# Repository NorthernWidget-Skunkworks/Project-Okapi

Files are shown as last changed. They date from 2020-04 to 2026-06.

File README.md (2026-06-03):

# Okapi: Data logger with integrated solar charging and modular telemetry


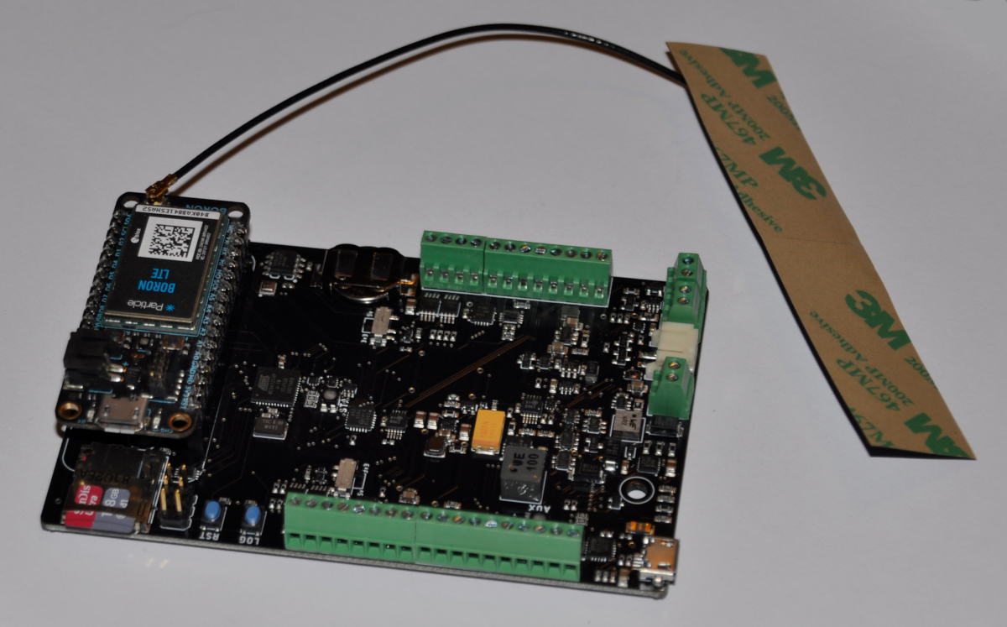
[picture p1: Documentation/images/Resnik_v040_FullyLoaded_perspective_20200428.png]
Project Okapi Data Logger.


***Okapi data logger (Resnik v0.4.0), with a micro-SD card for local storage and a Particle Boron telemetry module.***

The **Okapi** data logger responds to the need for a robust, flexible, and power-efficient open-source option to record and transmit data from remote locations. It is programmable using the open-source standard Arduino framework via a standard micro-USB cable and supports a wide range of sensor input/output options. It connects to dual power supplies to ensure consistent recordings, and interfaces with a range of “Feather”-form-factor boards for telemetry.

## Namesake

The Okapi, a relative of the giraffe, communicates over long distances using [infrasound](https://en.wikipedia.org/wiki/Infrasound). The telemetry capabilities of this data logger inspired this namesake.

Okapi

## Technical specifications

### Electronic Hardware

* Microcontroller (computer) core
  * ATMega1284p
  * Arduino compatible
  * Programmable using C++
  * 8 MHz
* Real-time clock
  * DS3231M
  * Temperature-compensated crystal for high accuracy (±5 ppm)
* Sensor and general-purpose connections
  * Primary Rail (selectable 3.3V or 5V)
    * I2C (up to 128 sensors permitted; expansion ports provided by Project Heptapod)
    * SPI
    * 2x 16-bit analog
    * Analog voltage reference
    * 12-bit Digital-to-analog conversion
    * 2x General-purpose input/output
    * USART
    * 2x Vbus (selectable 3.3V or 5V)
    * 2x Ground
  * Secondary Rail (selectable 3.3V or 5V)
    * I2C (up to 128 sensors permitted; expansion ports provided by Project Heptapod)
    * 2x 16-bit analog
    * 2x General-purpose input/output
    * USART
    * 2x Vbus (selectable 3.3V or 5V)
    * 2x Ground
* Data storage and return
  * Local storage: micro SD card
  * Telemetry: support for Feather-profile boards, including Particle devices:
    * Mobile phone networks
    * WiFi
    * Bluetooth
    * [In development] Iridium satellite
* Power
  * Dual power supply
  * Primary Power
    * Built-in maximum-power-point-tracking solar-charge-control circuitry
    * Lithium-Ion battery
  * Backup Power
    * Alkaline AA batteries
  * Real-time clock
    * Coin cell
  * Power consumption
    * Primary power, sleeping: 80 μA
    * Backup power, sleeping: 4 μA
    * Active (typical: data logger without sensors): 10 mA
    * Transmitting (mobile networks, typical: Particle Boron):
      * 16 mA background
      * 40 mA burst
  * Power generation
  * Solar, low light: 100 mA
* User interface
  * “Log” button: instantaneous reading (for testing)
  * “Reset” button
  * 2x 3-color indicator LEDs
  * Computer readout via a serial monitor, included in the Arduino software
* Open-source licensing via CC BY-SA 4.0

>> @bschulz1701: Any updates needed? I think that there is also a WDT (correct?)

### Electronic Software and Firmware

* Programmable using the Arduino IDE https://www.arduino.cc/en/main/software
* Custom bootloader and board definition for ATMega1284p available via https://github.com/NorthernWidget/Arduino_Boards
* Custom libraries from Northern Widget and the open-source community
  * Primary data-logger functions
  * Libraries available with each sensor, exposing a standard interface
* Open-source licensing via GNU GPL 3.0

### Pinout and board interfaces

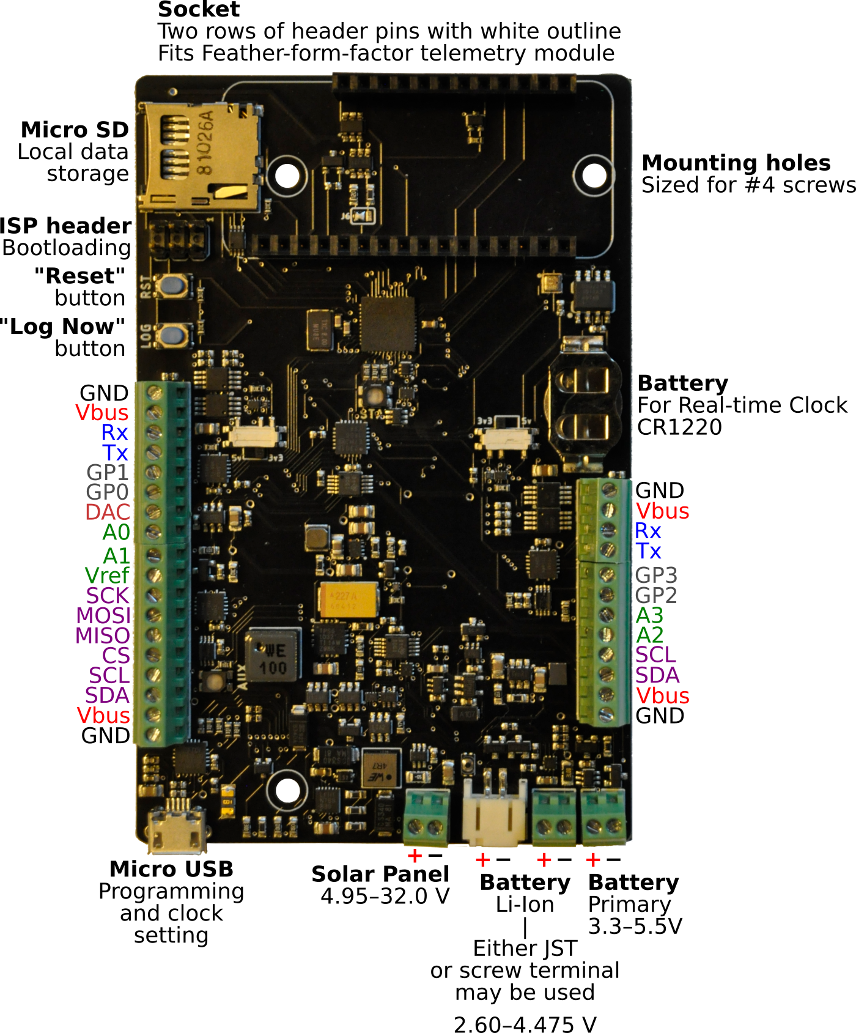
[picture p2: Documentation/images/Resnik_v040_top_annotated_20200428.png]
Data logger with pins, connectors, and interactive items annotated.


***Okapi data logger (Resnik v0.4.0) with pins, connectors, and interactive items annotated.***

**Pins are colored following this convention:**
* Ground: black
* Power supply: red
* Universal Serial Asynchronous Receiver--Transmitter (USART or UART): blue
* General-purpose I/O pins: gray
* Analog inputs and associated reference voltage: green
* Digital communications buses (SPI and I2C): purple
* Analog adjustable voltage output: salmon

**The power and programming connectors at the "south" end of the board are as follows:**
* Micro-USB connector
  * The same connector as many Android and other mobile phones at the time of writing; may be programmed using any USB cable for these that is not charging-only (i.e. that can carry data)
  * Can be used with our [clock-setting program](https://github.com/NorthernWidget/SetTime_GUI) to set the time on the real-time clock.
  * Provides power to the data logger while it is connected; this power source is isolated from the batteries and solar panel, and therefore may be plugged in safely at any time.
* Solar panel, 4.95--32.0 V. A wide range of panels can work with this.
* Li-Ion battery, 2.60--4.475 V. This works with standard 18650 Li-ion batteries. It can work well with just a single battery, but if more storage is required, multiple 18650 batteries may be connected in parallel; we have a circuit-board design to do this: https://github.com/NorthernWidget/LiIon-18650-Parallel. ***CAUTION***: most commercially available multiple-18650-battery holders connect them in series; this voltage is ***TOO HIGH*** for the data logger.
* Primary batteries. This is ideally a pack of 3 primary (i.e., not reusable) Alkaline (or better) AA batteries with a long shelf life. The Okapi data logger will switch to these if its rechargeable power supply shuts down. The internal electronics reduce the quiescent power consumption while under backup power (see the above list of [electronic hardware technical specifications](#electronic-hardware)) and inform the logger about which power supply is being used, allowing it to, for example, reduce or temporarily terminate data transmission.

>> @bschulz1701: Solar panel supply current / size?

**"RST" and "LOG" buttons:**
* Reset ("RST"): stop the program that is currently executing on the main logger and return it to its boot sequence.
* Log Now ("LOG"): take a reading immediately. This is useful for diagnoses and testing.

>> General note: we may want to have an LED flash whenever the logger takes a reading -- even for 1/10 of a second. With an option to disable this, of course. But it is often better to know while in the field that a system is working

**Other notes, clockwise from the top:**
* The socket holds a [Feather-form-factor board](https://learn.adafruit.com/adafruit-feather/feather-specification).
  * This standard, designed by [Adafruit](https://www.adafruit.com/), has been widely adopted, including by the IoT/telemetry module designer [Particle](https://www.particle.io/).
  * We often use a [Particle Boron mobile-phone telemetry unit](https://docs.particle.io/boron/).
* Mounting holes for [\#4 screws](https://www.mcmaster.com/91772A106/)
* CR1220 battery; can power the real-time clock for up to 7 years
* ISP header (also called an ICSP header): This 3x2 header is used with an in-system programmer (in-circuit system programmer) to upload the (bootloader)[#installing-the-bootloader] to the data logger.
* A micro-SD card holds a copy of all data, whether or not any telemetry is used

>> @bschulz1701: check my clock 7-year figure

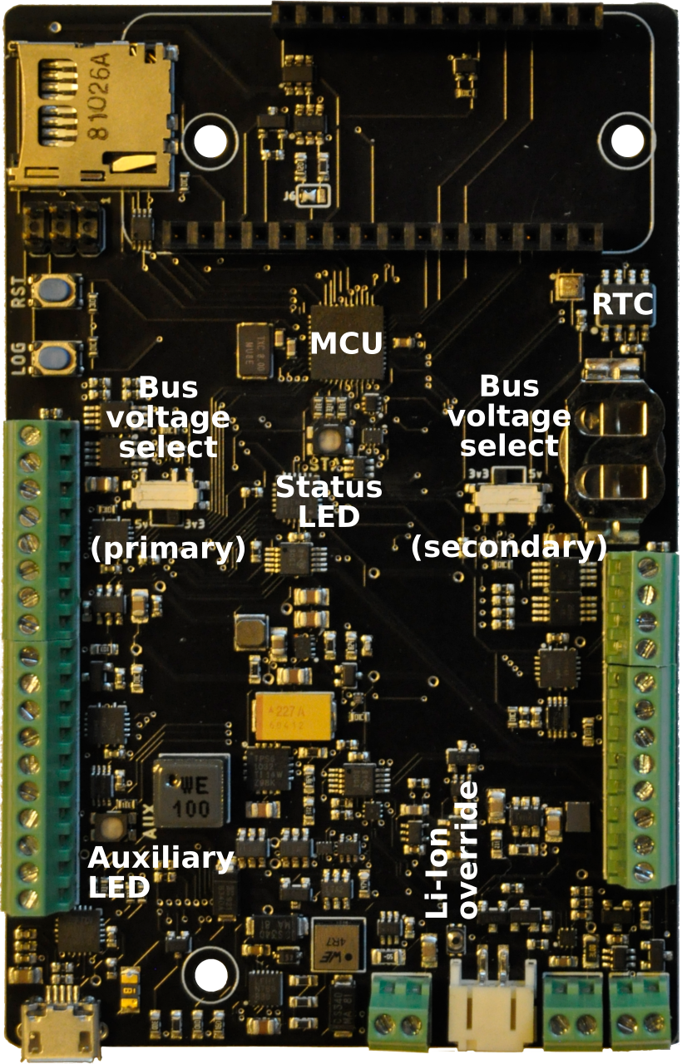
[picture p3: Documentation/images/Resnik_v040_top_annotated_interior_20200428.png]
Data logger with key microchips, LEDs, and switches marked.


***Okapi data logger (Resnik v0.4.0) with key microchips, LEDs, and switches marked.*** *MCU: Microcontroller. RTC: Real-time clock. LED: Light-emitting diode. Bus: a subsystem for connections and data transfer.*

The Okapi data logger contains two buses (see above), each of which has an independent voltage. The primary bus is on the left and the secondary bus is on the right. These can be selected as 3.3V (switches slid towards the inside of the board) or 5V (switches towards the outside of the board).

>> @bschulz1701: How much power can each bus source/sink?

Two LEDs, status and auxiliary, flash messages to the user to provide information on proper operations vs. a variety of possible errors. These are useful for field diagnoses, and are further described in [the field guide section, below](#field-guide).

>> Design note: move STAT label to left of LED so it can be better seen

The Li-ion override button, which can be pressed with the tip of a pen or other small object, ...

>> @bschulz1701: This somehow overrides the Li-Ion battery electronics to allow something to happen... but I am not remembering what!

## On-board Devices

### I2C

| **Device** 	| **Default address** 	| **Reprogrammable address** 	| **Function** 	|
|---	|---	|---	|---	|
| [DS3231](https://github.com/NorthernWidget/DS3231_Logger) 	| 0x68 	| N 	| Real-time clock 	|
| [MCP23018](https://github.com/NorthernWidget-Skunkworks/MCP23018) 	| 0x20 	| N 	| I/O Expander 	|
| [ADS1115](https://github.com/adafruit/Adafruit_ADS1X15) 	| 0x48 	| N 	| ADC (on-board devices) 	|
| [ADS1115](https://github.com/adafruit/Adafruit_ADS1X15) 	| 0x49 	| N 	| ADC (off-board devices) 	|
| [MCP4725](https://github.com/NorthernWidget-Skunkworks/MCP4725) 	| 0x62 	| N 	| DAC 	|
| [BME280](https://github.com/NorthernWidget/BME_Library) 	| 0x77 	| N 	| On-board barometric pressure, temperature, and relative humidity 	|

### SPI

* SD Card

### UART (USART)

* FTDI USB-Serial converter
* Feather form-factor telemetry board; typically [Particle Boron](https://docs.particle.io/boron/)

## Assembly

Assembling this data logger is possible by hand with sufficient skill and the following tools:
* Temperature-controlled soldering iron
* Hot-air rework station
* Equipment for stenciling with solder paste
* ESD-safe tweezers and workstation
* Solder wick

Mechanized assembly by a professional circuit-board assembly house, which is available in many parts of the world, may be preferred due to the complexity of this data logger board.

>> THOUGHT: I have basic instructions for assembly on the [Project Walrus](https://github.com/NorthernWidget-Skunkworks/Project-TPDH-Walrus) README; I will not reproduce these here just yet, as we might want to set up a separate assembly guide, mostly with good links to existing resources, since our writing something of this nature would be to reinvent the wheel.

## Programming

### Downloading and installing the Arduino IDE

Go to https://www.arduino.cc/en/main/software. Choose the proper IDE version for your computer. For Windows, we suggest the non-app version to have more control over Arduino; this might change in the future. You will have to add custom libraries, so the web version will not work (at least, as of the time of writing). Download and install the Arduino IDE. Open it to begin the next steps.

### Installing the bootloader

Before a data logger can receive programs via the convenient USB port, it must have a *bootloader* that tells it to expect to receive new programs that way.  You can read more about bootloaders in general here: https://www.arduino.cc/en/Hacking/Bootloader.

Because you can't upload the bootloader via USB, you use the 2x3-pin 6-pin ICSP (also called ISP) header with a special device called an "in-circuit system programmer" (or just "in-system programmer; yup, that's what the acronym stands for).

Many devices exist to upload a bootloader including:
* The official [AVR ISP mkII](http://ww1.microchip.com/downloads/en/DeviceDoc/Atmel-42093-AVR-ISP-mkII_UserGuide.pdf) (no longer produced but available used)
* Using an [Arduino as an ISP](https://www.arduino.cc/en/tutorial/arduinoISP)
* The versatile [Olimex AVR-ISP-MK2](https://www.olimex.com/Products/AVR/Programmers/AVR-ISP-MK2/open-source-hardware)
* The [Adafruit USBtinyISP](https://www.adafruit.com/product/46)

To upload the bootloader, do the following:

1. Open the Arduino IDE. If you have not yet installed the Northern Widget board definitions, find and install them here (instructions provided): https://github.com/NorthernWidget/Arduino_Boards
2. Select the desired board -- most likely ***ATMega1284p 8MHz*** under *Northern Widget Boards*.
3. Plug the data logger into your computer via a micro-USB cable to provide power.
4. Plug your ISP of choice into your computer (via a USB cable) and onto the 6-pin header. There are two ways to place it on; the header is aligned such that the ribbon cable should be facing away from the board while programming. If this fails without being able to upload, try flipping the header around.
5. Go to Tools --> Programmer and select the appropriate programmer based on what you are using.
6. Go to Tools --> Burn bootloader. Typically, within a few seconds, you learn whether you succeeded or failed. Hopefully it worked!

***Important note for Linux users:*** You must supply permissions to the Arduino IDE for it to be able to use the ICSP, or you will have to run it using `sudo`. The former option is better; the latter is easier in the moment.

***Note: Be sure to download and/or update drivers for your ISP.***

### Installing the requisite software libraries

>> @awickert: Add a full list of the requisite software to install; finish the firmware aggregator and use those directions (or the Arduino ones) to help users install that + sdfat. Include screenshots and host those directions at https://github.com/NorthernWidget-Skunkworks/Firmware-Aggregator.

### How to write a program

The below program is an example that you can copy and paste directly into the Arduino IDE in order to upload to your data logger. We'll walk you through what each piece of the code is and does.

#### Full program
```c++
/*
 * Okapi example: connected with a Walrus pressure--temperature sensor, often
 * used for water-level measurements, via the Longbow I2C/RS-485 translator.
 * Written by Bobby Schulz with a few comments added by Andy Wickert.
 */

#include "Okapi.h"
#include <TP_Downhole_Longbow.h>

TP_Downhole_Longbow Walrus; // Instantiate Walrus sensor; relict library name
Okapi Logger; // Instantiate data logger object

String Header = ""; // Information header; starts as an empty string
uint8_t I2CVals[1] = {0x22}; // I2C addresses of sensors

unsigned long UpdateRate = 60; // Number of seconds between readings

void setup() {
  Header = Header + Walrus.GetHeader();
  Logger.begin(I2CVals, sizeof(I2CVals), Header); // Pass header info to logger
  Init();
}

void loop() {
  Logger.run(Update, UpdateRate);
}

String Update()
{
  Init();
  delay(1500);
  return Walrus.GetString();
}

void Init()
{
  Walrus.begin(13, 0x22); // Instantiate Walrus (at address = 13)
                          // and Longbow Widget (at address = 0x22)
}
```

#### "Include" statements

```c++
#include "Okapi.h"
#include <TP_Downhole_Longbow.h>
```

These bring in the two code libraries involved, the former for the data logger and the latter for the sensors. This allows the user to access the classes and functions within these two libraries, as we will show in more detail below.

#### Instantiate a sensor object

```c++
TP_Downhole_Longbow Walrus; // Instantiate Walrus sensor; relict library name
Okapi Logger; // Instantiate data logger object
```

"Instantiating an object" means that we create our own specific versions of the a class of items. This can be thought of as: `Breakfast myBreakfast`. Breakfast is the general concept, but I create "myBreakfast", which I can then modify. In this same way, "Logger" is what we call our Okapi data logger, and "Walrus" is what we call our "TP_Downhole_Longbow" sensor; this name is a holdover from an earlier design that is the ancestor of the Walrus. We can then access functions and variables within these two instantiated objects.

#### Declare the header string

```c++
String Header = ""; // Information header; starts as an empty string
```

We start with an empty header, but will soon add information to it.

#### Create a list of the I2C addresses of the sensors

```c++
uint8_t I2CVals[1] = {0x22}; // I2C addresses of sensors
```

This is the trickiest step. You need to know what the I2C address of your sensor is. You can skip this, but then the logger will not run a check to see if the sensor is properly connected.

>> Let's make sure that we record this one each page, or find a way to replace this.

#### Declare the amount of time between logging events

```c++
unsigned long UpdateRate = 60; // Number of seconds between readings
```

This is the number of seconds between logging events. If it takes 2 seconds to record data, make sure that you give the logger at least 3 seconds between events. The maximum logging time is set by the watchdog timer, which [FINISH HERE]

>> @BSCHULZ1701: Is there an external WDT on Okapi?

#### `setup()` step: runs once at the start

```c++
void setup() {
  Header = Header + Walrus.GetHeader();
  Logger.begin(I2CVals, sizeof(I2CVals), Header); //Pass header info to logger
  Init();
}
```

`setup()` is a special function that runs just once when the logger boots up. In this case, it first adds the Walrus' header to the header string. `GetHeader()` is a standard function that lies within each of our sensor libraries and returns this header information as a `String`. We then pass the header and the I2C values to the Okapi library's `begin()` function. This sets up the header and prepares the data loger to record data. Finally, this function calls `Init()`, which we skip ahead to describe immediately below.

>> (awickert): I still don't understand why we have to pass `sizeof()` and can't just compute that within the function.

#### `Init()` function: skipping ahead to understand `setup()`

```c++
void Init()
{
  Walrus.begin(13, 0x22); // Instantiate Walrus (at address = 13)
                          // and Longbow Widget (at address = 0x22)
}
```

The `Init()` function calls the `begin()` function, standard within each Northern Widget sensor library, to instantiate the connection ports (e.g., I2C, RS-485) used to communicate between the sensor and the logger. In this case, there is only one sensor, but two ports are needed: An RS-485 signal goes from the Walrus to the Longbow Widget, which then converts the signal into an I2C signal with its own address. The reason for this is that an I2C signal can travel only ~3 m, but an RS-485 signal can travel ~100 m.

#### `loop()` step: keeps running until stopped

```c++
void loop() {
  Logger.run(Update, UpdateRate);
}
```

The loop calls the main function of the Okapi library, `run()`, repeatedly. This puts the logger into a low-power sleep mode and wakes it up only when interrupted by the clock or the "LOG" button. `Update` refers to the function described immediately below. `UpdateRate` is our logging interval defined above.

#### `Update()` function: Gives data for the logger to record

```c++
String Update()
{
  Init();
  delay(1500);
  return Walrus.GetString();
}
```

The `Update()` function first calls the `Init()` function to be sure that the sensor is ready to log. It then in this case delays 1500 milliseconds; this is an ad-hoc solution to the question of how long it takes the pressure transducer to settle after being started up, and is a safe large amount of time. This function then can `return` a string of all of the Walrus' readings (one pressure and two temperature measurements) separated by commas. This is then concatenated to a list of logger-internal measurements -- date/time; on-board temperature, pressure, and relative humidity; and onboard voltages for battery and solar-panel status -- and recorded to the SD card. If telemetry were present, these data could also be sent to a remote location.

### Reference

A full index of the public variables and functions within the Okapi data logger library is available at https://github.com/NorthernWidget/Okapi_Library.

>> Send user to library page

>> Thoughts: We should make all comments compatible with doxygen (following) what I did with the ALog library. It also looks like TravisCI has support for Arduino(!) This means that we could also automate construction of the documentation for these libraries.

### Integration with Particle Boron

>> @bschulz1701?

## Wiring

>> Example needed

## Power supply

* **Lithium-ion 18650 rechargeable batteries**; this board can hold two in parallel: https://github.com/NorthernWidget/LiIon-18650-Parallel
* **Solar panel**. A wide range is acceptable, but we like [Voltaic Systems' 6-watt panel](https://voltaicsystems.com/6-watt-panel/). If you do not want to snip off the barrel jack, [this extension plug from Adafruit should work](https://www.adafruit.com/product/2788) (though we have not tested it... and you'll also have to cut *it* in half).
* **Primary alkaline batteries**; we typically use three high-quality (e.g., Duracell) AAs. These are the backup power supply, and we place them in a [3xAA holder (in series for the proper voltage) with a switch](https://www.jameco.com/z/SBH-331-AS-R-3x-AA-Battery-Holder-with-Cover-and-Switch_216144.html).

>> @bschulz1701: new smarter 18650 holder?

## Housing

The below suggestions encompass what we use and suggest for the housing. In the end, any sufficiently waterproof enclosure will work.

### Materials

* **Enclosure**: [PolyCase WH-16-03 outdoor-rated hinged enclosure](https://www.polycase.com/wh-16)
* **Cable glands**: [RDC07AA](https://www.elecdirect.com/catalogsearch/result/?q=RDC07AA). One per sensor, plus one for the solar panel.
>> AW: Photo didn't take; look up
* **Fasteners**
  * [M5-0.8 x 10 mm truss head screws](https://www.mcmaster.com/92467A320/) x4 to attach mounting plate to threaded inserts in the enclosure
  * [\#4-40 x 1/4 in pan head screws](https://www.mcmaster.com/91772A106/) x22 to attach Okapi, battery packs, and mounting plate to standoffs
  * [\#4-40 x 2 in Female Threaded Hex Standoffs](https://www.mcmaster.com/91115A173/) x3 to stand off Okapi from mounting plate
  * [\#4-40 x 1/2 in Female Threaded Hex Standoffs](https://www.mcmaster.com/91920A533/) x8 to stand off AA battery pack and Li-Ion battery pack from mounting plate
* **Mounting plate for Okapi** (Milled, ABS)
  * [Mounting Plate Design](Mounting%20Plate)
* **Power**
>> Solar panel
  * [3x AA battery pack BK-1280-PC6](https://www.digikey.com/en/products/detail/mpd-memory-protection-devices/BK-1280-PC6/1640076) for alkaline battery backup, mounting holes included for #4-40 screws
>> Li-Ion battery and holder

### Tools

* CNC mill and/or drill press
* Deburring tool or knife + skill and patience
* Torque wrench(es) for 1.0, 1.2 N m

### Assembly

>> Guide with photos. Perhaps ask @superchap123 to use his CNC

>> Placeholder for Now

>> Also include information on passing wiring through

## Field operator's guide

### Initialize
1. Ensure that all connections are secure and SD card is inserted
2. Turn battery pack on
3. Wait for GREEN - GREEN - 5x Blue Flash
	- If you see this, the logger is properly recording data. To double-check, go to "Check"
	- If you see a different flash pattern, go to "Error"

### Check
1. After going through "Initialize", wait 2-3 minutes
2. Follow the instructions in the "Download" section
3. Check to make sure that all the data are being recorded at the proper (UTC) time
4. Check that valid values are being recorded for sensors
7. Whether or not files are properly recorded, return to "Initialize"
	- If files are not recorded, replace the SD card, check all connections, turn the logger back
	  on, and try again
	- If there is an issue with a specific sensor, check connections and troubleshoot
	- If files are recorded properly, return to Initilaize and do not return to "Check"

### SD card swap
1. Turn battery pack off
2. Remove SD card. Ensure that it is labeled. Put it somewhere safe and memorable
3. Replace the SD card with an equivalently labeled SD card
4. Go to "Initialize"

### Download
1. Turn battery pack off
2. Remove SD card
3. Insert SD card in computer
4. Navigate in the SD card to the most recent "log" file (NW→<serial_number>→Log<number>.txt)
5. Save the data file in a well-labeled and organized place.
6. Safely eject the SD card from the computer
7. Go to "Initialize"

### Error

#### Status Codes

The first LED (AUX) will turn green so long as power is applied.
The second LED (STAT) will have one of the colors below.

**Green:**: All systems check out OK, logging will proceed

**Orange:**: A sensor system is not registering properly, some sensor data may be missing or incorrect
* Verify correct polarity of sensor connection
* Ensure the right sensor is connected
* Verify the screw terminals are well connected to the wires (a loose connection can cause a failure)
* Make sure battery power is applied, some sensors can fail otherwise

**Cyan:**: Clock time is incorrect, but logger is otherwise working correctly
* Connect the logger to a computer and reset the clock using the Northern Widget Time Set GUI
* Start Processing
* Open the Northern Widget Time Set program
* Note and record the wrong time if the logger has been out in the field, alongside the current (correct) time, to correct the prior measurements
* Click the "set time" button and check that you are <3 seconds off of the correct time
* Click the "close" button

**Pink**: (looks like purple to some people): SD card is not inserted
* Insert the SD card, or remove and re-insert to make sure card is fully seated

**Red**: Critical on board component is not functioning correctly, such as SD card or clock; Logging will likely not be able to proceed
* Attempt power cycle
* Try different SD card
* Disconnect all sensors; reconnect one by one and check

**Yellow, Fast Blinking**: <50% battery capacity
* Replace batteries: turn battery pack off, replace batteries, and turn battery pack back on

**Red, Fast Blinking**: Batteries <3.3V. Voltage too low to properly function
* Replace batteries: turn battery pack off, replace batteries, and turn battery pack back on.

#### General tips to solve many kinds of errors
* Turn the the logger off and on
* Verify the quality of all screw terminal connections by gently tugging on the wires and making sure they stay in place, if not, remove, replace, and re-tighten the connection
* Ensure sensors and/or cables are not damaged, this can result is shorts or other problems
* Make sure batteries have sufficient voltage to run the logger (>3.3 V)

## NW-Device-Specification schema

Okapi's serial number scheme is [Schema 0](https://github.com/NorthernWidget/NW-Device-Specification) — the same 8-byte EEPROM block used by Margay, predating the formal specification. Schema 1 formalizes it as Page 0 and defines a putative Page 1 for the case where Okapi communicates its status to a higher-level device (e.g., the Particle Boron telemetry board). **Okapi has no current peripheral interface; Page 1 is hypothetical.**

Over I²C this would follow the standard register-addressed read. Over UART (the current Okapi↔Boron link) a framing layer is required; see the [NW-Device-Specification transport section](https://github.com/NorthernWidget/NW-Device-Specification) for the Magic Preamble and COBS options.

### Current EEPROM serial number (Schema 0)

Eight bytes at `EEPROM[length−8]` through `EEPROM[length−1]`, big-endian uint16 per field, written by the setup sketch `SN Set` command — identical scheme to Margay:

| Bytes | Field | Example (Okapi v1.0) |
|---|---|---|
| 0–1 | Board type | `0x4F01` (`'O'` = 0x4F, revision 1) |
| 2–3 | Group ID | operator-assigned |
| 4–5 | Unique ID | monotonically increasing |
| 6–7 | FirmwareID | `0x0000` (hardcoded) |

Legacy units manufactured as "Resnik" carry board type `0x9950`.

### Proposed register layout (NW-Device-Specification Schema 1)

**Page 0 (0x00–0x1F) — Identity (EEPROM)**

```
Block 0 (0x00–0x07)   Core identity
  0x00        0x01                          Schema (NW-Device-Specification v1)
  0x01–0x05   'O','k','a','p','i'           Device name (5 bytes)
  0x06–0x07   0x00,0x00                     Reserved

Block 1 (0x08–0x0F)   Version
  0x08        HW major
  0x09        HW minor
  0x0A        FW patch
  0x0B–0x0D   0x00,0x00,0x00               Unused (combined repo convention)
  0x0E–0x0F   0x00,0x00                    Reserved

Block 2 (0x10–0x17)   Serial number
  0x10–0x11   0x4F,0x01                    Board type ('O'=0x4F, revision index)
  0x12–0x13   [manufacture]                Group ID
  0x14–0x15   [manufacture]                Unique ID
  0x16–0x17   0x00,0x00                    FirmwareID (legacy, reserved)

Block 3 (0x18–0x1F)   Integrity + administration
  0x18–0x1C   0x00 ×5                      Reserved
  0x1D        0x00                         Magic byte (reserved; purpose TBD)
  0x1E        [computed]                   CRC-8 of bytes 0x00–0x1D
  0x1F        0x00                         Peripheral address (unassigned;
                                           Okapi is currently controller only)
```

**Page 1 (0x20–0x3F) — Logger status (SRAM) — HYPOTHETICAL**

Okapi is currently an I²C controller communicating with the Particle Boron via UART; it has no peripheral interface. This layout is proposed for the case where Okapi reports status to the Boron (or any higher-level device) using the NW schema. A natural peripheral address would be `0x4F` (ASCII `'O'`).

Okapi's dual power system (LiPo primary + solar charging + AA backup) differs from Margay. Full power monitoring signals are not yet implemented in the library (`GetPowerStats()` is reserved); fields marked TBD will be defined when that work is completed.

```
Block 0 (0x20–0x27)   System status + power
  0x20        Status       bit 0=ready, bit 1=SD fault, bit 2=RTC fault,
                           bit 3=onboard fault, bit 4=sensor fault,
                           bit 5=LiPo warning, bit 6=LiPo error,
                           bit 7=backup warning
  0x21        LiPo %       uint8, 0–100
  0x22–0x23   LiPo voltage uint16, 0.01 V
  0x24–0x25   Solar input  uint16, TBD (V or mW pending GetPowerStats() impl.)
  0x26–0x27   Backup volt  uint16, 0.01 V (AA backup rail)

Block 1 (0x28–0x2F)   BME280 — onboard environment
  0x28–0x29   Temperature  int16, 0.01 °C
  0x2A–0x2B   Humidity     uint16, 0.01 %RH
  0x2C–0x2F   Pressure     uint32, 0.01 hPa

Block 2 (0x30–0x37)   DS3231M — RTC
  0x30–0x33   Timestamp    uint32, Unix time (seconds since 1970-01-01 UTC)
  0x34–0x35   Temperature  int16, 0.01 °C
  0x36–0x37   Reserved

Block 3 (0x38–0x3F)   Logger state
  0x38–0x39   Ext interrupts  uint16, accumulated count
  0x3A–0x3B   Log file #      uint16
  0x3C–0x3F   Log interval    uint32, seconds
```

No Page 2. Calibration constants are hardcoded in the library.

## Development namesake

Designing a large-platform, multi-power-system, and telemetry-enabled data logger is the single most complex task that our group has undertaken. Bobby Schulz, lead engineer, code-named the dev version of this work "Project Resnik", after Dr. Judy Resnik, electrical engineer and astronaut. Although we don't have to manage the complexities of space travel, we think that our design will do pretty well down here on Planet Earth.

Astronaut Dr. Judy Resnik

## Acknowledgments

Support for this project provided by:

UMN ESCI

USGS

WMO

<br/>
<br/>
<br />This work is licensed under a <a rel="license" href="http://creativecommons.org/licenses/by-sa/4.0/">Creative Commons Attribution-ShareAlike 4.0 International License</a>.

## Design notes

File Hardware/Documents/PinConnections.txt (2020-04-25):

Project Resnik Pin Connections

uC	32 GPIO
---
I2C:
	SDA
	SCL
		SDA_CTRL

SPI:
	MOSI 
	MISO
	SCK
		SD_CS

UART:
	TX0
	RX0
	TX1
	RX1

Interrupt:
	Global Interrupt (Input, PCINT)
	LogButton (Input, PCINT)	--PA4 (FIXEDish) //Keep convention w/Margay, not hardcore fixed
	RTCInt (Input, Interrupt)

LEDs:
	AliveLED
	RedLED
	GreenLED
	BlueLED

SD, CardDected (Input)
HP Ctrl, C0 (Output)		--PC2 (FIXED)
HP Ctrl, C1 (Output)		--PC3 (FIXED)
BusPowerSwitch, Primary Bus, EN (Output)	--PC6 (Flex)
BusPowerSwitch, Secondary Bus, EN (Output) 	--PC7 (Flex)

GPIO0, Primary Bus (I/O)	--PD4 (FIXED)
GPIO1, Primary Bus (I/O)	--
GPIO2, Secondary Bus (I/O)	--PB3 (FIXED)
GPIO3, Secondary Bus (I/O)	--

Feather, GPIO 	--PA5
Feather, CTS  	--PA6
Feather, RTS	--PA7

IO Exp	16 GPIO
------
-

Feather PowerOn (Output)
ADC, OnBoard, Alert/RDY (Input, Interrupt)
ADC, OffBoard, Alert/RDY (Input, Interrupt)

LevelShifter, Primary Bus, EN (Output)
LevelShifter, Secondary Bus, EN (Output)
BusPowerSwitch, Primary Bus, Fault (Input)
BusPowerSwitch, Secondary Bus, Fault (Input)

MPPT, CHRG (Input)
MPPT, FAULT (Input)
MPPT, SHDN (Output)
Vusb (Input)
BMS, CTR (Output)
HighPowerBoost, LBO (Input, Interrupt?)
HighPowerBuck, PG (Input)
LowPowerLDO_3v3, PG (Input)

ADC Onboard
-----------

I_MPPT
I_Bat
V_Prime
V_Li

ADC Offboard
------------

A0
A1
A2
A3

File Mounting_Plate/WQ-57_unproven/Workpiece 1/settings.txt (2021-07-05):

Material type: ABS
Material dimensions: 254.99999999999997 mm x 165 mm x 3.175 mm
Bit: 0.0625 in, Upcut

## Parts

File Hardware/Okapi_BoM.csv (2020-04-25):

Qty | Value | Device | Package | Parts | Description | DIGIKEY | DISP | MF | MFP | MOUSER | MPN | PROD_ID | VALUE | VALUE_PART
3 |  | CONN_022.54_SCREW | 1X02_2.54_SCREWTERM | J5, J6, J7 | Genaric 2 terminal header | ED10561-ND |  | OnShore |  |  | OSTVN02A150
1 |  | CONN_102.54_SCREW | 1X10_SCREW | J2 | Genaric 10 terminal header | ED10567-ND |  | On Shore |  |  | OSTVN10A150
1 |  | DIODEDO-214AC | DO214AC | D9 | Genaric Diode | B340A-FDICT-ND |  | Diodes Incorporated |  |  | B340A-13-F
2 |  | DIODEDO-214AC | DO214AC | D1, D3 | Genaric Diode | CMSH3-40MATR13CT-ND |  | Central Semiconductor |  |  | CMSH3-40MA TR13
1 |  | DIODESOD-323 | SOD323-R | D2 | Genaric Diode | CMDSH2-3CT-ND |  | Central Semiconductor |  |  | CMDSH2-3 TR
1 |  | JST_2MM_MALE | JST-2-SMD | J8 | JST 2MM MALE RA CONNECTOR | 455-1749-1-ND |  | JST |  |  | S2B-PH-SM4-TB(LF)(SN)
2 |  | LM40402.5 | SOT23-3 | D6, D7 | LM4040 - Precision Micropower Shunt Voltage Referance | 576-1047-1-ND |  | Microchip |  |  | LM4040DYM3-2.5-TR
1 |  | LT3652DD | DFN_12_3X3 | U4 | LT3652 - Power Tracking Battery Charger for Solar Power (MPPT) | LT3652EDD#PBF-ND |  | LT |  |  | LT3652EDD#PBF
3 |  | MOUNTING_HOLE4_NP | 4_40 | H1, H2, H3 | Genaric Mechanical Mounting Hole
1 |  | R-EU_10KR0402 | R0402 | R54 | RESISTOR, European symbol | 311-10.0KHRCT-ND |  | Yageo |  |  | RC0603FR-0710KL |  |  | 10k
19 | 0.1uF | C-EU0.1UFC0402 | C0402 | C12, C17, C21, C25, C26, C27, C28, C29, C31, C32, C33, C34, C35, C36, C37, C38, C39, C44, C45 | CAPACITOR, European symbol | 490-4759-1-ND |  | Murata |  |  | GCM155R71C104KA55D
2 | 0.22uF | C-EU0.22UFC0402 | C0402 | C15, C16 | CAPACITOR, European symbol | 490-12265-1-ND |  | Murata |  |  | GRT155R61E224KE01D
2 | 1.62M | R-EU_1.62MR0603 | R0603 | R2, R4 | RESISTOR, European symbol | RMCF0603FT1M62CT-ND |  | Stackpole |  |  | RMCF0603FT1M62 |  |  | 1.62M
1 | 100R | R-EU_100R0402 | R0402 | R14 | RESISTOR, European symbol | 311-100LRCT-ND |  | Yageo |  |  | RC0402FR-07100RL |  |  | 100
6 | 100k | R-EU_100KR0402 | R0402 | R23, R57, R58, R60, R61, R63 | RESISTOR, European symbol | 311-100KLRCT-ND |  | Yageo |  |  | RC0402FR-07100KL |  |  | 100k
1 | 100k | R-EU_100KR0603 | R0603 | R69 | RESISTOR, European symbol | RC0402FR-071ML |  | Yageo |  |  | RC0603FR-07100KL |  |  | 100k
1 | 100uF | CTANT_EU1206 | C1206_TANT | C43 | Genaric Tantalum Capacitor | 718-1921-1-ND |  | Vishay Sprague |  |  | TL8A0107M010D
8 | 10k | R-EU_10KR0402 | R0402 | R24, R25, R41, R45, R46, R47, R52, R67 | RESISTOR, European symbol | 311-10.0KHRCT-ND |  | Yageo |  |  | RC0603FR-0710KL |  |  | 10k
2 | 10k | R-EU_P10KR0603 | R0603 | R49, R50 | RESISTOR, European symbol | P10KDBCT-ND |  | Panasonic |  |  | ERA-3AEB103V |  |  | 10k
5 | 10uF | C-EU10UFC0805 | C0805 | C3, C4, C14, C22, C30 | CAPACITOR, European symbol | 490-6473-6-ND |  | Murata |  |  | GRM21BR61C106KE15K
1 | 10uH | INDUCTORXHMI_6.65X6.45 | WE-XHMI(6.65X6.45) | L2 | Genaric inductor | 732-10707-1-ND |  | Wurth |  |  | 74439346100
1 | 120k | R-EU_120KR0402 | R0402 | R19 | RESISTOR, European symbol | 311-120KLRCT-ND |  | Yageo |  |  | RC0402FR-07120KL |  |  | 120k
2 | 12pF | C-EU12PFC0402 | C0402 | C23, C24 | CAPACITOR, European symbol | 445-5585-1-ND |  | TDK |  |  | CGA2B2C0G1H120J050BA
2 | 12pF | C-EU12PFC0402 | C0402 | C40, C41 | CAPACITOR, European symbol | 1276-1254-1-ND |  | Samsung |  |  | CL10C120JB8NNNC
1 | 130k | R-EU_130KR0603 | R0603 | R20 | RESISTOR, European symbol | 311-130KHRCT-ND |  | Yageo |  |  | RC0603FR-07130KL |  |  | 130k
1 | 143k | R-EU_143KR0603 | R0603 | R22 | RESISTOR, European symbol | 311-143KHRCT-ND |  | Yageo |  |  | RC0603FR-07143KL |  |  | 143k
2 | 180k | R-EU_180KR0402 | R0402 | R65, R66 | RESISTOR, European symbol | 311-180KLRCT-ND |  | Yageo |  |  | RC0402FR-07180KL |  |  | 180k
4 | 180k | R-EU_180KR0603 | R0603 | R1, R5, R7, R8 | RESISTOR, European symbol | P180KHCT-ND |  | Panasonic |  |  | ERJ-3EKF1803V |  |  | 180k
1 | 182k | R-EU_182KR0603 | R0603 | R13 | RESISTOR, European symbol | P182KHCT-ND |  | Panasonic |  |  | ERJ-3EKF1823V |  |  | 182k
6 | 1M | R-EU_1MR0402 | R0402 | R53, R55, R56, R59, R64, R68 | RESISTOR, European symbol | 311-1.00MLRCT-ND |  | Yageo |  |  | RC0402FR-071ML |  |  | 1M
1 | 1M | R-EU_1MR0603 | R0603 | R71 | RESISTOR, European symbol | P1.00MHCT-ND |  | Panasonic |  |  | ERJ-3EKF1004V |  |  | 1M
1 | 1k | R-EU_1KR0402 | R0402 | R12 | RESISTOR, European symbol | 311-1.00KLRCT-ND |  | Yageo |  |  | RC0402FR-071KL |  |  | 1k
1 | 1uF | C-EU0.1UFC0402 | C0402 | C42 | CAPACITOR, European symbol | 1276-6524-1-ND |  | Samsung |  |  | CL10B105MO8NNWC
2 | 1uF | C-EU1UFC0603 | C0603 | C11, C13 | CAPACITOR, European symbol | 490-10479-1-ND |  | Murata |  |  | GRM188R61C105KA12D
1 | 1uH | INDUCTORLQS_3X3 | WE-LQS(3X3) | L3 | Genaric inductor | 732-5491-1-ND |  | Wurth |  |  | 74404032010
1 | 20 | R-EU_20R0402 | R0402 | R11 | RESISTOR, European symbol | 311-20LRCT-ND |  | Yageo |  |  | RC0402FR-0720RL |  |  | 20
1 | 200k | R-EU_200KR0603 | R0603 | R70 | RESISTOR, European symbol | 311-200KHRCT-ND |  | Yageo |  |  | RC0603FR-07200KL |  |  | 200k
1 | 20k | R-EU_20KR0603 | R0603 | R51 | RESISTOR, European symbol | 311-20.0KHRCT-ND |  | Yageo |  |  | RC0603FR-0720KL |  |  | 20k
1 | 220uF | CTANT_EU2917 | C2917 | C5 | Genaric Tantalum Capacitor | 478-5408-1-ND |  | AVX |  |  | TPSY227K010R0100
7 | 22uF | C-EU22UFC0805 | C0805 | C2, C7, C8, C9, C10, C19, C20 | CAPACITOR, European symbol | 490-9952-1-ND |  | Murata |  |  | GRM219R61C226ME15L
2 | 27 | R-EU_27R0402 | R0402 | R34, R35 | RESISTOR, European symbol | YAG3086CT-ND |  | Yageo |  |  | RC0402FR-0727RL |  |  | 27
4 | 287R | R-EU_232R0402 | R0402 | R26, R27, R28, R29 | RESISTOR, European symbol | YAG3063CT-ND |  | Yageo |  |  | RC0402FR-07232RL |  |  | 232
4 | 287R | R-EU_453R0402 | R0402 | R30, R31, R32, R33 | RESISTOR, European symbol | YAG3165CT-ND |  | Yageo |  |  | RC0402FR-07453RL |  |  | 453
3 | 2N7002 | MOSFET-NCH-2N7002PW | SOT323 | Q4, Q7, Q8 | N-channel MOSFETs | 2N7002W-FDICT-ND |  | Diodes Incorporated |  |  | 2N7002W-7-F | TRANS-11151 | 2N7002
1 | 2k | R-EU_2KR0402 | R0402 | R15 | RESISTOR, European symbol | 311-2KLRCT-ND |  | Yageo |  |  | RC0402FR-072KL |  |  | 2k
2 | 330 | R-EU_330R0402 | R0402 | R37, R39 | RESISTOR, European symbol | 311-330HRCT-ND |  | Yageo |  |  | RC0603FR-07330RL |  |  | 330
1 | 330 | R-EU_330R0402 | R0402 | R9 | RESISTOR, European symbol | 311-330LRCT-ND |  | Yageo |  |  | RC0402FR-07330RL |  |  | 330
6 | 330 | R-EU_330R0402 | R0402 | R36, R38, R40, R42, R43, R44 | RESISTOR, European symbol | 311-330LRCT-ND |  | Yageo |  |  | RC0603FR-07330RL |  |  | 330
1 | 10k | R-EU_10K0603 | R0603 | R48 | RESISTOR, European symbol | 311-10.0KHRCT-ND |  | Yageo |  |  | RC0603FR-0710KL |  |  | 10k
2 | 330k | R-EU_330KR0603 | R0603 | R17, R62 | RESISTOR, European symbol | P330KHCT-ND |  | Panasonic |  |  | ERJ-3EKF3303V |  |  | 330k
1 | 360k | R-EU_360KR0603 | R0603 | R3 | RESISTOR, European symbol | 311-360KHRCT-ND |  | Yageo |  |  | RC0603FR-07360KL |  |  | 360k
1 | 3m | R-EU_0.003R0805 | R0805 | R10 | RESISTOR, European symbol | RHM.003AJCT-ND |  | Rohm |  |  | PMR10EZPFV3L00
1 | 4.7uF | C-EU4.7UFC0805 | C0805 | C1 | CAPACITOR, European symbol | 399-7415-1-ND |  | Kemet |  |  | C0805C475K4RACTU
1 | 4.7uH | INDUCTORMAIA_4.1X4.1 | WE-MAIA(4.1X4.1) | L4 | Genaric inductor | 732-11316-1-ND |  | Wurth |  |  | 78438356047
1 | 470k | R-EU_470KR0603 | R0603 | R21 | RESISTOR, European symbol | 311-470KGRCT-ND |  | Yageo |  |  | RC0603JR-07470KL |  |  | 470k
1 | 50m | R-EU_0.05R0805 | R0805 | R18 | RESISTOR, European symbol | P50LLCT-ND |  | Panasonic |  |  | ERJ-L06KF50MV
1 | 6.8uH | INDUCTOR1008 | 1008 | L1 | Genaric inductor | 732-4849-1-ND |  | Wurth |  |  | 74438323068
1 | 68pF | C-EU68PFC0402 | C0402 | C6 | CAPACITOR, European symbol | 732-7474-1-ND |  | Wurth |  |  | 8.85012E+11
1 | 820k | R-EU_820KR0603 | R0603 | R6 | RESISTOR, European symbol | 311-820KGRCT-ND |  | Yageo |  |  | RC0603JR-07820KL |  |  | 820k
1 | 91k | R-EU_91KR0603 | R0603 | R16 | RESISTOR, European symbol | P91.0KHCT-ND |  | Panasonic |  |  | ERJ-3EKF9102V |  |  | 91k
2 | ADS1115 | ADS1115 | VSSOP_10 | U32, U33 | ADS1115 - Sigma Delta ADC | 296-38849-1-ND |  | TI |  |  | ADS1115IDGSR
1 | ATMEGA1284M | ATMEGA1284M | MLF44-TH | IC1 | 8-bit Microcontroller with 128K Bytes In-System Programmable Flash | ATMEGA1284P-MURCT-ND |  | Atmel |  |  | ATMEGA1284P-MUR
1 | AVRISP-6 | AVRISP-6 | AVRISP | ISP1 | AVR ISP HEADER | 609-3234-ND |  | Amphenol |  |  | 67997-206HLF
1 | BAT54C | BAT54C | SOT23-3 | D8 | BAT54C | BAT54CLT1GOSCT-ND |  | ON Semiconductor | BAT54CLT1G
1 | BATTERY_COIN12MM | BATTERY_COIN12MM | LINX_BAT-HLD-012-SMT | BT1 | Coin Cell Battery Holder | BAT-HLD-012-SMT-ND |  | Linx |  |  | BAT-HLD-012-SMT
1 | BME280 | BME280 | BME280 | U31 | BME280 - Combined Digital Humidity and Pressure Sensor | 828-1063-1-ND | BME280 | Bosch |  |  | BME280
1 | BQ2980RUG | BQ2980RUG | RUG_S-PQFP-N8 | U5 | BQ2980 - Voltage, Current, Temperature Protectors with an Integrated High-Side NFET (BMS) | 296-47578-1-ND |  | TI |  | 595-BQ298000RUGT | BQ298000RUGT
1 | BUTTON2.6X1.6 | BUTTON2.6X1.6 | SWITCH_2.6X1.6 | S5 | Genaric SPST Pushbutton | P19888CT-ND |  | Panasonic |  |  | EVP-BB2A9B000
2 | BUTTON4.2X3.2 | BUTTON4.2X3.2 | SWITCH_4.2X3.2 | S3, S4 | Genaric SPST Pushbutton | CKN10504CT-ND |  | C&K |  |  | PTS810 SJG 250 SMTR LFS
2 | CLVBA-FKA | CLVBA-FKA | CLVBA-FKA | D4, D5 | Cree RGB LED, Small Package, Common Anode, CLVBA-FKA | CLVBA-FKA-CAEDH8BBB7A363CT-ND |  | Cree |  |  | CLVBA-FKA-CAEDH8BBB7A363
1 | CONN_42.54_SCREW | CONN_42.54_SCREW | 1X04_SCREW | J3 | Genaric 4 terminal header | ED10563-ND |  | On Shore |  |  | OSTVN04A150
2 | CONN_82.54_SCREW | CONN_82.54_SCREW | 1X08_SCREW | J1, J4 | Genaric 8 terminal header | ED10566-ND |  | On Shore |  |  | OSTVN08A150
1 | CRYSTAL8MHZ5X3.2 | CRYSTAL8MHZ5X3.2 | CRYSTAL_5X3.2_2-SMD | XTAL1 | Crystal Oscilator | 887-1740-1-ND |  | TXC |  |  | 7A-8.000MAAE-T
3 | DMG3404 | MOSFET-NCH-DMG3404L | SOT23-3 | Q1, Q2, Q6 | N-channel MOSFETs | DMG3404L-7DICT-ND |  | Diodes Incorporated |  |  | DMG3404L-7 |  | DMG3404
1 | DS3231M | DS3231M | SO08 | RTC1 | DS3231M Real Time Clock | DS3231MZ+-ND |  | Maxim |  |  | DS3231MZ+
2 | FDN360P | MOSFET_PCH-FDN360P | SOT23-3 | Q3, Q5 | P-channel MOSFETs | FDN360PCT-ND |  | Fairchild |  |  | FDN360P |  | FDN360P
1 | FEATHERWINGLAYOUT | FEATHERWINGLAYOUT | FEATHERWING_MIN | MS1
1 | FT231X-Q | FT231X-Q | QFN20 | U23 | FT231x - USB to UART Bridge | 768-1128-1-ND |  | FTDI |  |  | FT231XQ-R
1 | INA211DCK | INA211DCK | DCK_R-PDSO-G6 | U34 | INA21x - Analog Output Current Sense Amplifier | 296-40126-1-ND | INA211 | TI |  |  | INA211BIDCKR
1 | INA213DCK | INA213DCK | DCK_R-PDSO-G6 | U35 | INA21x - Analog Output Current Sense Amplifier | 296-40129-1-ND | INA213 | TI |  |  | INA213BIDCKR
7 | JUMPER-SMT_2_NO_SILK | JUMPER-SMT_2_NO_SILK | SMT-JUMPER_2_NO_SILK | JP1, JP2, JP3, JP4, JP5, JP6, JP7 | Normally open jumper
1 | JUMPER-SMT_3_1-NC_PASTE_SILK | JUMPER-SMT_3_1-NC_PASTE_SILK | SMT-JUMPER_3_1-NC_PASTE_SILK | JP8 | Normally closed solder jumper (1 of 2 connections)
1 | LTC4412S6 | LTC4412S6 | SOT23-6L | U7 | LTC4412 - Low Loss PowerPath Controller (ORing FET Controller) | LTC4412ES6#TRPBFCT-ND |  | LT |  |  | LTC4412ES6#TRPBF
1 | MCP23018QFN | MCP23018QFN | QFN24 | U41 | MCP23018 - I2C I/O Expander, 16 bit wtih interrupt and reset | MCP23018T-E/MJCT-ND |  | TI |  |  | MCP23018T-E/MJ
1 | MCP4726A2SOT-23 | MCP4726A2SOT-23 | SOT23-6L | U30 | MCP4726x - 8/10/12 Bit Digital to Analog Converter | MCP4726A2T-E/CHCT-ND | MCP4726A2 | Microchip |  |  | MCP4726A2T-E/CH
4 | MIC2544MSOP | MIC2544MSOP | MSOP_8 | U17, U18, U19, U20 | MIC2544/48 - Hight Side Load Switch, with Adjustable Current Limit | 576-1738-5-ND |  | Microchip |  |  | MIC2544-1YMM
1 | MIC94094C6 | MIC94094C6 | SC-70_6 | U39 | MIC9409x - Hight Side Load Switch | 576-3492-1-ND | MIC94094 | Microchip |  |  | MIC94094YC6-TR
1 | MICROSDCD | MICROSDCD | MICROSD_CD | SD1 | Micro-SD / Transflash card holder with SPI pinout | WM19093CT-ND |  | Molex |  |  | 5025700893
1 | MICRO_USB_LONGPADS | MICRO_USB_LONGPADS | 10118194-0001LF_10118194-0001LF_LONGER_PADS | USB1 |  | 609-4618-1-ND |  | Amphenol |  |  | 10118194-0001LF
1 | PPTC1.5A | PPTC1.5A | 1206 | F1 | Resettable Fuse PPTC | MF-NSMF150-2CT-ND |  | Bourns |  |  | MF-NSMF150-2
1 | SN74AHC1G86DCK | SN74AHC1G86DCK | DCK_R-PDSO-G5 | U40 | SN74AHC1G86 - XOR, 1 Element, 2 Input | 296-8750-1-ND |  | TI |  |  | SN74AHC1G86DCKR
3 | SN74AUP1G04YFP | SN74AUP1G04YFP | DSBGD_4 | U11, U12, U13 | SN74AUP1G04 - NOT, 1 Element, 1 Input | 296-25196-1-ND |  | TI |  |  | SN74AUP1G04YFPR
3 | SN74AUP2G08DQE | SN74AUP2G08DQE | DQE_R-PX2SON-N8 | U14, U15, U16 | SN74AUP2G08 - AND, 2 Element, 2 Input | 296-25638-1-ND |  | TI |  |  | SN74AUP2G08DQER
1 | SN74AUP3G34DCU | SN74AUP3G34DCU | DCU_(R-PDSO-G8) | U25 | SN74AUP3G34 - Logic Buffer | 296-25595-1-ND |  | TI |  |  | SN74AUP3G34DCUR
1 | SN74LVC1G3157DRL | SN74LVC1G3157DRL | DRL_R-PDSO-N6 | U24 | SN74LVC1G3157 - SPDT Analog Switch | 296-18015-1-ND | SN74LVC1G3157 | TI |  |  | SN74LVC1G3157DRLR
2 | SPDTPCM12 | SPDTPCM12 | PCM12 | S1, S2 | Genaric SPDT switch | 401-2016-1-ND |  | C&K |  |  | PCM12SMTR
2 | TCA9406DCU | TCA9406DCU | DCU_(R-PDSO-G8) | U28, U36 | TCA9406 - I2C Bidirectional 1MHz Logic Level Translator | 296-28109-1-ND |  | TI |  |  | TCA9406DCUR
1 | TLV3691DCK | TLV3691DCK | DCK_R-PDSO-G5 | U37 | TLV3691 - Nanopower Analog Comparator | 296-37910-1-ND |  | TI |  |  | TLV3691IDCKR
1 | TLV61220DBV | TLV61220DBV | DBV_R-PDSO-G6 | U1 | TLV61220 - Low-Input Voltage Step-Up Converter (Boost) | 296-30547-1-ND |  | TI |  |  | TLV61220DBVR
1 | TPL5111DDC | TPL5111DDC | DDC_R-PDSO-G6 | U8 | TPL5111 - Nano-Power System Timer for Power Gating (Watchdog, long period) | 296-46226-1-ND |  | TI |  |  | TPL5111DDCR
1 | TPS2105 | TPS2105 | SOT23-5 | U6 | TPS210x - Power Distribution Switch (OR'ing switch) | 296-10883-1-ND | TPS2105 | TI |  |  | TPS2105DBVR
3 | TPS22917DBV | TPS22917DBV | DBV_R-PDSO-G6 | U10, U21, U22 | TPS22917 - Ultra Low Leakage Load Switch | 296-48370-1-ND |  | TI |  |  | TPS22917DBVT
1 | TPS61032RSA | TPS61032RSA | RSA_S-PVQFN-N16 | U3 | TPS6103x - High Efficiency Synchronous Boost Converter | 296-16662-1-ND | TPS61032 | TI |  |  | TPS61032RSAR
1 | TPS62822DLC | TPS62822DLC | DLC_8 | U2 | TPS6282x - Step Down Converter (Buck) with 1% Accuracy | 296-49512-1-ND | TPS62822 | TI |  | 595-TPS62822DLCR | TPS62822DLCT
1 | TPS79733 | TPS79733 | DCK_R-PDSO-G5 | U9 | TPS797* - Ultra Low Power Low Dropout Linear Regulator | 296-11990-1-ND | TPS79733 | TI |  |  | TPS79733DCKR
1 | TS5A21366RSE | TS5A21366RSE | RSE0008A | U38 | TS5A21366 - 2 Channel SPST Analog Switch | 296-25285-1-ND | TS5A21366 | TI |  |  | TS5A21366RSER
1 | TXS0102DQM | TXS0102DQM | DQM_R-PX2SON-N8 | U26 | TXS0102 - 2 Channel Bidirectional Voltage Level Translator | 296-28435-1-ND |  | TI |  |  | TXS0102DQMR
3 | TXS0104RGY | TXS0104RGY | RGY_S-PVQFN-N14 | U27, U29, U42 | TXS0104 - 4 Channel Bidirectional Voltage Level Translator | 296-20698-1-ND |  | TI |  |  | TXS0104ERGYR
1 |  | CONN_16FEMALE | 1X16 | J8 | Generic 16 terminal header | S7049-ND |  | Sullins |  |  | PPPC161LFBN-RC
1 |  | CONN_12FEMALE | 1X12 | J9 | Generic 12 terminal header | S7045-ND |  | Sullins |  |  | PPPC121LFBN-RC
1 | 4.7UF | C-EU4.7UF0603 | C0603 | C18 | CAPACITOR, European symbol | 490-10481-1-ND |  | Murata |  |  | GRM188R61C475KAAJD |  |  | 4.7uF

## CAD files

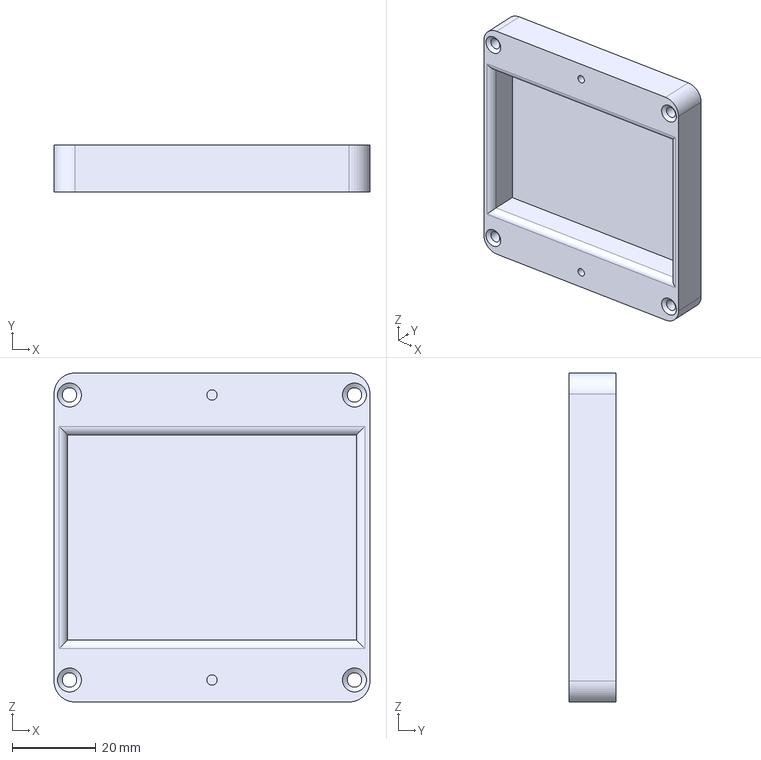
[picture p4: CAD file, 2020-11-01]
3Dprint/BatteryMount_LargeBox.step
75.4 x 11.2 x 78.5 mm

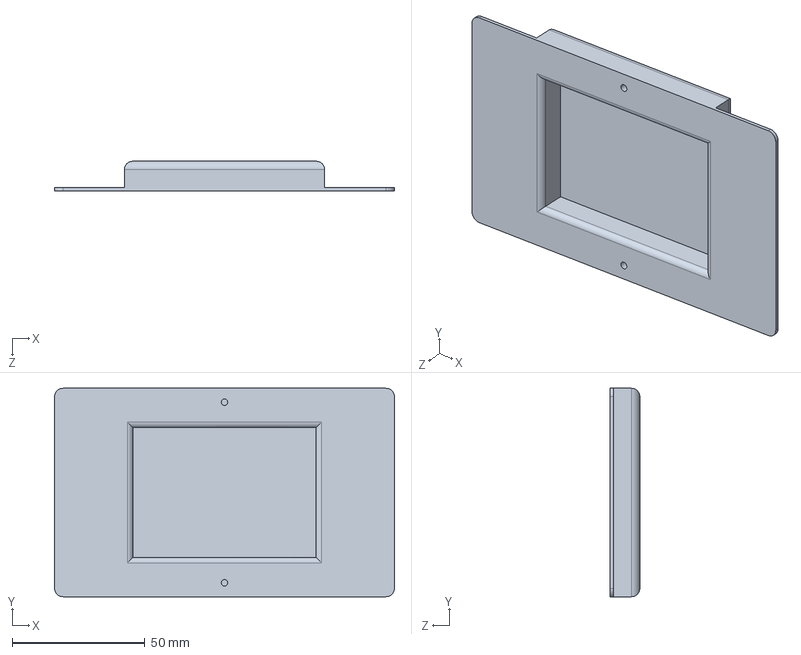
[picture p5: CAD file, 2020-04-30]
AAx3_backup_battery_holder/BatteryMount_LargeBox.SLDPRT
128.0 x 78.5 x 11.2 mm

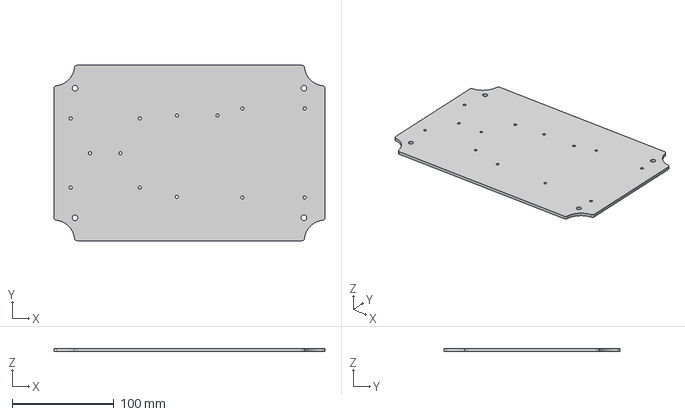
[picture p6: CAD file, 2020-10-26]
Mounting_Plate/WH-16/Resnik_Mounting_Plate_v1.3.step
266.7 x 172.7 x 3.17 mm

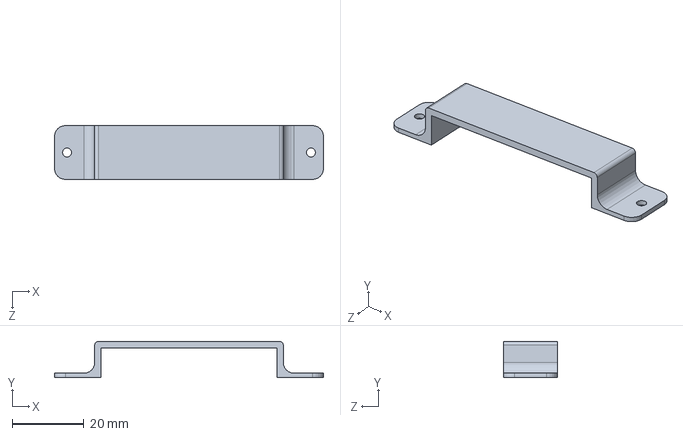
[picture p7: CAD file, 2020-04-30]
3Dprint/BatteryMount_Strap.SLDPRT
75.0 x 10.0 x 15.0 mm

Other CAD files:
Mounting_Plate/WH-16/Resnik_Mounting_Plate.dwg
3Dprint/BatteryMount_LargeBox.3mf
3Dprint/BatteryMount_LargeBox.SLDPRT
3Dprint/BatteryMount_LargeBox.STL
3Dprint/BatteryMount_Strap.3mf
3Dprint/BatteryMount_Strap.STL
AAx3_backup_battery_holder/BatteryMount_LargeBox.STL

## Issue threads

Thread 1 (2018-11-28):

Fix mounting hole dimensions

bschulz1701, 2018-11-28:
Make mounting holes work with [WH-02](https://www.polycase.com/wh-02) type box if possible, otherwise make spacing most convenient

awickert, 2020-06-04:
Too big! Holes are placed as best they can be.

Closed 2020-06-04.

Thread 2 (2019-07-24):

Fix ADC Naming Discrepancy

bschulz1701, 2019-07-24:
### Issue:
There is an inversion between `ADC_0` and `ADC_1`

`ADC_0` is connected to AIN1 and `ADC_1` is connected to AIN0

This means that when you call the voltage for `A0`, the returned value is for the silkscreened pin A1 and vise versa

### Potential Solution:
This could be fixed in software, but this would be a less than desirable solution

Most simple answer would be to change the silkscreen and the trace names to correspond while keeping all routing un-effected

bschulz1701, 2021-03-04:
Fixed as of 5baa045d47cd0259615d34ec8447a97609faa3ae by changing the hardware routing so they match as desired

Closed 2021-03-04.

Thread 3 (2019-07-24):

Allow for Always On Port?

bschulz1701, 2019-07-24:
### Issue:
Is it desirable/needed to have a way to have a port on the output always powered in order to allow for asynchronous interrupts for wake events

If so, what is the best way to implement this?

### Potential Solution **(_Testing still required_)**:
If it is desired to have an always on option, the simplest solution would be to have an SPDT jumper on the bottom side of the board which would allow for U29 to have a selectable input for bus voltage, between `VBUS_PRIME` and `3V3_CORE`.

Two additional requirments of this would be to switch the input voltage source (low voltage side) to `3V3_CORE` instead of `3V3_CORE_ISO`, this way the device could stay powered all the time. Then the chip would need to be swapped for the TXB0104 instead of the TXS0104, since the B series supports partial power down (but NOT I2C, however U29 does not transmit I2C anyway). Partial power down support would mean that the output would be made high impedance when the output power was disabled (if still using the switched output power)

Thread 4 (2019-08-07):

Change gain for I_Solar CSA

bschulz1701, 2019-08-07:
### Problem:
CSA amp used for I_Solar sensing (`U35`) currently is the INA210, which has a gain of 200 V/V. The new current sense resistor for the LT3652 is 50m&Omega;, allowing for a max current (controlled by the LT3652) of 2A. This would result in an output voltage from the INA210 of 20v, so the device would saturate at <0.5A.

### Potential Solution:
Replace amp with INA213, with a gain of 50 V/V, this would result in exactly 5v output at 2A.
#### Testing:
- Check/Verify maximum value allowed by LT3652, which side of "2A" does this fall on
- Check output range for INA213 (how close to the rails can it operate?)
- Test device with 2A and verify accurate measurement

bschulz1701, 2021-03-04:
Part info changed in Eagle

Closed 2021-03-04.

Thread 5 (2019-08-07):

Connect `STAT` pin from LTC4412?

bschulz1701, 2019-08-07:
### Question:
Should the `STAT` pin from the LTC4412 be connected to the IO expander/MCU in order to give sensing/control over the use of battery vs. USB voltage?

Which device should it be connected to?

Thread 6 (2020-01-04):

Battery UVLO Issue

bschulz1701, 2020-01-04:
## Issue:
Battery (Li-Ion, VBat) can be drained beyond UVLO set by protection circuit due to the connection to the ADC through MUX. The battery (`LI+`) is connected directly to MUX (U38) instead of being run through protection circuit. This allows the parasitic drain from diode clamping in the MUX to drain the battery beyond the UV lockout.

## Potential Solution:
Simply connect the battery to the MUX through the protection system (`V_LI`) instead, which will protect it when it enters low voltage shutdown

bschulz1701, 2021-03-04:
Fixed as of v0.5

awickert, 2021-03-04:
@bschulz1701 hand-built and successfully tested 4d67928cf256c99434ec5b61966110642185817b.

Closed 2021-03-04.

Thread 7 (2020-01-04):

Output drain MOSFET issue

bschulz1701, 2020-01-04:
## Issue:
The MOSFET used on the production run of the `v0.4` boards (late 2019) used the 2N7002W-7-F transistor for `Q7`, this does not shut down the `5V_AUX` rail fast enough and can result in latching on and high current draw (~100mA) from the backup battery (`V_PRIME`) when in use.

## Detailed Description:
[20200103185103557.pdf](https://github.com/NorthernWidget-Skunkworks/Project-Resnik/files/4021371/20200103185103557.pdf)

## Potential Solution:
Replace MOSFET with 2N7002WT1G model instead. This device has been tested and results in fast enough shutdown to prevent any excess current draw from the backup battery. Not entirely clear (yet) why the part change fixes the issue, on paper they should be nearly equivalent. The updated part is ESD protected which could result in more reliable performance (inconsistent performance with previous part) and a slight change in diode forward voltage, more testing to be performed.

bschulz1701, 2021-03-04:
Note part replacement in Eagle file

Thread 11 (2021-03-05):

Readme.md

benhadad, 2021-03-05:
The line :" CAUTION: most commercially available multiple-18650-battery holders connect them in parallel; this voltage is TOO HIGH for the data logger."

This should say 'connect them in series' instead of parallel.

awickert, 2021-03-05:
Nice catch & thanks!
a17a6f4589cf2d332ceed4bc3f38355943ce0a78

Closed 2021-03-05.

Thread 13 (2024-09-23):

v1.0 Updates

bschulz1701, 2024-09-23:
### Improvement for `v1.0` design

- [ ] Switch to USB C
- [ ] Add LED system from Kestrel
- [ ] Add CSA from Kestrel (PCA1934)
- [ ] Add FRAM
- [ ] Add on-board sensors
     - [ ] Light
     - [ ] Accel
     - [ ] Mag
- [ ] Investigate option for OTA support

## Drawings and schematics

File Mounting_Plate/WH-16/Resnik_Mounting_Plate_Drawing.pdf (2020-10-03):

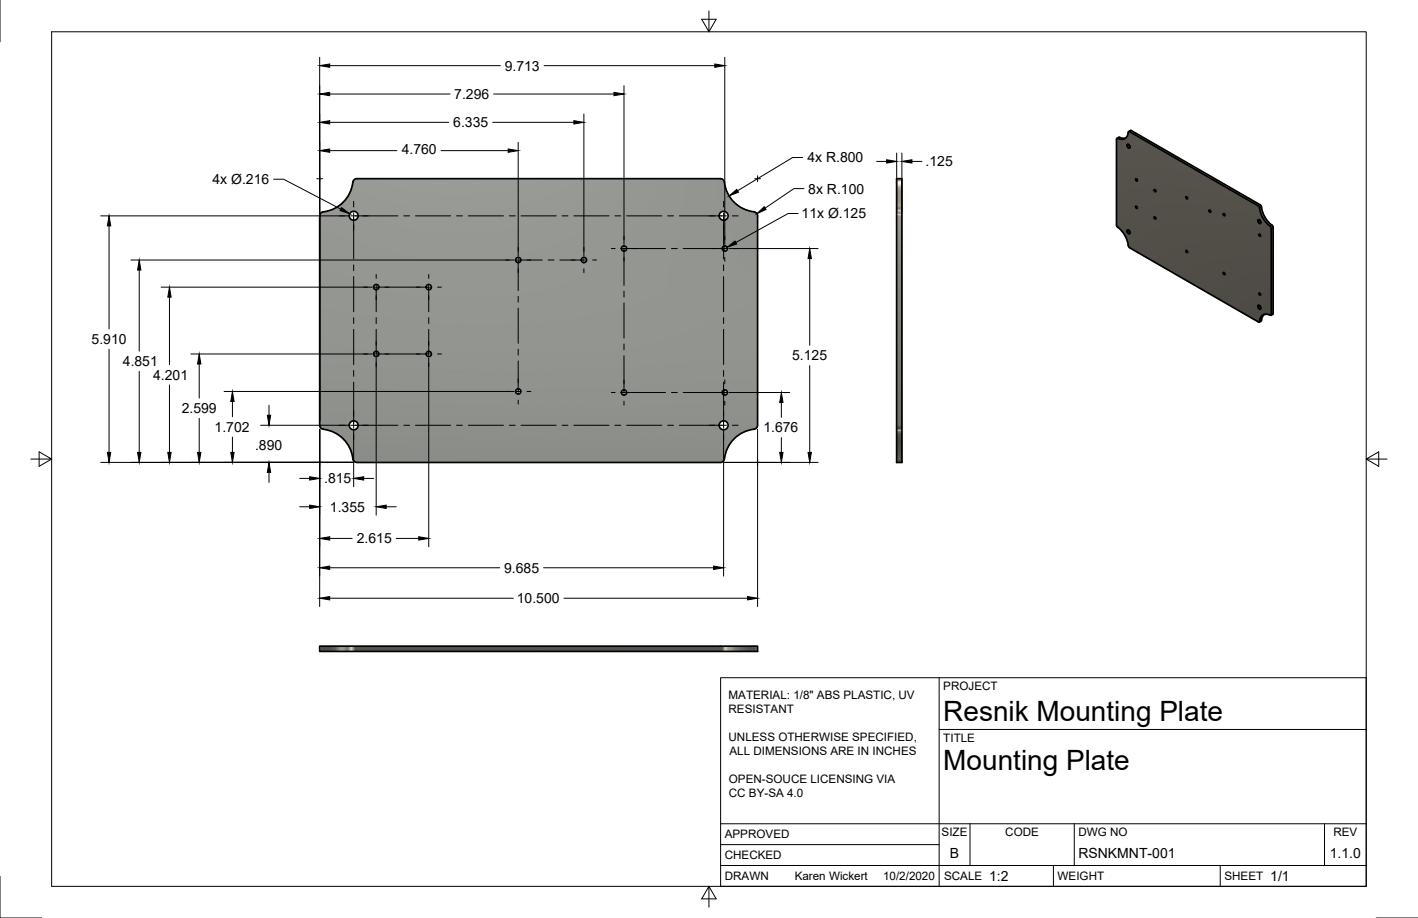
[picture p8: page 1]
SIZE; CODE; DWG NO; REV; Karen Wickert

MATERIAL: 1/8" ABS PLASTIC, UV
RESISTANT

PROJECT
Resnik Mounting Plate
Mounting Plate

UNLESS OTHERWISE SPECIFIED,
ALL DIMENSIONS ARE IN INCHES

OPEN-SOUCE LICENSING VIA

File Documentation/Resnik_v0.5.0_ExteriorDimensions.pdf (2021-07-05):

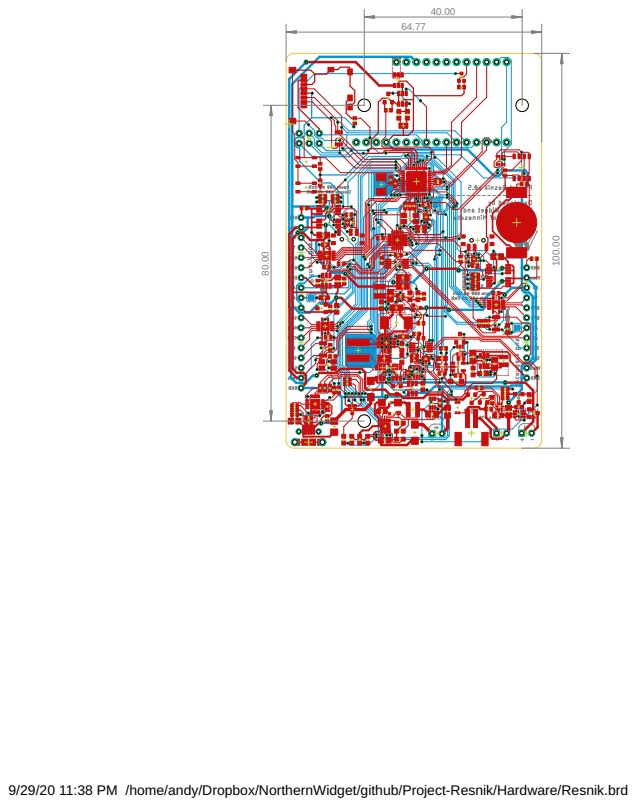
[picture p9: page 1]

9/29/20 11:38 PM /home/andy/Dropbox/NorthernWidget/github/Project-Resnik/Hardware/Resnik.brd

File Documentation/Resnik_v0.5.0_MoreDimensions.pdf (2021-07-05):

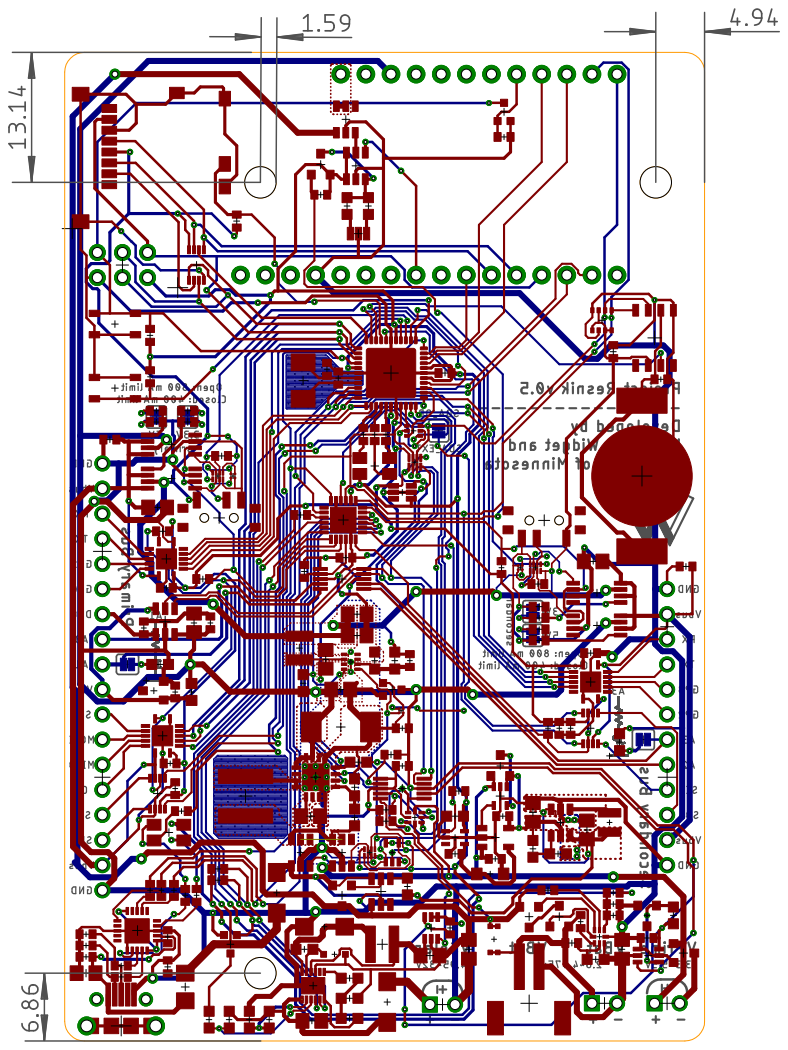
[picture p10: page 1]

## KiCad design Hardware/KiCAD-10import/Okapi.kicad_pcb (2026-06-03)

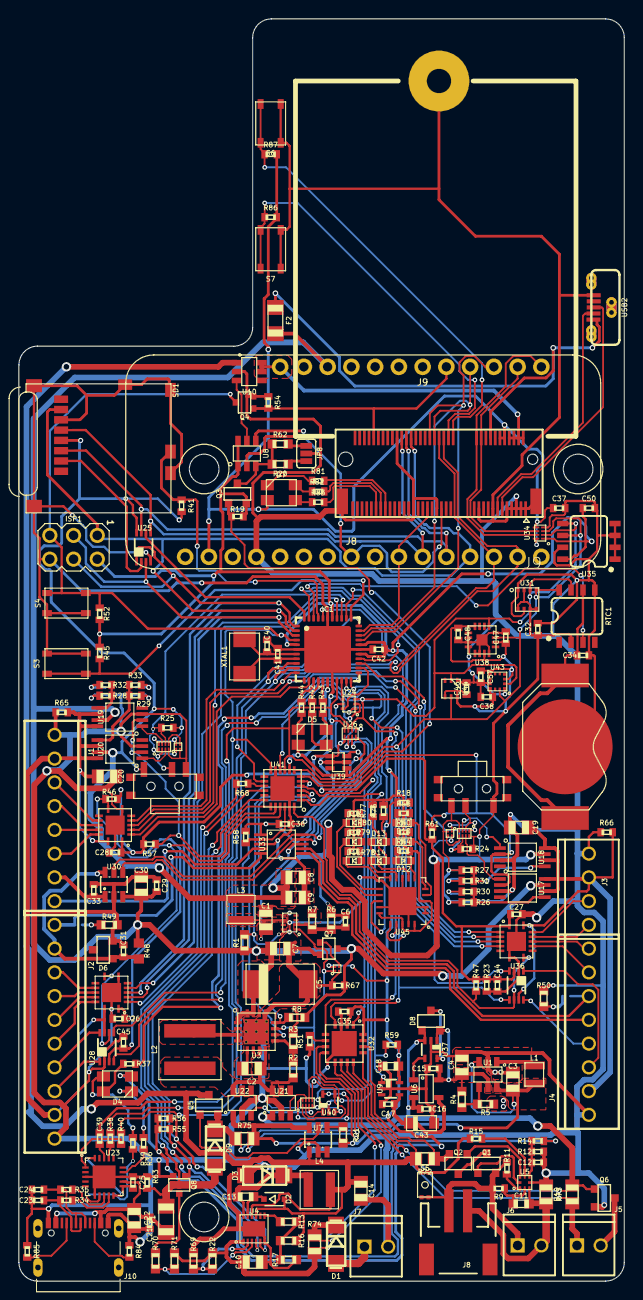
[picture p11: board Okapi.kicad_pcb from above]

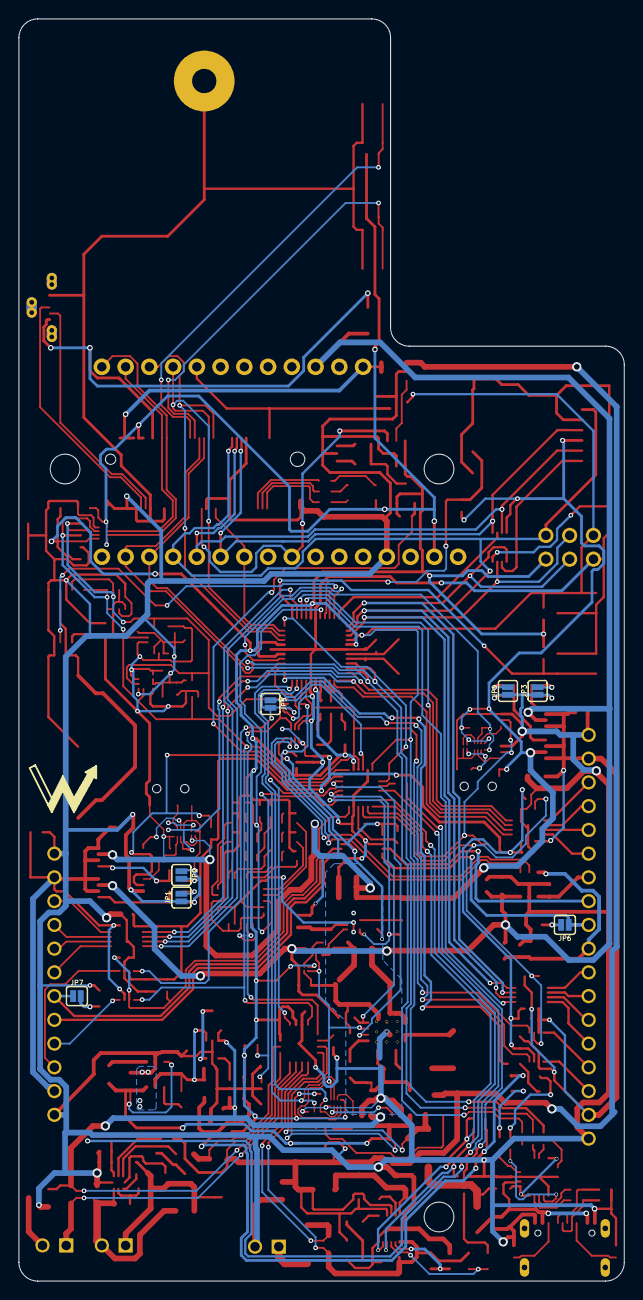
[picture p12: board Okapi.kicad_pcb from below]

Board: 2 copper layers, 64.8 x 135.0 mm, 252 parts (8 on the bottom side), 207 nets.

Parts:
BT1: BATTERY_COIN12MM; LINX_BAT-HLD-012-SMT
C1: 4.7uF; C0805
C2, C7, C8, C9, C10, C19, C20: 22uF; C0805
C3, C4, C14, C22, C30: 10uF; C0805
C5: 220uF; C2917
C6: 68pF; C0402
C11, C13: 1uF; C0603
C12, C17, C21, C25, C26, C27, C28, C29, C31, C32, C33, C34, C35, C36, C37, C38, C39, C44, C45, C46, C47, C48, C50, C57: 0.1uF; C0402
C15, C16: 0.22uF; C0402
C18: 4.7uF; C0603
C23, C24, C40, C41: 12pF; C0402
C42: 1uF; C0402
C43: 100uF; C1206_TANT
D1, D3, D9: DO214AC
D2: SOD323-R
D4, D5, D7: CLVBA-FKA
D6: SOT23-3
D8: BAT54C; SOT23-3@1
D10, D13, D16: LEDGREEN0603; LED_0603
D11, D14, D17: LEDYELLOW0603; LED_0603
D12, D18: LEDRED0603; LED_0603
F1, F2: 1206
H1, H2, H3: 4_40
IC1: ATMEGA1284M; MLF44-TH
ISP1: AVRISP-6; AVRISP
J1, J4: CONN_82.54_SCREW; 1X08_SCREW
J2: 1X10_SCREW
J3: CONN_42.54_SCREW; 1X04_SCREW
J5, J6, J7: 1X02_2.54_SCREWTERM
J8: JST-2-SMD
J9: B_SERIES_M.2EKEY_NOPROG; PARTICLE_M.2EKEY_NOPROG
J10: USB_C_CUSB31-CFM2AX-01-X
JP1, JP2, JP3, JP4, JP5, JP6, JP7: JUMPER-SMT_2_NO_SILK; SMT-JUMPER_2_NO_SILK_528
JP8: JUMPER-SMT_3_1-NC_PASTE_SILK; SMT-JUMPER_3_1-NC_PASTE_SILK_528
L1: 6.8uH; 1008
L2: 10uH; WE-XHMI(6.65X6.45)
L3: 1uH; WE-LQS(3X3)
L4: 4.7uH; WE-MAIA(4.1X4.1)
MS1: FEATHERWINGLAYOUT; FEATHERWING_MIN
Q1, Q2, Q6: DMG3404; SOT23-3
Q3, Q5: FDN360P; SOT23-3@1
Q4, Q7, Q8: 2N7002; SOT323
R1, R5, R7, R8: 180k; R0603
R2, R4: 1.62M; R0603
R3: 360k; R0603
R6: 820k; R0603
R9, R36, R37, R38, R39, R40, R42, R43, R44: 330; R0402
R10: 3m; R0805
R11: 20; R0402
R12: 1k; R0402
R13: 182k; R0603
R14: 100R; R0402
R15: 2k; R0402
R16: 91k; R0603
R17, R62: 330k; R0603
R18, R23, R57, R58, R61, R63: 100k; R0402
R19: 120k; R0402
R20: 130k; R0603
R21: 470k; R0603
R22: 143k; R0603
R24, R25, R41, R45, R46, R47, R52, R67: 10k; R0402
R26, R27, R28, R29, R30, R31, R32, R33: 287R; R0402
R34, R35: 27; R0402
R48: 330R; R0603
R49, R50: 10k; R0603
R51, R54, R84, R85, R86, R87: R0402
R53, R60, R64, R76, R77, R78, R79, R80: 220R; R0402
R55, R56, R59, R68: 1M; R0402
R65, R66: 180k; R0402
R69: 100k; R0603
R70: 200k; R0603
R71: 1M; R0603
R72, R73, R74, R75: R0805
R81, R82, R83: 5.6k; R0402
RTC1: DS3231M; SO08
S1, S2: SPDTPCM12; PCM12
S3, S4, S6, S7: BUTTON4.2X3.2; SWITCH_4.2X3.2
S5: BUTTON2.6X1.6; SWITCH_2.6X1.6
SD1: MICROSDCD; MICROSD_CD
U1: TLV61220DBV; DBV_R-PDSO-G6
U2: TPS62822DLC; DLC_8
U3: TPS61032RSA; RSA_S-PVQFN-N16
U4: DFN_12_3X3
U5: BQ2980RUG; RUG_S-PQFP-N8
U6: TPS2105; SOT23-5
U7: LTC4412S6; SOT23-6L
U8: TPL5111DDC; DDC_R-PDSO-G6
U9: TPS79733; DCK_R-PDSO-G5
U10, U21, U22: TPS22917DBV; DBV_R-PDSO-G6
U11, U12, U13: SN74AUP1G04YFP; DSBGD_4
U14, U15, U16: SN74AUP2G08DQE; DQE_R-PX2SON-N8
U17, U18, U19, U20: MIC2544MSOP; MSOP_8
U23: FT231X-Q; QFN20
U24: SN74LVC1G3157DRL; DRL_R-PDSO-N6
U25: SN74AUP3G34DCU; DCU_(R-PDSO-G8)
U26, U34: TXS0102DQM; DQM_R-PX2SON-N8
U27, U29, U42: TXS0104RGY; RGY_S-PVQFN-N14
U28, U36: TCA9406DCU; DCU_(R-PDSO-G8)
U30: MCP4726A2SOT-23; SOT23-6L
U31: BME280
U32: PAC1934QFN; QFN16
U33: ADS1115; VSSOP_10
U35: MB85RC; SO08
U37: TLV3691DCK; DCK_R-PDSO-G5
U38: MLX90393; QFN16_3X3
U39: MIC94094C6; SC-70_6
U40: SN74AHC1G86DCK; DCK_R-PDSO-G5
U41: MCP23018QFN; QFN24
U43: BMA456; LGA-12_2X2
U44: VEML6030
U45: PCA9634QFN; QFN20_5X5
U$1, U$2: VDIV-JP; VDIV_GENERIC
U$4: NWLOGO_MED
USB2: USB_MICROVERT; USB_MICRO_VERT_MOLEX
XTAL1: CRYSTAL8MHZ5X3.2; CRYSTAL_5X3.2_2-SMD

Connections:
3V3_AUX: C6.1, C8.1, C9.1, C32.1, C38.1, C46.1, C47.1, C48.1, C57.1, L3.P$2, R6.2, R24.2, R25.2, R41.2, RTC1.2, S1.1, S2.1, SD1.4, U11.A2, U12.A2, U14.8, U15.8, U18.7, U20.7, U24.5, U25.8, U31.2, U31.5, U31.6, U31.8, U38.2, U38.8, U38.15, U39.6, U43.3, U43.7, U43.10, U44.4, U44.6
3V3_AUX_PG: R1.1, U2.8, U41.2
3V3_CORE: C18.1, C35.1, C42.1, C50.1, D4.2, D5.2, IC1.5, IC1.17, IC1.27, IC1.29, IC1.38, ISP1.2, Q3.2, R18.2, R19.2, R45.2, R52.2, R53.2, R55.2, R56.2, R59.2, R60.2, R64.2, R76.2, R77.2, R78.2, R79.2, R80.2, U8.1, U8.6, U9.5, U13.A2, U16.8, U32.2, U32.15, U32.16, U34.1, U35.8, U39.4, U40.5, U41.8, U45.3, U45.15, U45.18, U45.20
3V3_CORE_ISO: C26.1, C27.1, C28.1, C44.1, C45.1, R23.2, R46.2, R47.2, R57.2, R61.2, U26.1, U26.5, U27.1, U28.3, U29.1, U36.3, U39.1, U42.1
3V3_FEATHER: C37.1, D7.2, J9.10, J9.12, MS1.2, R86.2, R87.2, U34.5, U34.8
3V3_FTDI: C25.1, U23.10, U23.11, U23.20
5V_AUX: C1.1, C5.+, C7.1, C29.1, C30.1, C36.1, F2.2, MS1.26, Q7.3, R1.2, R8.2, R48.2, R58.2, R67.2, U2.7, U3.1, U3.15, U3.16, U17.7, U19.7, U26.8, U30.3, U33.1, U33.8
5V_LP: C4.1, C15.1, D8.2, R4.2, U1.5, U6.5, U37.1
ADC_0: J1.8, U33.4
ADC_1: J2.1, JP6.1, U33.5
ADC_2: J4.5, U33.6
ADC_3: J4.6, JP7.1, U33.7
ADC_EXT_ALERT: R58.1, U33.2, U41.22
ALIVE_LED: IC1.23, R37.2
BLUE: J9.65, R83.2
BMS_CTR: R14.1, U41.16
BSOM_VUSB: F2.1, J9.16, USB2.1
BUS_LOGIC_EN_PRIME: R46.1, U27.8, U28.6, U29.8, U41.21
BUS_LOGIC_EN_SEC: R47.1, U36.6, U41.24, U42.8
C0: IC1.21, U16.2, U40.1
C1: IC1.22, U16.6, U40.2
CC1: J10.A5, R85.2
CC2: J10.B5, R84.2
CSA_~ALERT: U32.1, U41.4
CS_EXT: IC1.37, U27.2
CS_OUT: J2.6, U27.13
D+: C24.2, J10.A6, J10.B6, R35.2
D-: C23.2, J10.A7, J10.B7, R34.2
DAC_OUT: C33.1, J1.7, U30.1
DTR: C39.1, U23.18
EN_BUS_PRIME: IC1.26, R25.1, U15.1, U15.6
EN_BUS_SEC: IC1.25, R24.1, U14.1, U14.6
FAULT_PRIME: R57.1, U19.2, U20.2, U41.20
FAULT_SEC: R61.1, U17.2, U18.2, U41.6
FEATHER_BAT: J9.2, J9.4, J9.6, J9.8, MS1.28, U10.5, U10.6
FEATHER_CTS: IC1.31, J9.40, MS1.20
FEATHER_EN: Q3.1, R19.1, U41.7
FEATHER_GPIO: IC1.32, J9.43, MS1.10
FEATHER_RTS: IC1.30, J9.42, MS1.19
GLOBAL_INT: IC1.33, U41.14
GND: BT1.GND, C1.2, C2.2, C3.2, C4.2, C5.-, C7.2, C8.2, C9.2, C10.2, C12.2, C14.2, C15.2, C16.2, C17.2, C18.2, C19.2, C20.2, C21.2, C22.2, C23.1, C24.1, C25.2, C26.2, C27.2, C28.2, C29.2, C30.2, C31.2, C32.2, C33.2, C34.2, C35.2, C36.2, C37.2, C38.2, C40.1, C41.1, C42.2, C43.-, C44.2, C45.2, C46.2, C47.2, C48.2, C50.2, C57.2, D3.A, D6.2, IC1.6, IC1.18, IC1.28, IC1.39, IC1.TH, ISP1.6, J1.1, J2.10, J3.1, J4.1, J7.P1, J9.1, J9.3, J9.5, J9.7, J9.9, J9.15, J9.21, J9.39, J9.49, J9.56, J9.76, J9.77, J9.GND, J10.A1B12, J10.B1A12, JP1.1, JP2.1, JP3.1, JP4.1, JP8.2, MS1.4, Q4.2, Q6.2, Q7.2, Q8.2, R3.1, R5.1, R7.1, R10.2, R12.1, R17.2, R23.1, R26.1, R27.2, R28.1, R29.2, R49.1, R50.1, R51.1, R54.1, R63.1, R65.1, R66.1, R67.1, R69.1, R84.1, R85.1, RTC1.5, S1.3, S2.3, S3.1, S3.2, S4.1, S4.2, S6.3, S6.4, S7.3, S7.4, SD1.6, SD1.CD2, SD1.MT1, SD1.MT2, SD1.MT3, SD1.MT4, U1.2, U2.3, U2.5, U3.5, U3.6, U3.7, U3.13, U3.PAD, U3.PAD@1, U3.PAD@2, U3.PAD@3, U3.PAD@4, U3.PAD@5, U3.PAD@6, U3.PAD@7, U3.PAD@8, U3.PAD@9, U4.6, U4.EP, U5.4, U6.2, U7.2, U7.3, U8.2, U9.2, U10.2, U11.B1, U12.B1, U13.B1, U14.4, U15.4, U16.4, U17.3, U18.3, U19.3, U20.3, U21.2, U22.2, U23.3, U23.6, U23.13, U23.EP, U24.2, U25.4, U26.4, U27.7, U27.EP, U28.2, U29.7, U29.EP, U30.2, U31.1, U31.7, U32.3, U32.EP, U33.3, U34.4, U35.1, U35.2, U35.3, U35.4, U35.7, U36.2, U37.2, U38.4, U38.9, U38.10, U38.11, U38.12, U38.13, U38.14, U38.16, U38.EP, U39.2, U39.5, U40.3, U41.11, U41.23, U41.EP, U42.7, U42.EP, U43.1, U43.8, U43.9, U44.1, U45.1, U45.2, U45.8, U45.14, U45.19, U45.EP, USB2.5
GPIO_0: IC1.13, U29.2
GPIO_0_OUT: J1.6, U29.13
GPIO_1: IC1.36, U29.3
GPIO_1_OUT: J1.5, U29.12
GPIO_2: IC1.43, U42.5
GPIO_2_OUT: J4.7, U42.10
GPIO_3: IC1.35, U42.4
GPIO_3_OUT: J4.8, U42.11
GREEN: J9.63, R82.2
LBI: R8.1, U3.12, U41.3
LED1: IC1.14, R44.1
LED2: IC1.15, R42.1
LED3: IC1.16, R43.1
LI+: J6.P2, J8.2, Q1.2, R9.2, R11.2, S5.A, S5.A'
LI-: C11.2, J6.P1, J8.1, R10.1, U5.3
LOG_INT: IC1.34, R45.1, S3.3, S3.4
MISO: IC1.2, ISP1.1, J9.50, MS1.13, SD1.7, U27.3
MISO_OUT: J2.5, U27.12
MOSI: IC1.1, ISP1.4, U25.1, U27.4
MOSI_BUF: J9.52, MS1.12, SD1.3, U25.7
MOSI_OUT: J2.4, U27.11
MPPT_CHRG: Q8.1, R55.1, U4.4, U41.18
MPPT_FAULT: R56.1, U4.5, U41.19
MPPT_SHDN: R70.2, R71.1, U4.3
MPPT_VIN_REG: R22.1, R69.2, U4.2
unnamed: L3.P$1, U2.6
unnamed: C6.2, R6.1, R7.2, U2.2
unnamed: R2.1, R3.2, U3.9
unnamed: L2.2, U3.3, U3.4
unnamed: Q1.3, Q2.3
unnamed: R4.1, R5.2, U1.4
unnamed: Q1.1, U5.8
unnamed: L1.2, U1.1
unnamed: Q2.1, U5.7
unnamed: R15.2, U5.6
unnamed: R13.1, R16.2, R17.1
unnamed: C12.1, R12.2, R14.2, U5.5
unnamed: R11.1, U5.1
unnamed: R13.2, U4.7
unnamed: C11.1, R9.1, U5.2
unnamed: R68.1, U41.15
unnamed: C13.2, D2.C, U4.11
unnamed: JP8.3, R20.1
unnamed: C13.1, D3.C, L4.P$1, U4.12
unnamed: R51.2, U32.6
unnamed: Q8.3, R70.1
unnamed: U16.7, U21.3
unnamed: U16.3, U22.3
unnamed: D10.CATHODE, U45.4
unnamed: U12.B2, U15.5
unnamed: R28.2, R32.2, U19.5
unnamed: S2.2, U12.A1, U15.2
unnamed: U15.7, U19.1
unnamed: U15.3, U20.1
unnamed: JP3.2, R32.1
unnamed: JP4.2, R33.2
unnamed: R29.1, R33.1, U20.5
unnamed: U11.B2, U14.5
unnamed: S1.2, U11.A1, U14.2
unnamed: U14.7, U17.1
unnamed: U14.3, U18.1
unnamed: R26.2, R30.2, U17.5
unnamed: JP1.2, R30.1
unnamed: JP2.2, R31.2
unnamed: R27.1, R31.1, U18.5
unnamed: JP8.1, R62.1
unnamed: BT1.POWER0, BT1.POWER1, C34.1, RTC1.6
unnamed: R38.2, U23.17
unnamed: Q5.1, U7.5
unnamed: R21.1, U7.4
unnamed: R40.2, U23.1
unnamed: R35.1, U23.8
unnamed: R39.2, U23.14
unnamed: R34.1, U23.9
unnamed: D4.1, R39.1
unnamed: D4.3, R36.1
unnamed: D4.4, R37.1
unnamed: R36.2, U23.7
unnamed: D5.3, R42.2
unnamed: D5.4, R43.2
unnamed: D5.1, R44.2
unnamed: C40.2, IC1.7, XTAL1.OSC2
unnamed: C41.2, IC1.8, XTAL1.OSC1
unnamed: Q3.3, R20.2, R62.2, U8.3
unnamed: U8.5, U10.3
unnamed: JP6.2, R49.2
unnamed: JP7.2, R50.2
unnamed: D11.CATHODE, U45.5
unnamed: Q7.1, U13.B2
unnamed: D8.3, U37.5
unnamed: D12.CATHODE, U45.6
unnamed: D13.CATHODE, U45.7
unnamed: D14.CATHODE, U45.9
unnamed: D16.CATHODE, U45.10
unnamed: D17.CATHODE, U45.11
unnamed: D18.CATHODE, U45.12
unnamed: D10.ANODE, R53.1
unnamed: D11.ANODE, R60.1
unnamed: D12.ANODE, R64.1
unnamed: D13.ANODE, R76.1
unnamed: D14.ANODE, R77.1
unnamed: D16.ANODE, R78.1
unnamed: D17.ANODE, R79.1
unnamed: D18.ANODE, R80.1
unnamed: D7.1, R81.1
unnamed: D7.4, R82.1
unnamed: D7.3, R83.1
PD+: J9.11, USB2.3
PD-: J9.13, USB2.2
PG_LDO: R59.1, U9.1, U41.1
POWER_EN: U2.1, U3.11, U13.A1, U16.1, U16.5, U40.4
QOD: U21.5, U22.5
RED: J9.61, R81.2
RST: C39.2, IC1.4, ISP1.5, Q4.3, R52.1, S4.3, S4.4, U41.12
RST_TRIG: J9.66, MS1.21, Q4.1, R54.2
RTC_INT: IC1.42, RTC1.3
RX: IC1.9, J9.36, MS1.15, R38.1
RX_EXT: IC1.11, U29.5, U42.2
RX_OUT_PRIME: J1.3, U29.10
RX_OUT_SEC: J3.3, U42.13
SCK: IC1.3, ISP1.3, U25.3, U27.5
SCK_BUF: J9.54, MS1.11, SD1.5, U25.5
SCK_OUT: J2.3, U27.10
SCL: IC1.19, RTC1.8, U26.3, U28.5, U31.4, U32.4, U34.3, U35.6, U36.5, U38.3, U41.9, U43.12, U44.5, U45.16
SCL_5V: U26.6, U30.5, U33.10
SCL_FEATHER: J9.20, MS1.18, U34.6
SCL_OUT_PRIME: J2.7, U28.8
SCL_OUT_SEC: J4.4, U36.8
SDA: IC1.20, U24.4
SDA_5V: U26.7, U30.4, U33.9
SDA_CTRL: IC1.24, U24.6
SDA_EXT: JP5.2, U24.1, U28.4, U36.4
SDA_FEATHER: J9.22, MS1.17, U34.7
SDA_OB: JP5.1, RTC1.7, U24.3, U26.2, U31.3, U32.5, U34.2, U35.5, U38.5, U41.10, U43.2, U44.2, U45.17
SDA_OUT_PRIME: J2.8, U28.1
SDA_OUT_SEC: J4.3, U36.1
SD_CD: IC1.41, R41.1, SD1.CD1
SD_CS: IC1.44, U25.6
SD_CS_BUF: SD1.2, U25.2
TX: IC1.10, J9.38, MS1.14, R40.1
TX_EXT: IC1.12, U29.4, U42.3
TX_OUT_PRIME: J1.4, U29.11
TX_OUT_SEC: J3.4, U42.12
VBUS_PRIME: C20.1, J1.2, J2.9, R65.2, U19.6, U19.8, U20.6, U20.8, U27.14, U28.7, U29.14
VBUS_SEC: C19.1, J3.2, J4.2, R66.2, U17.6, U17.8, U18.6, U18.8, U36.7, U42.14
VREF: C31.1, D6.1, J2.2, R48.1, U30.6
VUSB: C21.1, C22.1, F1.1, J10.A4B9, J10.B4A9, U23.12
VUSB_POWER: D9.A, F1.2, R63.2, R68.2
V_BETA: C3.1, L1.1, R21.2, R75.2, U1.3, U1.6, U7.6, U22.1, U32.7
V_BETA_SENSE: D9.C, Q5.2, R75.1, U32.8
V_CORE: C17.1, C43.+, U6.4, U9.4
V_CORE_SW: U6.1, U37.4
V_HP: C2.1, L2.1, R2.2, U3.8, U21.6, U22.6
V_HP_SYNC: U3.10, U41.5
V_LI: C14.1, D2.A, L4.P$2, Q5.3, R15.1, R16.1, R72.2, S5.B, S5.B', U4.9, U4.10, U7.1, U10.1, U32.13
V_LI_SENSE: Q2.2, R72.1, U32.14
V_PRIME: C16.1, D8.1, Q6.1, R73.2, U6.3, U21.1, U32.12, U37.3
V_PRIME-: J5.P1, Q6.3
V_PRIME_SENSE: J5.P2, R73.1, U32.11
V_SOLAR: D1.A, J7.P2
V_SOLAR_IN: C10.1, R22.2, R71.2, R74.2, U4.1, U32.9
V_SOLAR_SENSE: D1.C, R74.1, U32.10
WD_DONE: J9.37, MS1.8, U8.4
~LED_EN: IC1.40, R18.1, U45.13
~MODE: J9.32, R87.1, S6.1, S6.2
~RST: J9.34, R86.1, S7.1, S7.2

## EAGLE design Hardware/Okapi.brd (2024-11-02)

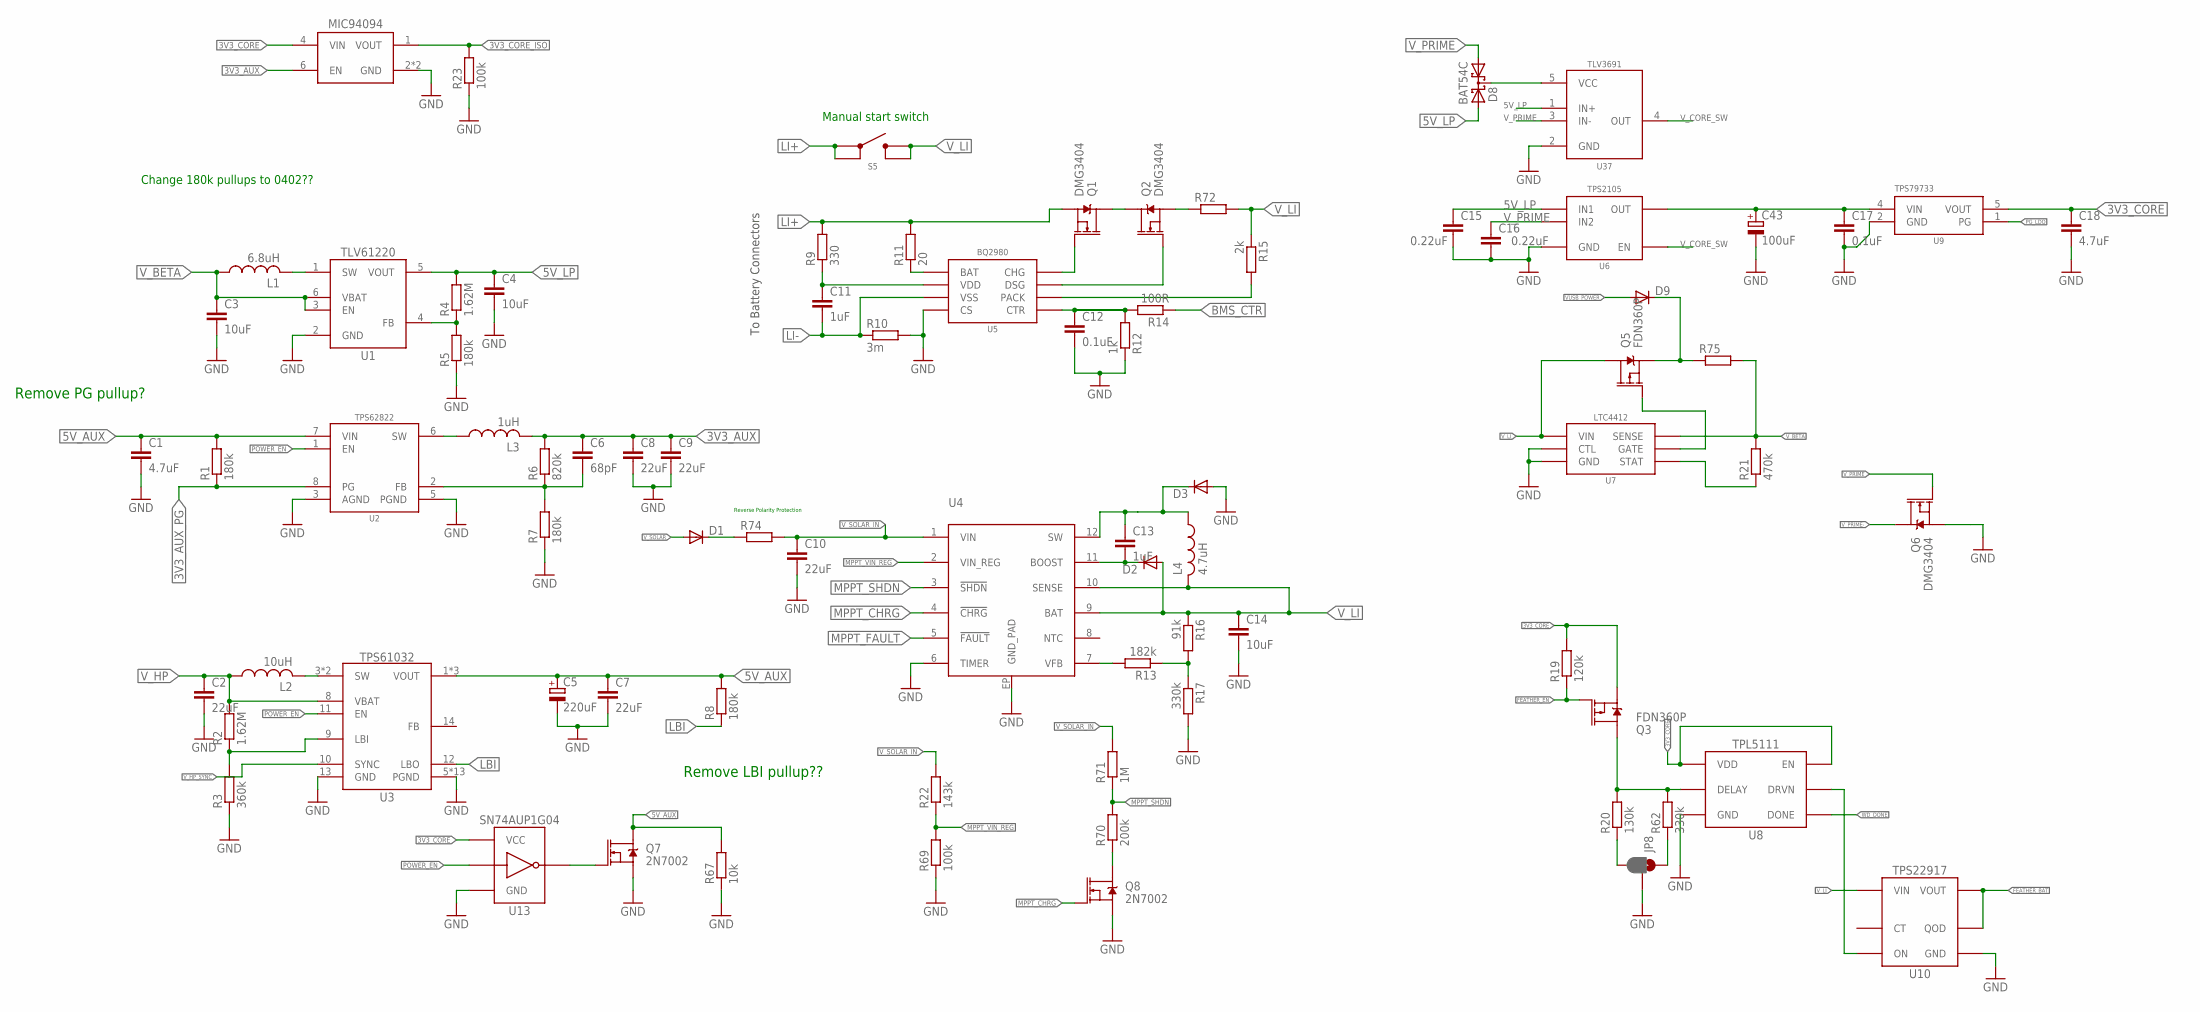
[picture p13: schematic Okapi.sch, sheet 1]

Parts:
C1: 4.7uF; C0805
C2, C7, C8, C9, C10: 22uF; C0805
C3, C4, C14: 10uF; C0805
C5: 220uF; C2917; MPN TPSY227K010R0100; DIGIKEY 478-5408-1-ND
C6: 68pF; C0402
C11, C13: 1uF; C0603
C12, C17: 0.1uF; C0402
C15, C16: 0.22uF; C0402
C18: 4.7uF; C0603
C43: 100uF; C1206_TANT; MPN TL8A0107M010D; DIGIKEY 718-1921-1-ND
D1, D3: DIODEDO-214AC; DO214AC; MPN CMSH3-40MA TR13; DIGIKEY CMSH3-40MATR13CT-ND
D2: DIODESOD-323; SOD323-R; MPN CMDSH2-3 TR; DIGIKEY CMDSH2-3CT-ND
D8: BAT54C; SOT23-3@1
D9: DIODEDO-214AC; DO214AC; MPN B340A-13-F; DIGIKEY B340A-FDICT-ND
JP8: JUMPER-SMT_3_1-NC_PASTE_SILK; SMT-JUMPER_3_1-NC_PASTE_SILK
L1: 6.8uH; 1008; MPN 74438323068; DIGIKEY 732-4849-1-ND
L2: 10uH; WE-XHMI(6.65X6.45); MPN 74439346100; DIGIKEY 732-10707-1-ND
L3: 1uH; WE-LQS(3X3); MPN 74404032010; DIGIKEY 732-5491-1-ND
L4: 4.7uH; WE-MAIA(4.1X4.1); MPN 78438356047; DIGIKEY 732-11316-1-ND
Q1, Q2, Q6: DMG3404; SOT23-3
Q3, Q5: FDN360P; SOT23-3@1
Q7, Q8: 2N7002; SOT323
R1, R5, R7, R8: 180k; R0603
R2, R4: 1.62M; R0603
R3: 360k; R0603
R6: 820k; R0603
R9: 330; R0402
R10: 3m; R0805
R11: 20; R0402
R12: 1k; R0402
R13: 182k; R0603
R14: 100R; R0402
R15: 2k; R0402
R16: 91k; R0603
R17, R62: 330k; R0603
R19: 120k; R0402
R20: 130k; R0603
R21: 470k; R0603
R22: 143k; R0603
R23: 100k; R0402
R67: 10k; R0402
R69: 100k; R0603
R70: 200k; R0603
R71: 1M; R0603
R72, R74, R75: R-EU_R0805; R0805
S5: BUTTON2.6X1.6; SWITCH_2.6X1.6; MPN EVP-BB2A9B000; DIGIKEY P19888CT-ND
U1: TLV61220DBV; DBV_R-PDSO-G6
U2: TPS62822DLC; DLC_8
U3: TPS61032RSA; RSA_S-PVQFN-N16
U4: LT3652DD; DFN_12_3X3
U5: BQ2980RUG; RUG_S-PQFP-N8
U6: TPS2105; SOT23-5
U7: LTC4412S6; SOT23-6L
U8: TPL5111DDC; DDC_R-PDSO-G6
U9: TPS79733; DCK_R-PDSO-G5
U10: TPS22917DBV; DBV_R-PDSO-G6
U13: SN74AUP1G04YFP; DSBGD_4
U37: TLV3691DCK; DCK_R-PDSO-G5
U39: MIC94094C6; SC-70_6

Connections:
3V3_AUX: C6.1, C8.1, C9.1, L3.P$2 (2), R6.2, U39.6 (EN); also elsewhere on the board
3V3_AUX_PG: R1.1, U2.8 (PG); also elsewhere on the board
3V3_CORE: C18.1, Q3.2 (S), R19.2, U8.1 (VDD), U8.6 (EN), U9.5 (VOUT), U13.A2 (VCC), U39.4 (VIN); also elsewhere on the board
3V3_CORE_ISO: R23.2, U39.1 (VOUT); also elsewhere on the board
5V_AUX: C1.1, C5.+, C7.1, Q7.3 (D), R1.2, R8.2, R67.2, U2.7 (VIN), U3.1 (VOUT), U3.15 (VOUT), U3.16 (VOUT); also elsewhere on the board
5V_LP: C4.1, C15.1, D8.2 (A2), R4.2, U1.5 (VOUT), U6.5 (IN1), U37.1 (IN+)
BMS_CTR: R14.1; also elsewhere on the board
FEATHER_BAT: U10.5 (QOD), U10.6 (VOUT); also elsewhere on the board
FEATHER_EN: Q3.1 (G), R19.1; also elsewhere on the board
GND: C1.2, C2.2, C3.2, C4.2, C5.-, C7.2, C8.2, C9.2, C10.2, C12.2, C14.2, C15.2, C16.2, C17.2, C18.2, C43.-, D3.A, JP8.2, Q6.2 (S), Q7.2 (S), Q8.2 (S), R3.1, R5.1, R7.1, R10.2, R12.1, R17.2, R23.1, R67.1, R69.1, U1.2 (GND), U2.3 (AGND), U2.5 (PGND), U3.5 (PGND), U3.6 (PGND), U3.7 (PGND), U3.13 (GND), U3.PAD (PGND), U3.PAD@1 (PGND), U3.PAD@2 (PGND), U3.PAD@3 (PGND), U3.PAD@4 (PGND), U3.PAD@5 (PGND), U3.PAD@6 (PGND), U3.PAD@7 (PGND), U3.PAD@8 (PGND), U3.PAD@9 (PGND), U4.6 (TIMER), U4.EP (GND_PAD), U5.4 (CS), U6.2 (GND), U7.2 (GND), U7.3 (CTL), U8.2 (GND), U9.2 (GND), U10.2 (GND), U13.B1 (GND), U37.2 (GND), U39.2 (GND), U39.5 (GND); also elsewhere on the board
LBI: R8.1, U3.12 (LBO); also elsewhere on the board
LI+: Q1.2 (S), R9.2, R11.2, S5.A (1), S5.A' (2); also elsewhere on the board
LI-: C11.2, R10.1, U5.3 (VSS); also elsewhere on the board
MPPT_CHRG: Q8.1 (G), U4.4 (!CHRG); also elsewhere on the board
MPPT_FAULT: U4.5 (!FAULT); also elsewhere on the board
MPPT_SHDN: R70.2, R71.1, U4.3 (!SHDN)
MPPT_VIN_REG: R22.1, R69.2, U4.2 (VIN_REG)
unnamed: L3.P$1 (1), U2.6 (SW)
unnamed: C6.2, R6.1, R7.2, U2.2 (FB)
unnamed: R2.1, R3.2, U3.9 (LBI)
unnamed: L2.2, U3.3 (SW), U3.4 (SW)
unnamed: Q1.3 (D), Q2.3 (D)
unnamed: R4.1, R5.2, U1.4 (FB)
unnamed: Q1.1 (G), U5.8 (CHG)
unnamed: L1.2, U1.1 (SW)
unnamed: Q2.1 (G), U5.7 (DSG)
unnamed: R15.2, U5.6 (PACK)
unnamed: R13.1, R16.2, R17.1
unnamed: C12.1, R12.2, R14.2, U5.5 (CTR)
unnamed: R11.1, U5.1 (BAT)
unnamed: R13.2, U4.7 (VFB)
unnamed: C11.1, R9.1, U5.2 (VDD)
unnamed: C13.2, D2.C, U4.11 (BOOST)
unnamed: JP8.3, R20.1
unnamed: C13.1, D3.C, L4.P$1 (1), U4.12 (SW)
unnamed: Q8.3 (D), R70.1
unnamed: JP8.1, R62.1
unnamed: Q5.1 (G), U7.5 (GATE)
unnamed: R21.1, U7.4 (STAT)
unnamed: Q3.3 (D), R20.2, R62.2, U8.3 (DELAY)
unnamed: U8.5 (DRVN), U10.3 (ON)
unnamed: Q7.1 (G), U13.B2 (Y)
unnamed: D8.3 (C), U37.5 (VCC)
PG_LDO: U9.1 (PG); also elsewhere on the board
POWER_EN: U2.1 (EN), U3.11 (EN), U13.A1 (A); also elsewhere on the board
VUSB_POWER: D9.A; also elsewhere on the board
V_BETA: C3.1, L1.1, R21.2, R75.2, U1.3 (EN), U1.6 (VBAT), U7.6 (SENSE); also elsewhere on the board
V_BETA_SENSE: D9.C, Q5.2 (S), R75.1; also elsewhere on the board
V_CORE: C17.1, C43.+, U6.4 (OUT), U9.4 (VIN)
V_CORE_SW: U6.1 (EN), U37.4 (OUT)
V_HP: C2.1, L2.1, R2.2, U3.8 (VBAT); also elsewhere on the board
V_HP_SYNC: U3.10 (SYNC); also elsewhere on the board
V_LI: C14.1, D2.A, L4.P$2 (2), Q5.3 (D), R15.1, R16.1, R72.2, S5.B (3), S5.B' (4), U4.9 (BAT), U4.10 (SENSE), U7.1 (VIN), U10.1 (VIN); also elsewhere on the board
V_LI_SENSE: Q2.2 (S), R72.1; also elsewhere on the board
V_PRIME: C16.1, D8.1 (A1), Q6.1 (G), U6.3 (IN2), U37.3 (IN-); also elsewhere on the board
V_PRIME-: Q6.3 (D); also elsewhere on the board
V_SOLAR: D1.A; also elsewhere on the board
V_SOLAR_IN: C10.1, R22.2, R71.2, R74.2, U4.1 (VIN); also elsewhere on the board
V_SOLAR_SENSE: D1.C, R74.1; also elsewhere on the board
WD_DONE: U8.4 (DONE); also elsewhere on the board

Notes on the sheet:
To Battery Connectors
Change 180k pullups to 0402??
Reverse Polarity Protection
Remove PG pullup?
Remove LBI pullup??
Manual start switch

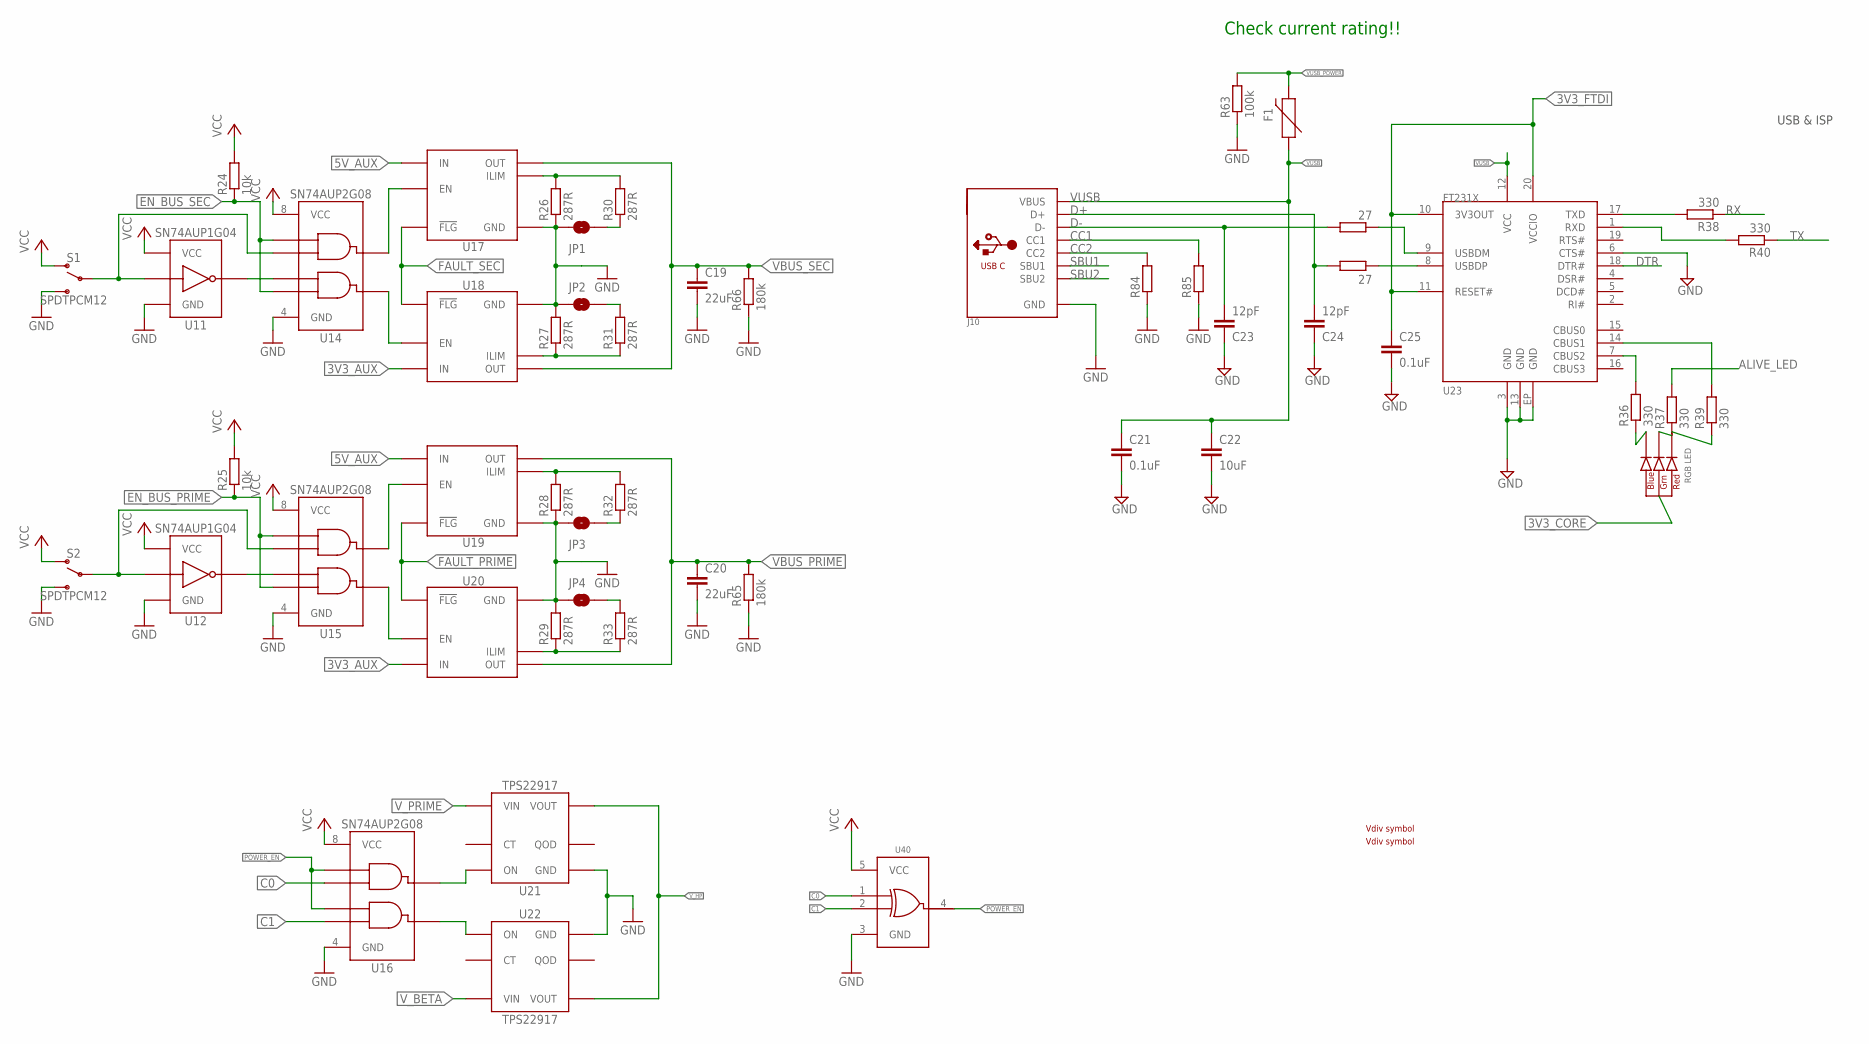
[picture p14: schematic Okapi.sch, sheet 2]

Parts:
C19, C20: 22uF; C0805
C21, C25: 0.1uF; C0402
C22: 10uF; C0805
C23, C24: 12pF; C0402
D4: CLVBA-FKA
F1: PPTC1.5A; 1206
J10: USB_C; USB_C_CUSB31-CFM2AX-01-X; MPN USB4105-GF-A; DIGIKEY 2073-USB4105-GF-ACT-ND
JP1, JP2, JP3, JP4: JUMPER-SMT_2_NO_SILK; SMT-JUMPER_2_NO_SILK
R24, R25: 10k; R0402
R26, R27, R28, R29, R30, R31, R32, R33: 287R; R0402
R34, R35: 27; R0402
R36, R38, R40: 330; R0402; MPN RC0603FR-07330RL
R37, R39: 330; R0402; MPN RC0603FR-07330RL; DIGIKEY 311-330HRCT-ND
R63: 100k; R0402
R65, R66: 180k; R0402
R84, R85: R-EU_5.1KR0402; R0402
S1, S2: SPDTPCM12; PCM12
U11, U12: SN74AUP1G04YFP; DSBGD_4
U14, U15, U16: SN74AUP2G08DQE; DQE_R-PX2SON-N8
U17, U18, U19, U20: MIC2544MSOP; MSOP_8
U21, U22: TPS22917DBV; DBV_R-PDSO-G6
U23: FT231X-Q; QFN20
U40: SN74AHC1G86DCK; DCK_R-PDSO-G5
U$1, U$2: VDIV-JP; VDIV_GENERIC

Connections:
3V3_AUX: R24.2, R25.2, S1.1 (O), S2.1 (O), U11.A2 (VCC), U12.A2 (VCC), U14.8 (VCC), U15.8 (VCC), U18.7 (IN), U20.7 (IN); also elsewhere on the board
3V3_CORE: D4.2 (ANODE), U16.8 (VCC), U40.5 (VCC); also elsewhere on the board
3V3_FTDI: C25.1, U23.10 (3V3OUT), U23.11 (RESET#), U23.20 (VCCIO)
5V_AUX: U17.7 (IN), U19.7 (IN); also elsewhere on the board
ALIVE_LED: R37.2; also elsewhere on the board
C0: U16.2 (B1), U40.1 (A); also elsewhere on the board
C1: U16.6 (B2), U40.2 (B); also elsewhere on the board
CC1: J10.A5 (CC1), R85.2
CC2: J10.B5 (CC2), R84.2
D+: C24.2, J10.A6 (D+), J10.B6 (D+), R35.2
D-: C23.2, J10.A7 (D-), J10.B7 (D-), R34.2
DTR: U23.18 (DTR#); also elsewhere on the board
EN_BUS_PRIME: R25.1, U15.1 (A1), U15.6 (B2); also elsewhere on the board
EN_BUS_SEC: R24.1, U14.1 (A1), U14.6 (B2); also elsewhere on the board
FAULT_PRIME: U19.2 (!FLG), U20.2 (!FLG); also elsewhere on the board
FAULT_SEC: U17.2 (!FLG), U18.2 (!FLG); also elsewhere on the board
GND: C19.2, C20.2, C21.2, C22.2, C23.1, C24.1, C25.2, J10.A1B12 (GND), J10.B1A12 (GND), JP1.1, JP2.1, JP3.1, JP4.1, R26.1, R27.2, R28.1, R29.2, R63.1, R65.1, R66.1, R84.1, R85.1, S1.3 (S), S2.3 (S), U11.B1 (GND), U12.B1 (GND), U14.4 (GND), U15.4 (GND), U16.4 (GND), U17.3 (GND), U18.3 (GND), U19.3 (GND), U20.3 (GND), U21.2 (GND), U22.2 (GND), U23.3 (GND), U23.6 (CTS#), U23.13 (GND), U23.EP (GND), U40.3 (GND); also elsewhere on the board
unnamed: U16.7 (Y1), U21.3 (ON)
unnamed: U16.3 (Y2), U22.3 (ON)
unnamed: U12.B2 (Y), U15.5 (A2)
unnamed: R28.2, R32.2, U19.5 (ILIM)
unnamed: S2.2, U12.A1 (A), U15.2 (B1)
unnamed: U15.7 (Y1), U19.1 (EN)
unnamed: U15.3 (Y2), U20.1 (EN)
unnamed: JP3.2, R32.1
unnamed: JP4.2, R33.2
unnamed: R29.1, R33.1, U20.5 (ILIM)
unnamed: U11.B2 (Y), U14.5 (A2)
unnamed: S1.2, U11.A1 (A), U14.2 (B1)
unnamed: U14.7 (Y1), U17.1 (EN)
unnamed: U14.3 (Y2), U18.1 (EN)
unnamed: R26.2, R30.2, U17.5 (ILIM)
unnamed: JP1.2, R30.1
unnamed: JP2.2, R31.2
unnamed: R27.1, R31.1, U18.5 (ILIM)
unnamed: R38.2, U23.17 (TXD)
unnamed: R40.2, U23.1 (RXD)
unnamed: R35.1, U23.8 (USBDP)
unnamed: R39.2, U23.14 (CBUS1)
unnamed: R34.1, U23.9 (USBDM)
unnamed: D4.1 (RED_CATH), R39.1
unnamed: D4.3 (BLUE_CATH), R36.1
unnamed: D4.4 (GREEN_CATH), R37.1
unnamed: R36.2, U23.7 (CBUS2)
POWER_EN: U16.1 (A1), U16.5 (A2), U40.4 (Y); also elsewhere on the board
QOD: U21.5 (QOD), U22.5 (QOD)
RX: R38.1; also elsewhere on the board
SBU1: J10.A8 (SBU1)
SBU2: J10.B8 (SBU2)
TX: R40.1; also elsewhere on the board
VBUS_PRIME: C20.1, R65.2, U19.6 (OUT), U19.8 (OUT), U20.6 (OUT), U20.8 (OUT); also elsewhere on the board
VBUS_SEC: C19.1, R66.2, U17.6 (OUT), U17.8 (OUT), U18.6 (OUT), U18.8 (OUT); also elsewhere on the board
VUSB: C21.1, C22.1, F1.1, J10.A4B9 (VBUS), J10.B4A9 (VBUS), U23.12 (VCC)
VUSB_POWER: F1.2, R63.2; also elsewhere on the board
V_BETA: U22.1 (VIN); also elsewhere on the board
V_HP: U21.6 (VOUT), U22.6 (VOUT); also elsewhere on the board
V_PRIME: U21.1 (VIN); also elsewhere on the board

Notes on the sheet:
USB & ISP
Check current rating!!

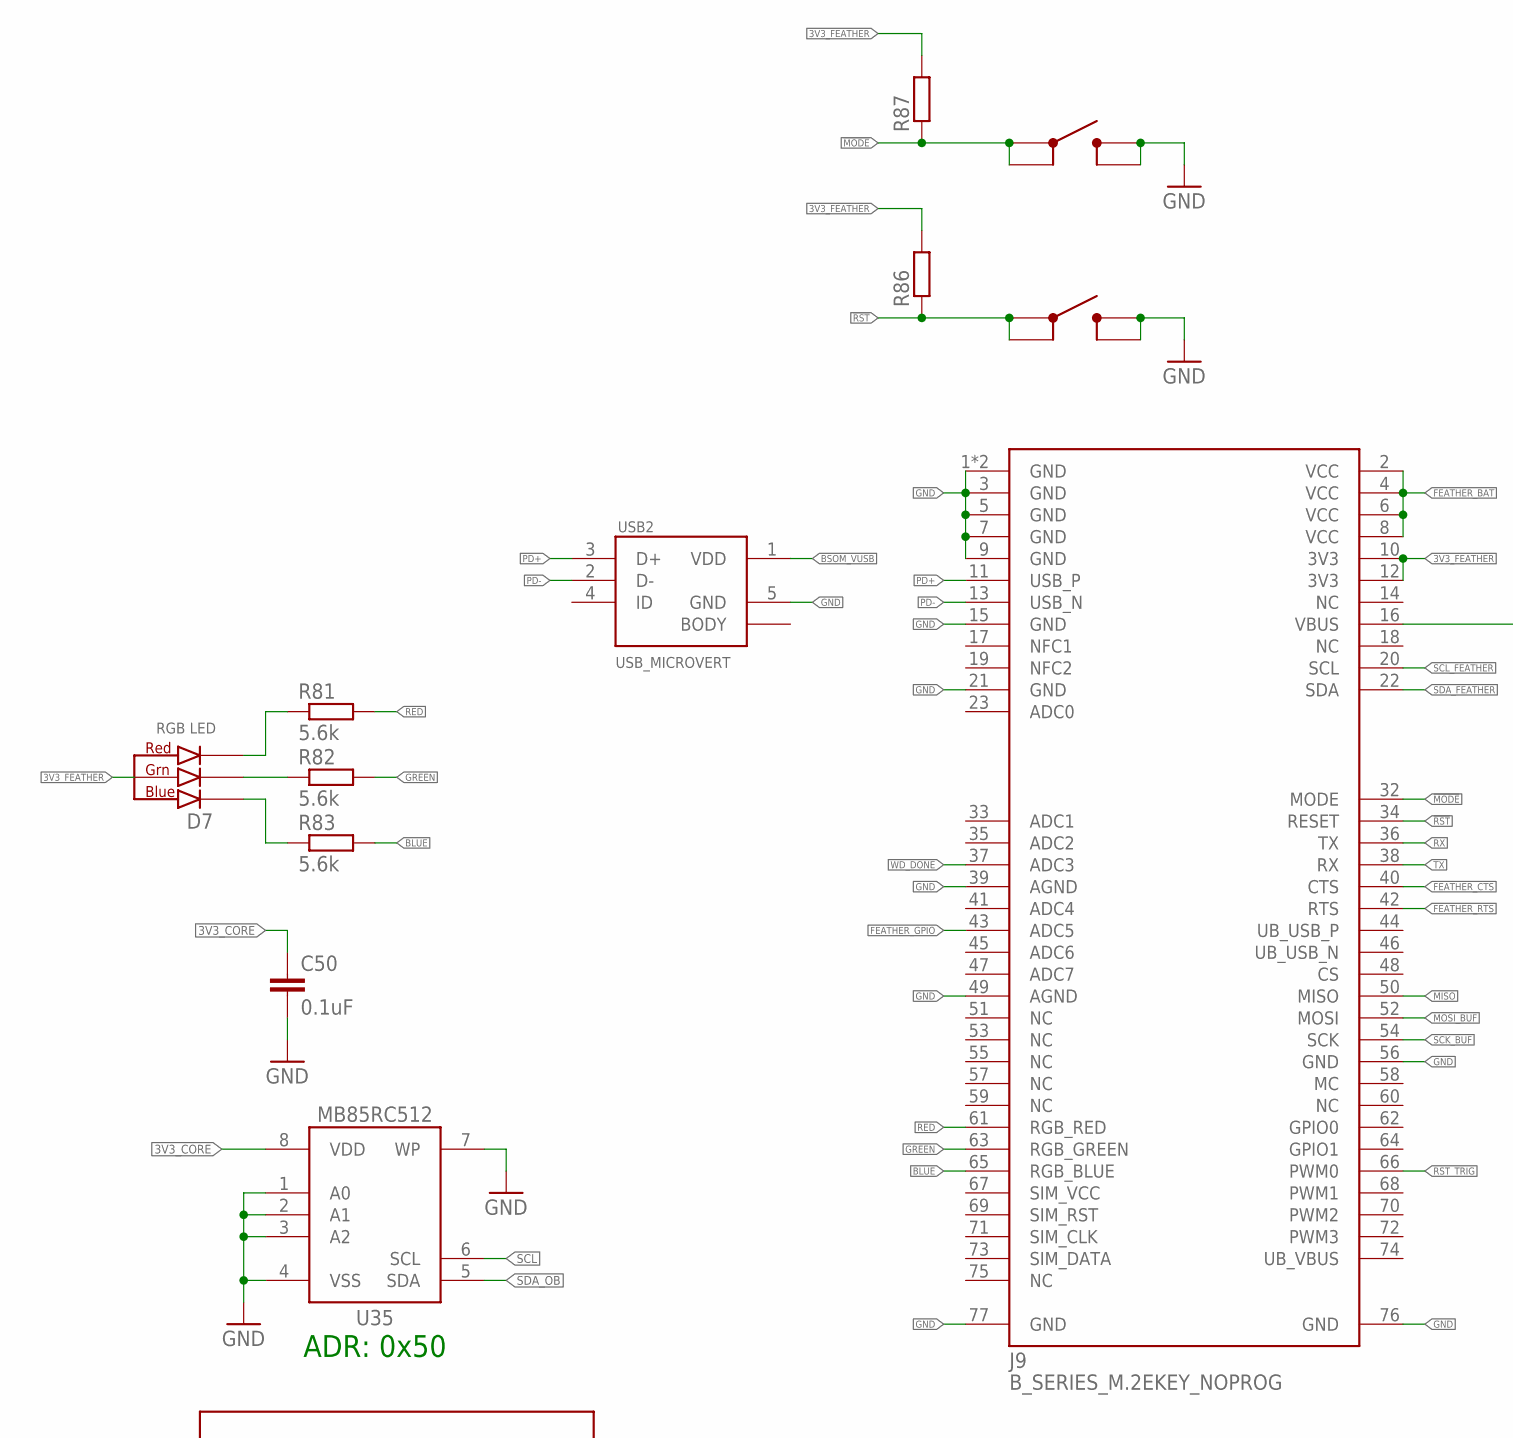
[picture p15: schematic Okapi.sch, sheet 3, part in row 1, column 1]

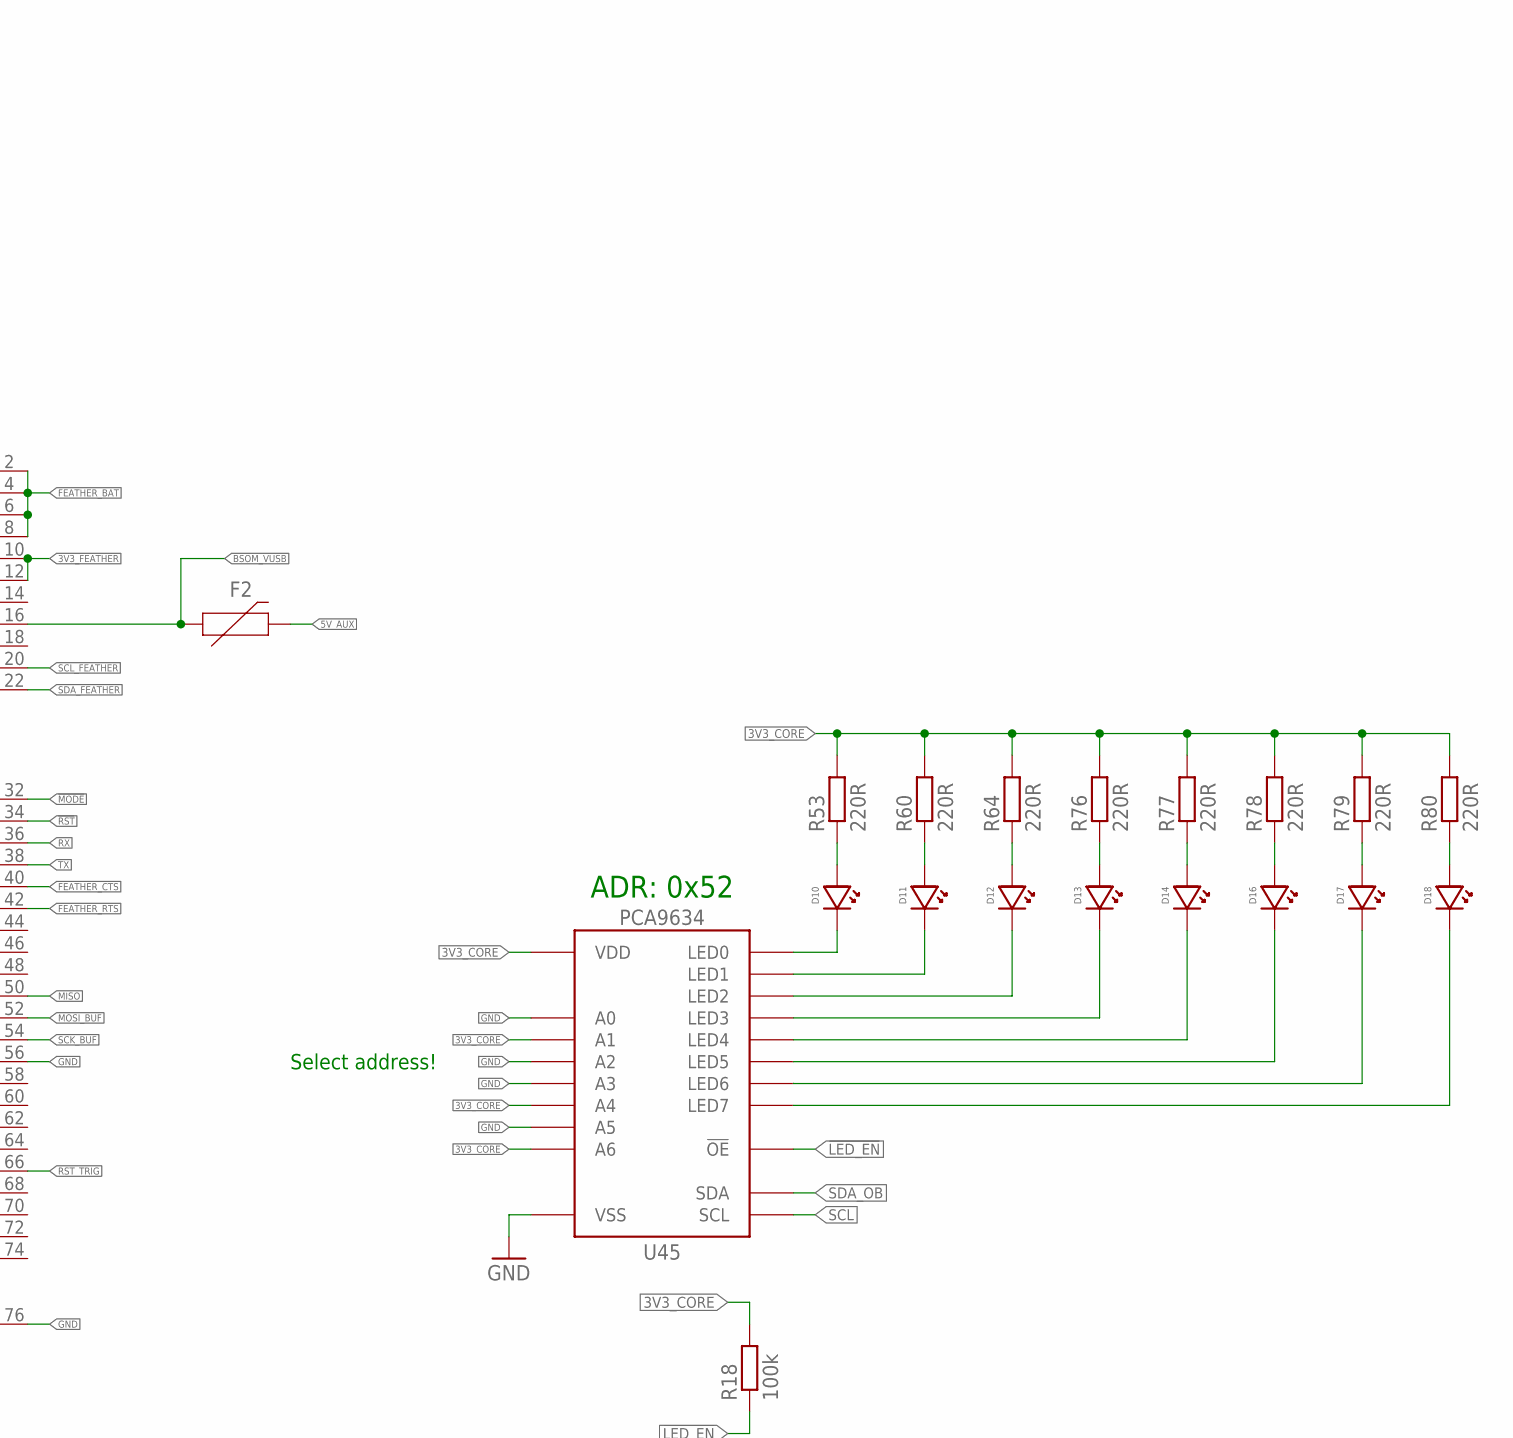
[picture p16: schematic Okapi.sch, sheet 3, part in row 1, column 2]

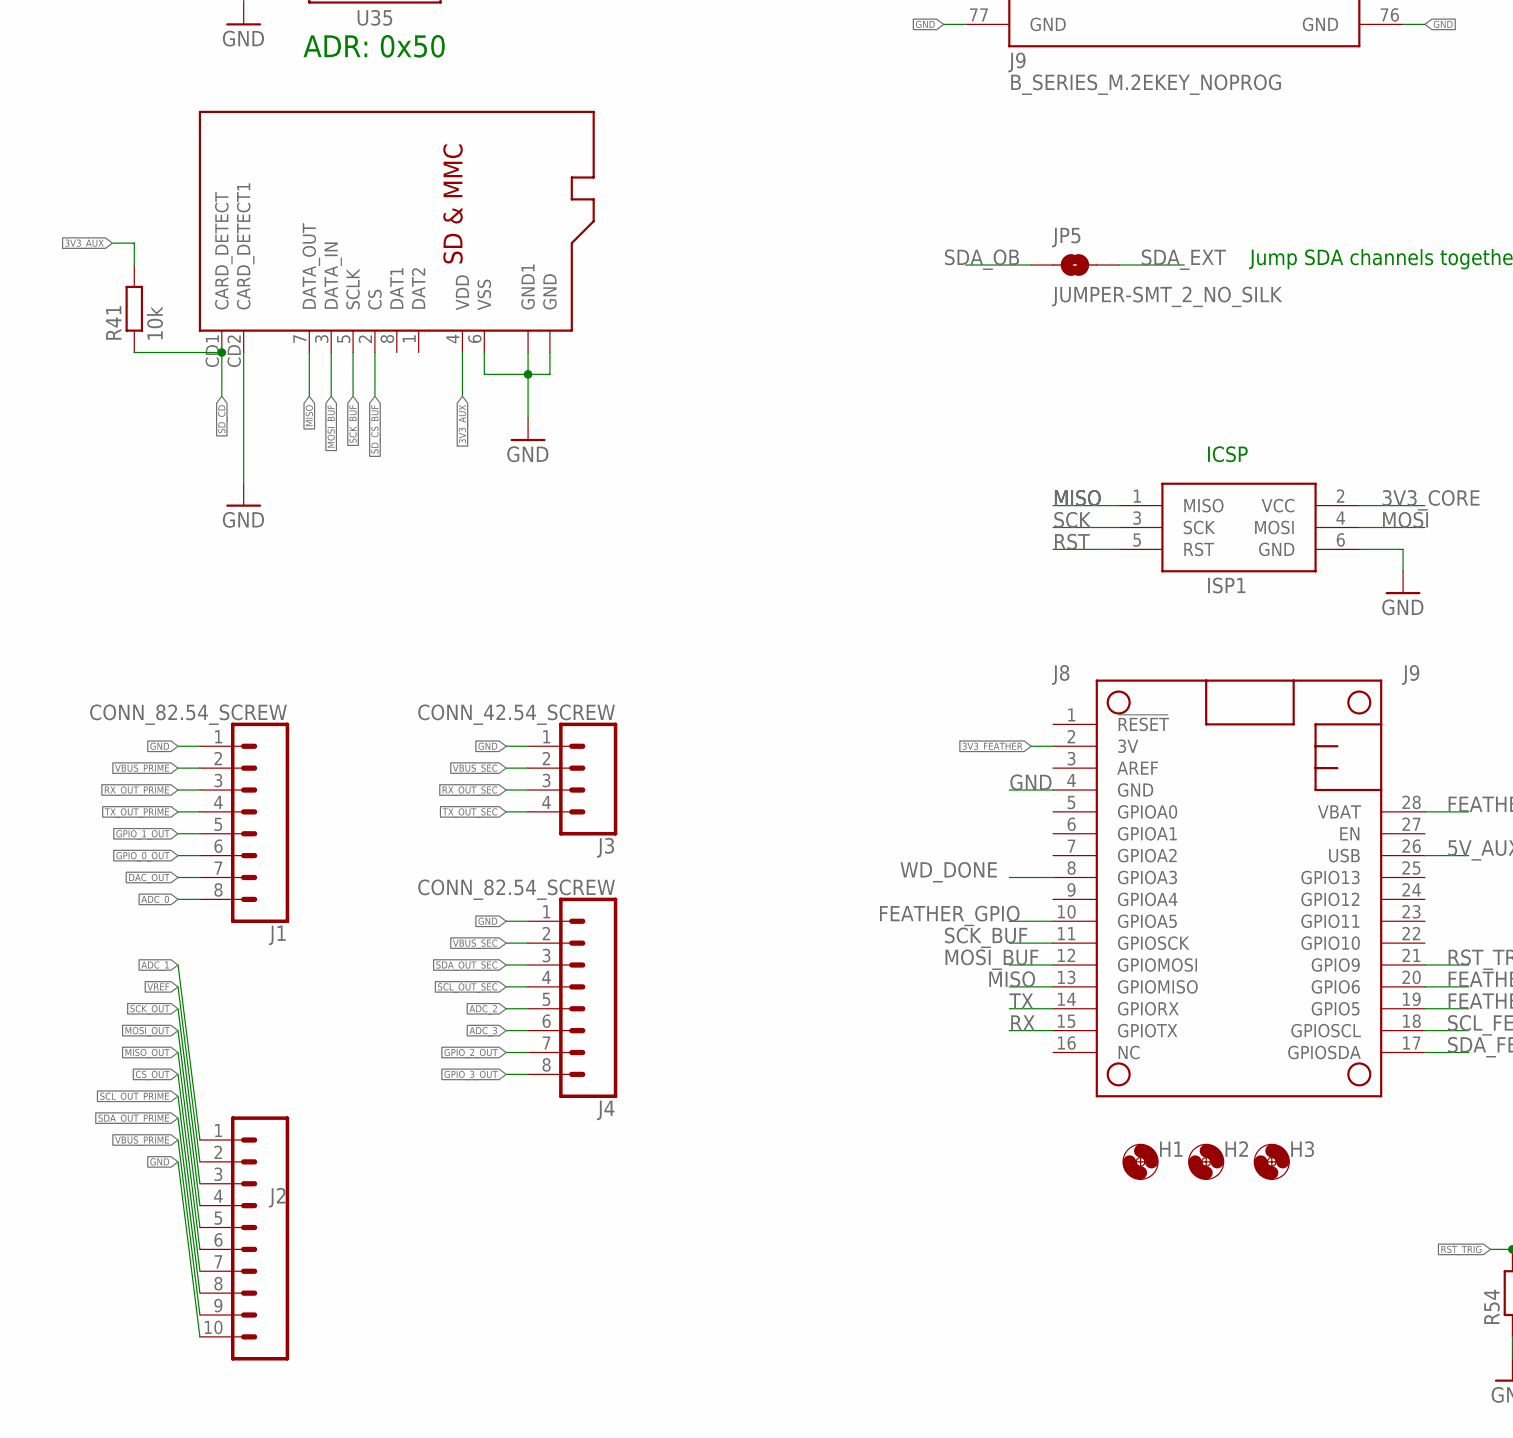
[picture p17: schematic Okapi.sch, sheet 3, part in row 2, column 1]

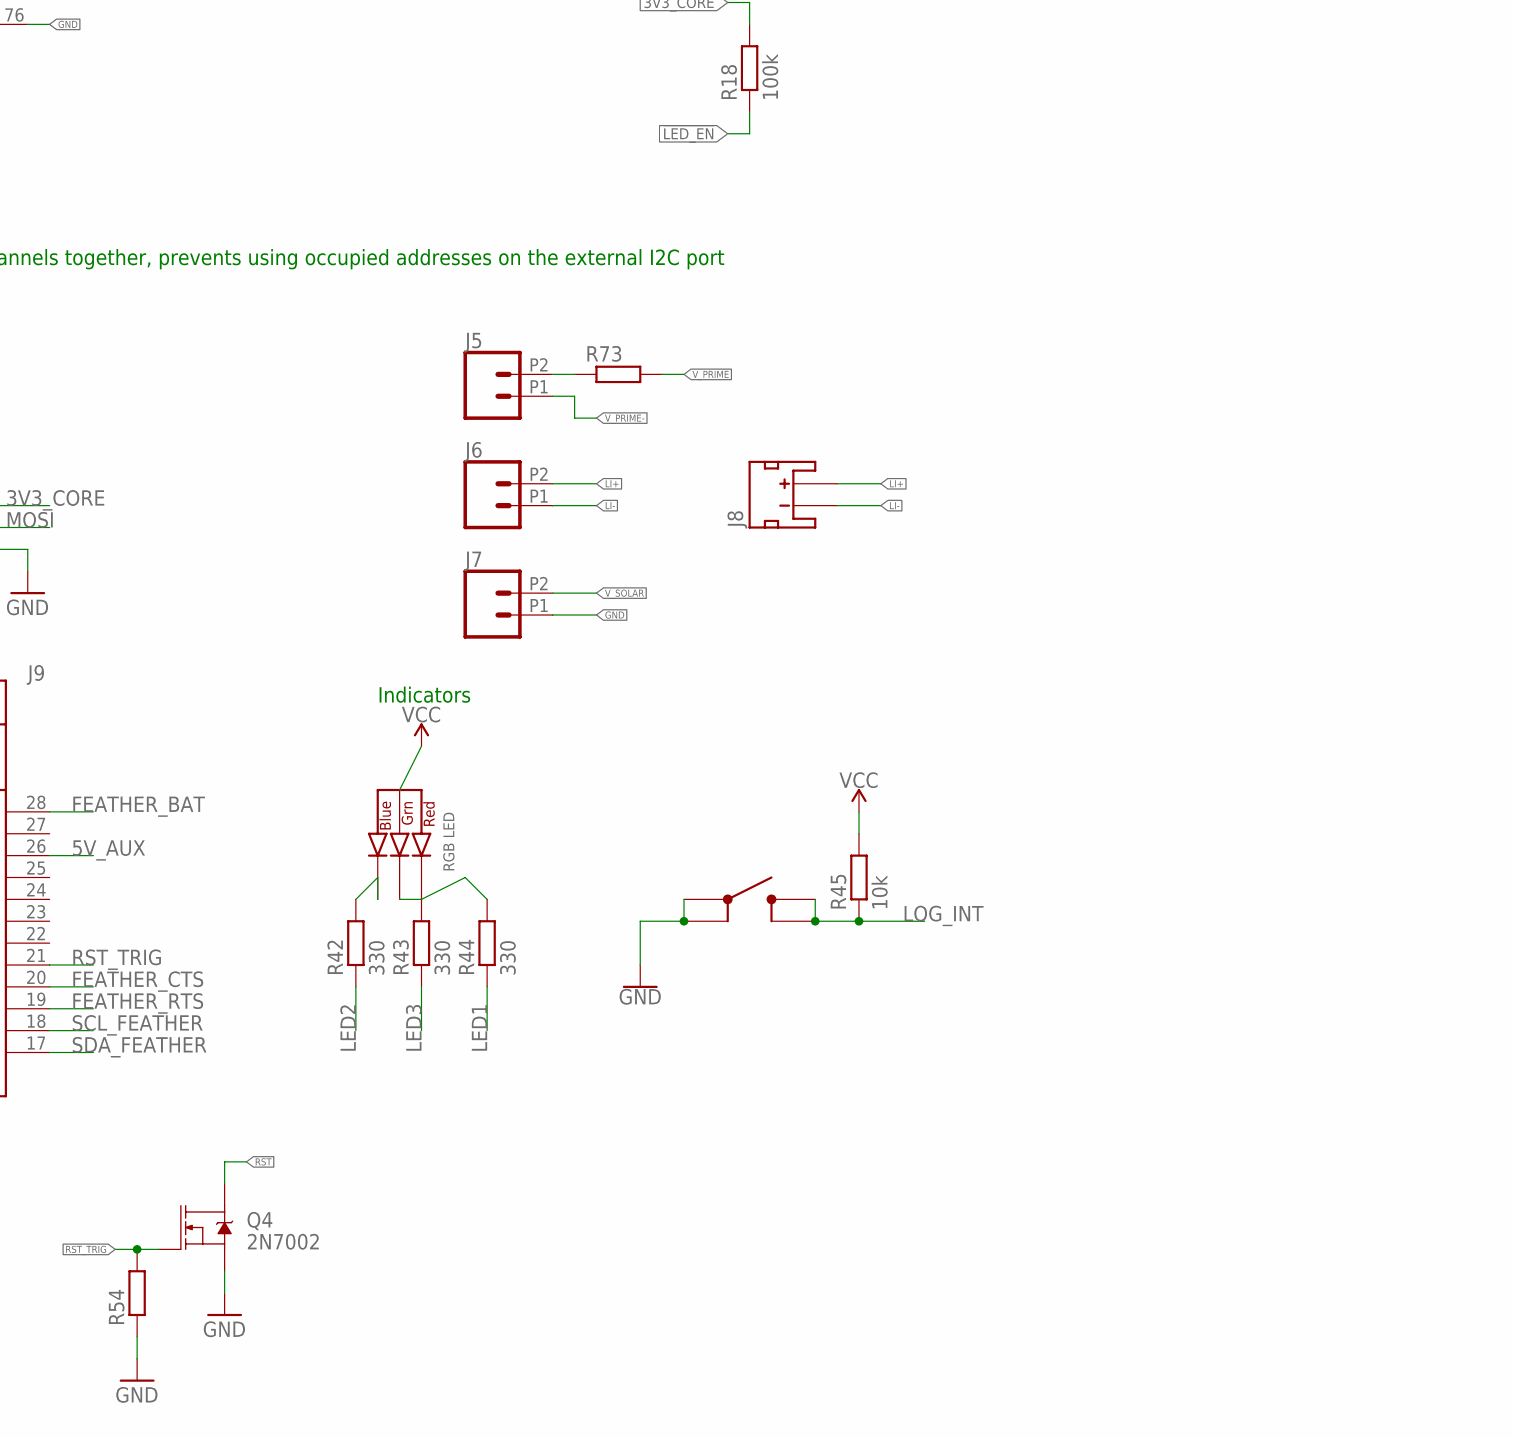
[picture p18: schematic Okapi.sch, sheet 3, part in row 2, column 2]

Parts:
C50: 0.1uF; C0402
D5, D7: CLVBA-FKA
D10, D13, D16: LEDGREEN0603; LED_0603
D11, D14, D17: LEDYELLOW0603; LED_0603
D12, D18: LEDRED0603; LED_0603
F2: PPTC1.5A; 1206
H1, H2, H3: MOUNTING_HOLE4_NP; 4_40
ISP1: AVRISP-6; AVRISP; MPN 67997-206HLF; DIGIKEY 609-3234-ND
J1, J4: CONN_82.54_SCREW; 1X08_SCREW
J2: CONN_102.54_SCREW; 1X10_SCREW
J3: CONN_42.54_SCREW; 1X04_SCREW
J5, J6, J7: CONN_022.54_SCREW; 1X02_2.54_SCREWTERM
J8: JST_2MM_MALE; JST-2-SMD
J9: B_SERIES_M.2EKEY_NOPROG; PARTICLE_M.2EKEY_NOPROG
JP5: JUMPER-SMT_2_NO_SILK; SMT-JUMPER_2_NO_SILK
MS1: FEATHERWINGLAYOUT; FEATHERWING_MIN
Q4: 2N7002; SOT323
R18: 100k; R0402
R41: 10k; R0402
R42, R43, R44: 330; R0402; MPN RC0603FR-07330RL
R45: 10k; R0402; DIGIKEY 311-10.0KHRCT-ND
R53, R60, R64, R76, R77, R78, R79, R80: 220R; R0402
R54, R86, R87: R-EU_10KR0402; R0402
R73: R-EU_R0805; R0805
R81, R82, R83: 5.6k; R0402
S3, S6, S7: BUTTON4.2X3.2; SWITCH_4.2X3.2
SD1: MICROSDCD; MICROSD_CD
U35: MB85RC; SO08
U45: PCA9634QFN; QFN20_5X5
USB2: USB_MICROVERT; USB_MICRO_VERT_MOLEX

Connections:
3V3_AUX: R41.2, SD1.4 (VDD); also elsewhere on the board
3V3_CORE: C50.1, D5.2 (ANODE), ISP1.2 (VCC), R18.2, R45.2, R53.2, R60.2, R64.2, R76.2, R77.2, R78.2, R79.2, R80.2, U35.8 (VDD), U45.3 (A4), U45.15 (A6), U45.18 (VDD), U45.20 (A1); also elsewhere on the board
3V3_FEATHER: D7.2 (ANODE), J9.10 (3V3), J9.12 (3V3), MS1.2 (3V), R86.2, R87.2; also elsewhere on the board
5V_AUX: F2.2, MS1.26 (USB); also elsewhere on the board
!LED_EN: R18.1, U45.13 (!OE); also elsewhere on the board
!MODE: J9.32 (MODE), R87.1, S6.1, S6.2
!RST: J9.34 (RESET), R86.1, S7.1, S7.2
ADC_0: J1.8; also elsewhere on the board
ADC_1: J2.1; also elsewhere on the board
ADC_2: J4.5; also elsewhere on the board
ADC_3: J4.6; also elsewhere on the board
BLUE: J9.65 (RGB_BLUE), R83.2
BSOM_VUSB: F2.1, J9.16 (VBUS), USB2.1 (VDD)
CS_OUT: J2.6; also elsewhere on the board
DAC_OUT: J1.7; also elsewhere on the board
FEATHER_BAT: J9.2 (VCC), J9.4 (VCC), J9.6 (VCC), J9.8 (VCC), MS1.28 (VBAT); also elsewhere on the board
FEATHER_CTS: J9.40 (CTS), MS1.20 (GPIO6); also elsewhere on the board
FEATHER_GPIO: J9.43 (ADC5), MS1.10 (GPIOA5); also elsewhere on the board
FEATHER_RTS: J9.42 (RTS), MS1.19 (GPIO5); also elsewhere on the board
GND: C50.2, ISP1.6 (GND), J1.1, J2.10, J3.1, J4.1, J7.P1 (1), J9.1 (GND), J9.3 (GND), J9.5 (GND), J9.7 (GND), J9.9 (GND), J9.15 (GND), J9.21 (GND), J9.39 (AGND), J9.49 (AGND), J9.56 (GND), J9.76 (GND), J9.77 (GND), J9.GND, MS1.4 (GND), Q4.2 (S), R54.1, S3.1, S3.2, S6.3 (4), S6.4 (3), S7.3 (4), S7.4 (3), SD1.6 (VSS), SD1.CD2 (CARD_DETECT1), SD1.MT1 (GND), SD1.MT2 (GND1), SD1.MT3 (GND1), SD1.MT4 (GND1), U35.1 (A0), U35.2 (A1), U35.3 (A2), U35.4 (VSS), U35.7 (WP), U45.1 (A2), U45.2 (A3), U45.8 (VSS), U45.14 (A5), U45.19 (A0), U45.EP (VSS), USB2.5 (GND); also elsewhere on the board
GPIO_0_OUT: J1.6; also elsewhere on the board
GPIO_1_OUT: J1.5; also elsewhere on the board
GPIO_2_OUT: J4.7; also elsewhere on the board
GPIO_3_OUT: J4.8; also elsewhere on the board
GREEN: J9.63 (RGB_GREEN), R82.2
LED1: R44.1; also elsewhere on the board
LED2: R42.1; also elsewhere on the board
LED3: R43.1; also elsewhere on the board
LI+: J6.P2 (2), J8.2 (+); also elsewhere on the board
LI-: J6.P1 (1), J8.1 (-); also elsewhere on the board
LOG_INT: R45.1, S3.3 (4), S3.4 (3); also elsewhere on the board
MISO: ISP1.1 (MISO), J9.50 (MISO), MS1.13 (GPIOMISO), SD1.7 (DATA_OUT); also elsewhere on the board
MISO_OUT: J2.5; also elsewhere on the board
MOSI: ISP1.4 (MOSI); also elsewhere on the board
MOSI_BUF: J9.52 (MOSI), MS1.12 (GPIOMOSI), SD1.3 (DATA_IN); also elsewhere on the board
MOSI_OUT: J2.4; also elsewhere on the board
unnamed: D10.CATHODE, U45.4 (LED0)
unnamed: D5.3 (BLUE_CATH), R42.2
unnamed: D5.4 (GREEN_CATH), R43.2
unnamed: D5.1 (RED_CATH), R44.2
unnamed: D11.CATHODE, U45.5 (LED1)
unnamed: D12.CATHODE, U45.6 (LED2)
unnamed: D13.CATHODE, U45.7 (LED3)
unnamed: D14.CATHODE, U45.9 (LED4)
unnamed: D16.CATHODE, U45.10 (LED5)
unnamed: D17.CATHODE, U45.11 (LED6)
unnamed: D18.CATHODE, U45.12 (LED7)
unnamed: D10.ANODE, R53.1
unnamed: D11.ANODE, R60.1
unnamed: D12.ANODE, R64.1
unnamed: D13.ANODE, R76.1
unnamed: D14.ANODE, R77.1
unnamed: D16.ANODE, R78.1
unnamed: D17.ANODE, R79.1
unnamed: D18.ANODE, R80.1
unnamed: D7.1 (RED_CATH), R81.1
unnamed: D7.4 (GREEN_CATH), R82.1
unnamed: D7.3 (BLUE_CATH), R83.1
PD+: J9.11 (USB_P), USB2.3 (D+)
PD-: J9.13 (USB_N), USB2.2 (D-)
RED: J9.61 (RGB_RED), R81.2
RST: ISP1.5 (RST), Q4.3 (D); also elsewhere on the board
RST_TRIG: J9.66 (PWM0), MS1.21 (GPIO9), Q4.1 (G), R54.2
RX: J9.36 (TX), MS1.15 (GPIOTX); also elsewhere on the board
RX_OUT_PRIME: J1.3; also elsewhere on the board
RX_OUT_SEC: J3.3; also elsewhere on the board
SCK: ISP1.3 (SCK); also elsewhere on the board
SCK_BUF: J9.54 (SCK), MS1.11 (GPIOSCK), SD1.5 (SCLK); also elsewhere on the board
SCK_OUT: J2.3; also elsewhere on the board
SCL: U35.6 (SCL), U45.16 (SCL); also elsewhere on the board
SCL_FEATHER: J9.20 (SCL), MS1.18 (GPIOSCL); also elsewhere on the board
SCL_OUT_PRIME: J2.7; also elsewhere on the board
SCL_OUT_SEC: J4.4; also elsewhere on the board
SDA_EXT: JP5.2; also elsewhere on the board
SDA_FEATHER: J9.22 (SDA), MS1.17 (GPIOSDA); also elsewhere on the board
SDA_OB: JP5.1, U35.5 (SDA), U45.17 (SDA); also elsewhere on the board
SDA_OUT_PRIME: J2.8; also elsewhere on the board
SDA_OUT_SEC: J4.3; also elsewhere on the board
SD_CD: R41.1, SD1.CD1 (CARD_DETECT); also elsewhere on the board
SD_CS_BUF: SD1.2 (CS); also elsewhere on the board
SIM_VCC: J9.67 (SIM_VCC)
TX: J9.38 (RX), MS1.14 (GPIORX); also elsewhere on the board
TX_OUT_PRIME: J1.4; also elsewhere on the board
TX_OUT_SEC: J3.4; also elsewhere on the board
UB_VBUS: J9.74 (UB_VBUS)
VBUS_PRIME: J1.2, J2.9; also elsewhere on the board
VBUS_SEC: J3.2, J4.2; also elsewhere on the board
VREF: J2.2; also elsewhere on the board
V_PRIME: R73.2; also elsewhere on the board
V_PRIME-: J5.P1 (1); also elsewhere on the board
V_PRIME_SENSE: J5.P2 (2), R73.1; also elsewhere on the board
V_SOLAR: J7.P2 (2); also elsewhere on the board
WD_DONE: J9.37 (ADC3), MS1.8 (GPIOA3); also elsewhere on the board

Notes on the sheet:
Indicators
ICSP
Jump SDA channels together, prevents using occupied addresses on the external I2C port
ADR: 0x50
Select address!
ADR: 0x52

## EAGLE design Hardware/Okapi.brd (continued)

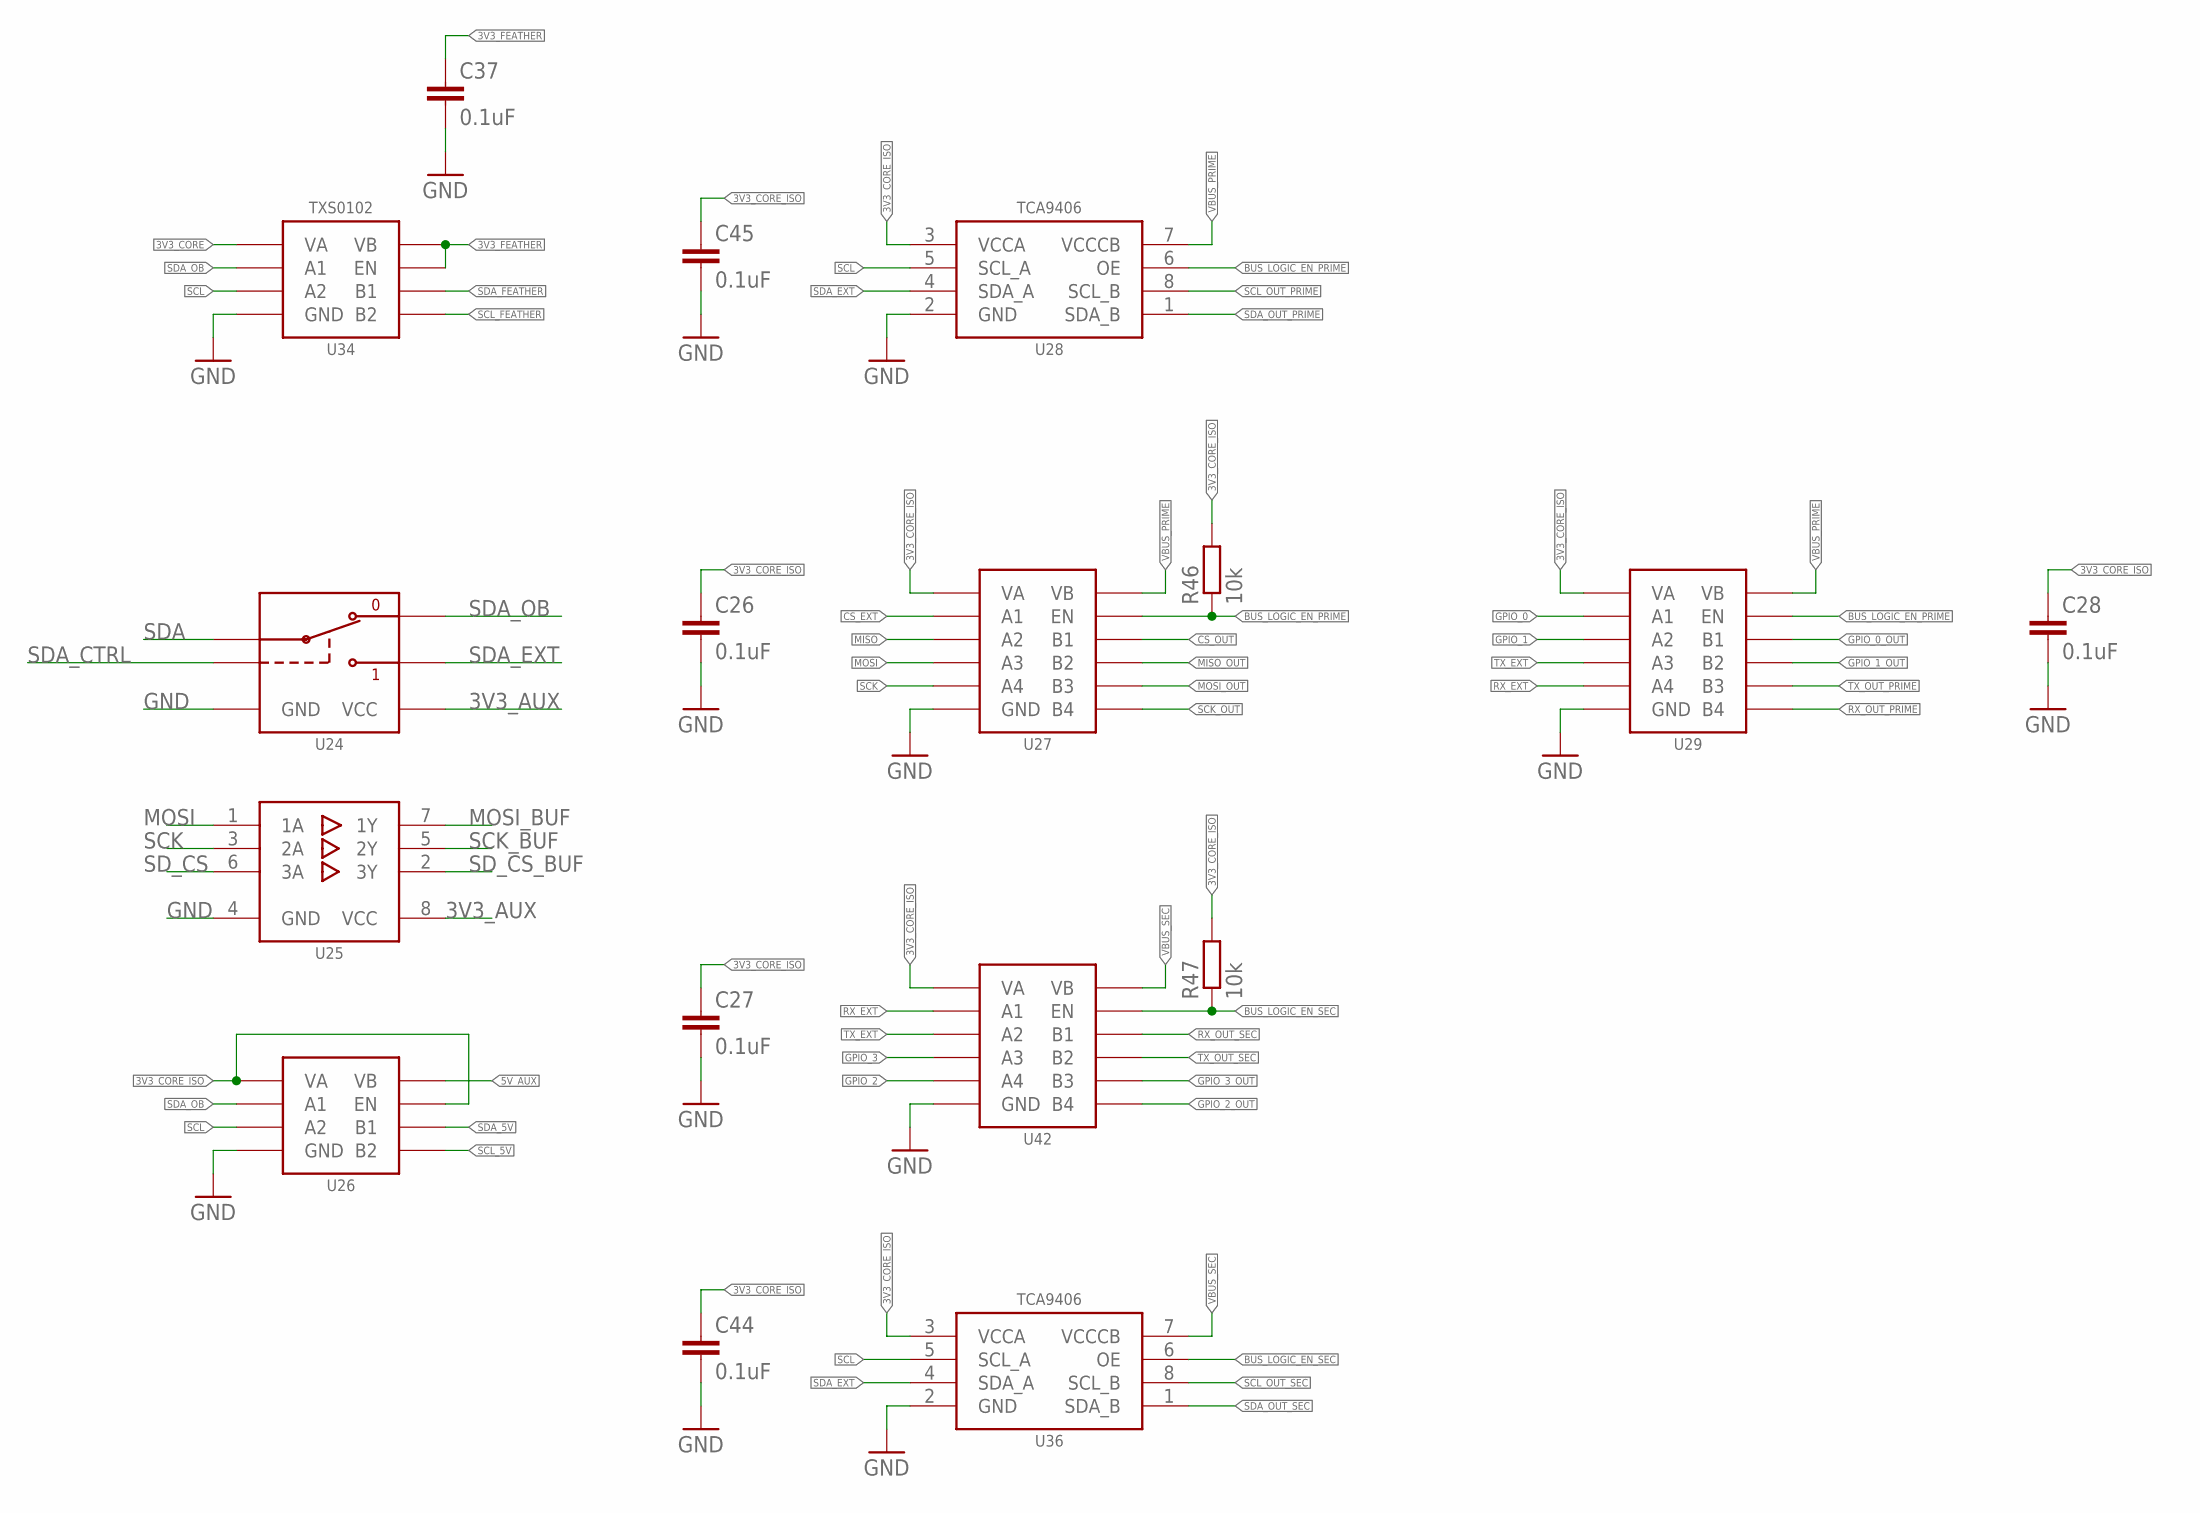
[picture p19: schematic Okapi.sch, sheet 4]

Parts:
C26, C27, C28, C37, C44, C45: 0.1uF; C0402
R46, R47: 10k; R0402
U24: SN74LVC1G3157DRL; DRL_R-PDSO-N6
U25: SN74AUP3G34DCU; DCU_(R-PDSO-G8)
U26, U34: TXS0102DQM; DQM_R-PX2SON-N8
U27, U29, U42: TXS0104RGY; RGY_S-PVQFN-N14
U28, U36: TCA9406DCU; DCU_(R-PDSO-G8)

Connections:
3V3_AUX: U24.5 (VCC), U25.8 (VCC); also elsewhere on the board
3V3_CORE: U34.1 (VA); also elsewhere on the board
3V3_CORE_ISO: C26.1, C27.1, C28.1, C44.1, C45.1, R46.2, R47.2, U26.1 (VA), U26.5 (EN), U27.1 (VA), U28.3 (VCCA), U29.1 (VA), U36.3 (VCCA), U42.1 (VA); also elsewhere on the board
3V3_FEATHER: C37.1, U34.5 (EN), U34.8 (VB); also elsewhere on the board
5V_AUX: U26.8 (VB); also elsewhere on the board
BUS_LOGIC_EN_PRIME: R46.1, U27.8 (EN), U28.6 (OE), U29.8 (EN); also elsewhere on the board
BUS_LOGIC_EN_SEC: R47.1, U36.6 (OE), U42.8 (EN); also elsewhere on the board
CS_EXT: U27.2 (A1); also elsewhere on the board
CS_OUT: U27.13 (B1); also elsewhere on the board
GND: C26.2, C27.2, C28.2, C37.2, C44.2, C45.2, U24.2 (GND), U25.4 (GND), U26.4 (GND), U27.7 (GND), U27.EP (GND), U28.2 (GND), U29.7 (GND), U29.EP (GND), U34.4 (GND), U36.2 (GND), U42.7 (GND), U42.EP (GND); also elsewhere on the board
GPIO_0: U29.2 (A1); also elsewhere on the board
GPIO_0_OUT: U29.13 (B1); also elsewhere on the board
GPIO_1: U29.3 (A2); also elsewhere on the board
GPIO_1_OUT: U29.12 (B2); also elsewhere on the board
GPIO_2: U42.5 (A4); also elsewhere on the board
GPIO_2_OUT: U42.10 (B4); also elsewhere on the board
GPIO_3: U42.4 (A3); also elsewhere on the board
GPIO_3_OUT: U42.11 (B3); also elsewhere on the board
MISO: U27.3 (A2); also elsewhere on the board
MISO_OUT: U27.12 (B2); also elsewhere on the board
MOSI: U25.1 (1A), U27.4 (A3); also elsewhere on the board
MOSI_BUF: U25.7 (1Y); also elsewhere on the board
MOSI_OUT: U27.11 (B3); also elsewhere on the board
RX_EXT: U29.5 (A4), U42.2 (A1); also elsewhere on the board
RX_OUT_PRIME: U29.10 (B4); also elsewhere on the board
RX_OUT_SEC: U42.13 (B1); also elsewhere on the board
SCK: U25.3 (2A), U27.5 (A4); also elsewhere on the board
SCK_BUF: U25.5 (2Y); also elsewhere on the board
SCK_OUT: U27.10 (B4); also elsewhere on the board
SCL: U26.3 (A2), U28.5 (SCL_A), U34.3 (A2), U36.5 (SCL_A); also elsewhere on the board
SCL_5V: U26.6 (B2); also elsewhere on the board
SCL_FEATHER: U34.6 (B2); also elsewhere on the board
SCL_OUT_PRIME: U28.8 (SCL_B); also elsewhere on the board
SCL_OUT_SEC: U36.8 (SCL_B); also elsewhere on the board
SDA: U24.4 (A); also elsewhere on the board
SDA_5V: U26.7 (B1); also elsewhere on the board
SDA_CTRL: U24.6 (S); also elsewhere on the board
SDA_EXT: U24.1 (B2), U28.4 (SDA_A), U36.4 (SDA_A); also elsewhere on the board
SDA_FEATHER: U34.7 (B1); also elsewhere on the board
SDA_OB: U24.3 (B1), U26.2 (A1), U34.2 (A1); also elsewhere on the board
SDA_OUT_PRIME: U28.1 (SDA_B); also elsewhere on the board
SDA_OUT_SEC: U36.1 (SDA_B); also elsewhere on the board
SD_CS: U25.6 (3A); also elsewhere on the board
SD_CS_BUF: U25.2 (3Y); also elsewhere on the board
TX_EXT: U29.4 (A3), U42.3 (A2); also elsewhere on the board
TX_OUT_PRIME: U29.11 (B3); also elsewhere on the board
TX_OUT_SEC: U42.12 (B2); also elsewhere on the board
VBUS_PRIME: U27.14 (VB), U28.7 (VCCCB), U29.14 (VB); also elsewhere on the board
VBUS_SEC: U36.7 (VCCCB), U42.14 (VB); also elsewhere on the board

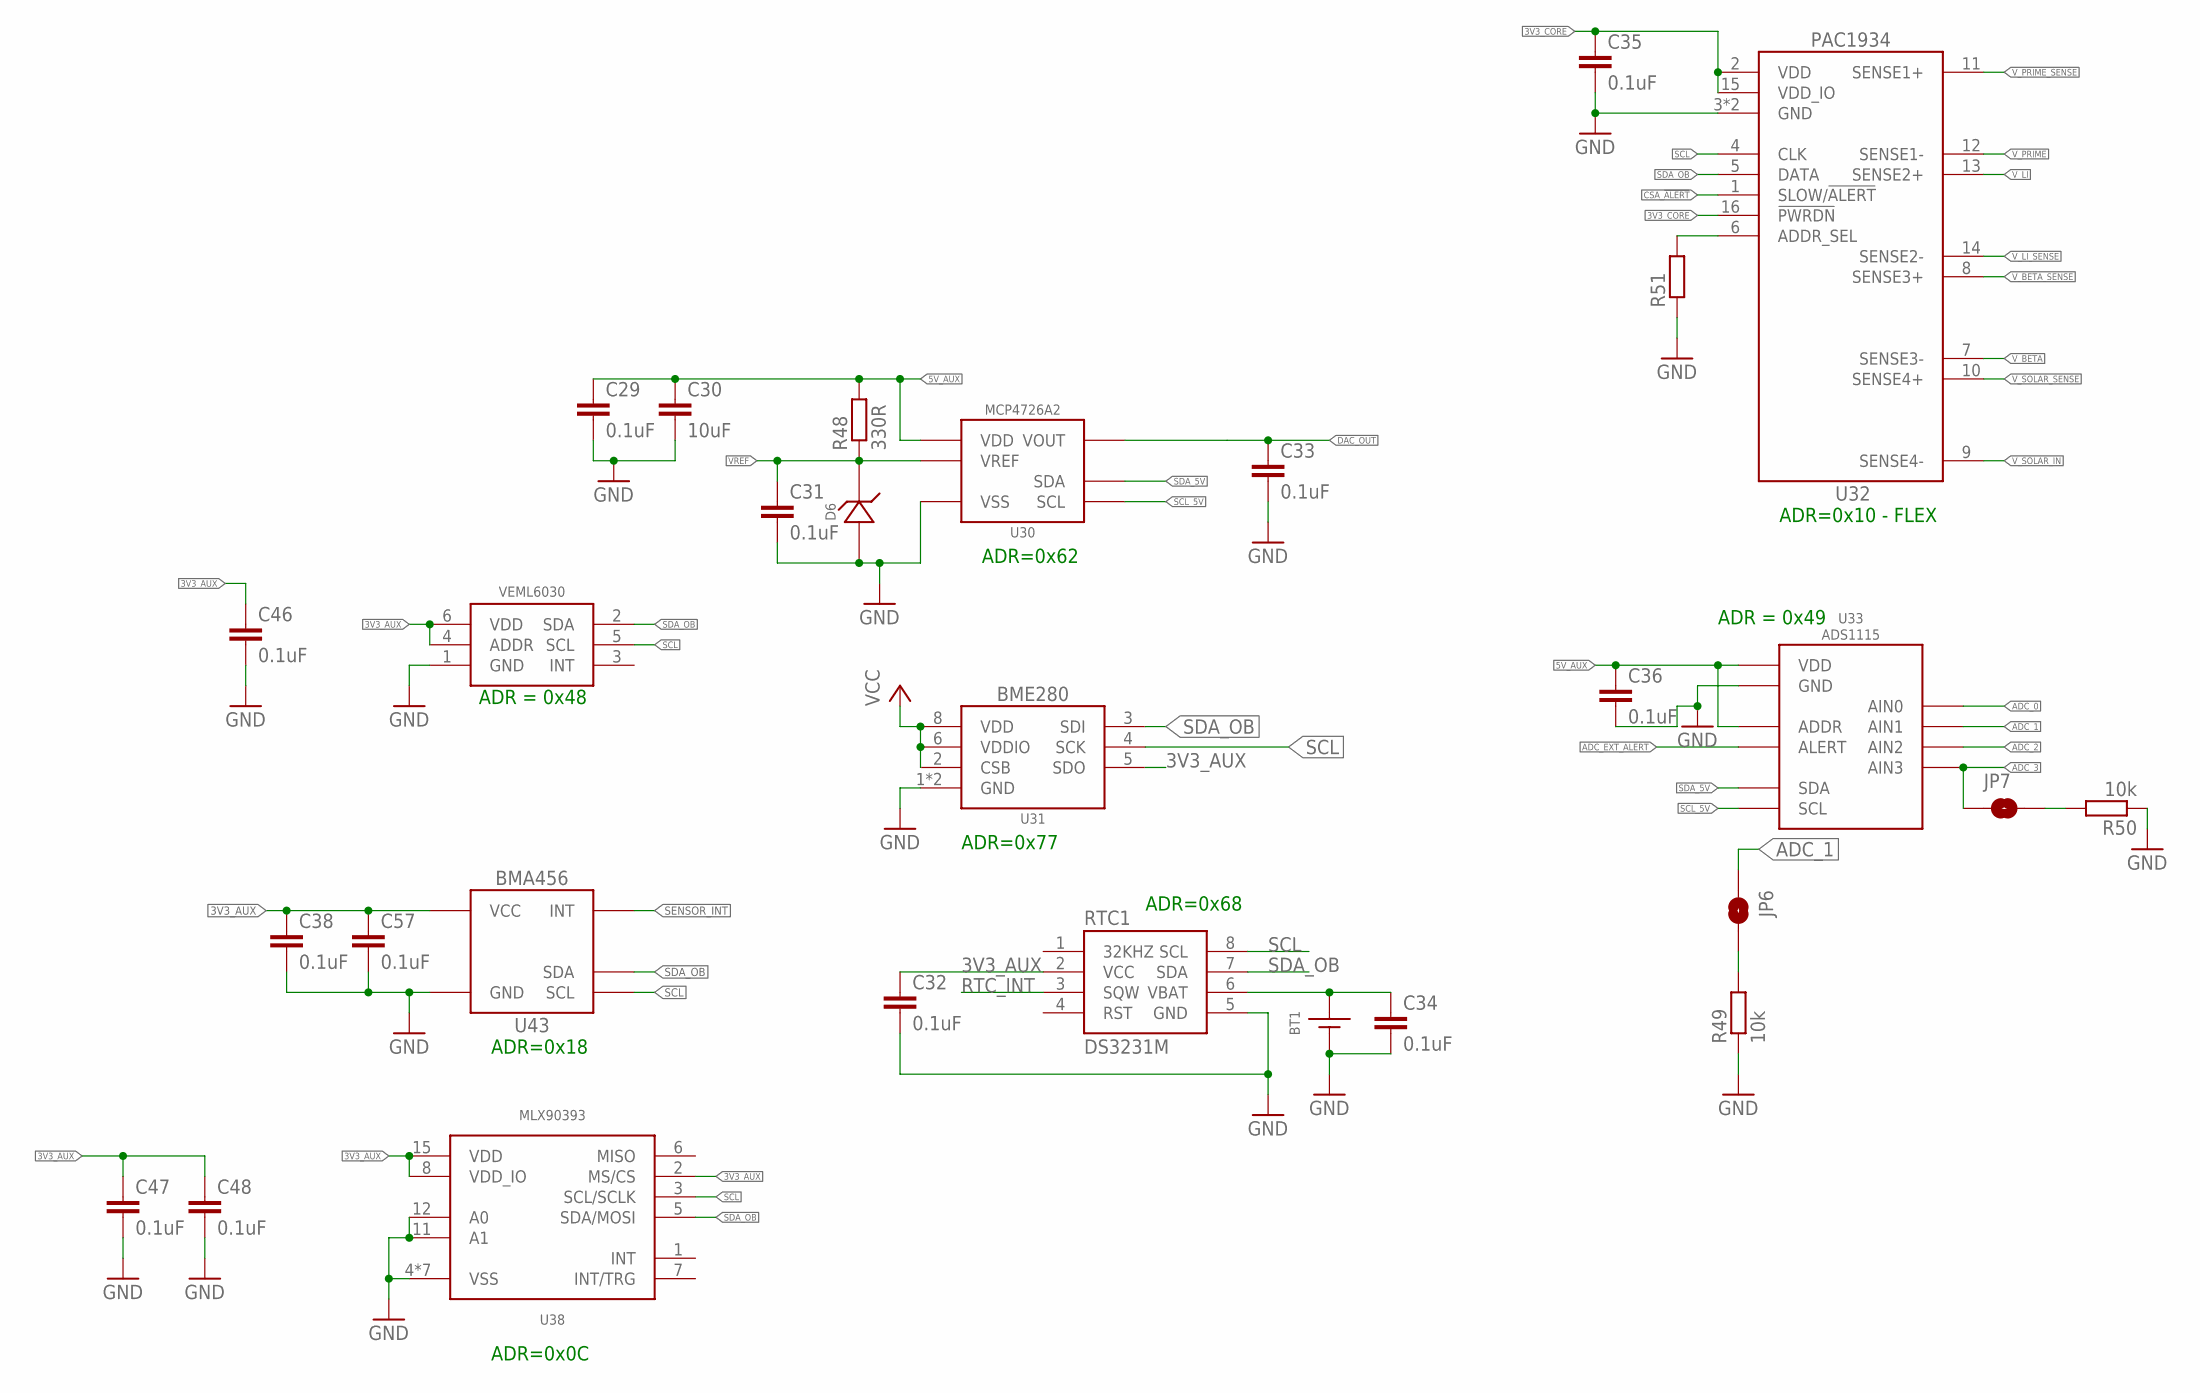
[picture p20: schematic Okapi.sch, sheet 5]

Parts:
BT1: BATTERY_COIN12MM; LINX_BAT-HLD-012-SMT
C29, C31, C32, C33, C34, C35, C36, C38, C46, C47, C48, C57: 0.1uF; C0402
C30: 10uF; C0805
D6: LM40402.5; SOT23-3
JP6, JP7: JUMPER-SMT_2_NO_SILK; SMT-JUMPER_2_NO_SILK
R48: 330R; R0603
R49, R50: 10k; R0603
R51: R-EU_R0402; R0402
RTC1: DS3231M; SO08
U30: MCP4726A2SOT-23; SOT23-6L
U31: BME280
U32: PAC1934QFN; QFN16
U33: ADS1115; VSSOP_10
U38: MLX90393; QFN16_3X3
U43: BMA456; LGA-12_2X2
U44: VEML6030

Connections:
3V3_AUX: C32.1, C38.1, C46.1, C47.1, C48.1, C57.1, RTC1.2 (VCC), U31.2 (CSB), U31.5 (SDO), U31.6 (VDDIO), U31.8 (VDD), U38.2 (MS/CS), U38.8 (VDD_IO), U38.15 (VDD), U43.3 (VCC), U43.7 (VCC), U43.10 (VCC), U44.4 (ADDR), U44.6 (VDD); also elsewhere on the board
3V3_CORE: C35.1, U32.2 (VDD), U32.15 (VDD_IO), U32.16 (!PWRDN); also elsewhere on the board
5V_AUX: C29.1, C30.1, C36.1, R48.2, U30.3 (VDD), U33.1 (ADDR), U33.8 (VDD); also elsewhere on the board
ADC_0: U33.4 (AIN0); also elsewhere on the board
ADC_1: JP6.1, U33.5 (AIN1); also elsewhere on the board
ADC_2: U33.6 (AIN2); also elsewhere on the board
ADC_3: JP7.1, U33.7 (AIN3); also elsewhere on the board
ADC_EXT_ALERT: U33.2 (ALERT); also elsewhere on the board
CSA_!ALERT: U32.1 (SLOW/!ALERT); also elsewhere on the board
DAC_OUT: C33.1, U30.1 (VOUT); also elsewhere on the board
GND: BT1.GND (-), C29.2, C30.2, C31.2, C32.2, C33.2, C34.2, C35.2, C36.2, C38.2, C46.2, C47.2, C48.2, C57.2, D6.2 (A), R49.1, R50.1, R51.1, RTC1.5 (GND), U30.2 (VSS), U31.1 (GND), U31.7 (GND), U32.3 (GND), U32.EP (GND), U33.3 (GND), U38.4 (VSS), U38.9 (VSS), U38.10 (VSS), U38.11 (A1), U38.12 (A0), U38.13 (VSS), U38.14 (VSS), U38.16 (VSS), U38.EP (VSS), U43.1 (GND), U43.8 (GND), U43.9 (GND), U44.1 (GND); also elsewhere on the board
unnamed: R51.2, U32.6 (ADDR_SEL)
unnamed: BT1.POWER0 (+), BT1.POWER1 (+), C34.1, RTC1.6 (VBAT)
unnamed: JP6.2, R49.2
unnamed: JP7.2, R50.2
RTC_INT: RTC1.3 (SQW); also elsewhere on the board
SCL: RTC1.8 (SCL), U31.4 (SCK), U32.4 (CLK), U38.3 (SCL/SCLK), U43.12 (SCL), U44.5 (SCL); also elsewhere on the board
SCL_5V: U30.5 (SCL), U33.10 (SCL); also elsewhere on the board
SDA_5V: U30.4 (SDA), U33.9 (SDA); also elsewhere on the board
SDA_OB: RTC1.7 (SDA), U31.3 (SDI), U32.5 (DATA), U38.5 (SDA/MOSI), U43.2 (SDA), U44.2 (SDA); also elsewhere on the board
SENSOR_INT: U43.5 (INT)
VREF: C31.1, D6.1 (C), R48.1, U30.6 (VREF); also elsewhere on the board
V_BETA: U32.7 (SENSE3-); also elsewhere on the board
V_BETA_SENSE: U32.8 (SENSE3+); also elsewhere on the board
V_LI: U32.13 (SENSE2+); also elsewhere on the board
V_LI_SENSE: U32.14 (SENSE2-); also elsewhere on the board
V_PRIME: U32.12 (SENSE1-); also elsewhere on the board
V_PRIME_SENSE: U32.11 (SENSE1+); also elsewhere on the board
V_SOLAR_IN: U32.9 (SENSE4-); also elsewhere on the board
V_SOLAR_SENSE: U32.10 (SENSE4+); also elsewhere on the board

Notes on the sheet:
ADR = 0x49
ADR = 0x48
ADR=0x77
ADR=0x18
ADR=0x68
ADR=0x10 - FLEX
ADR=0x62
ADR=0x0C

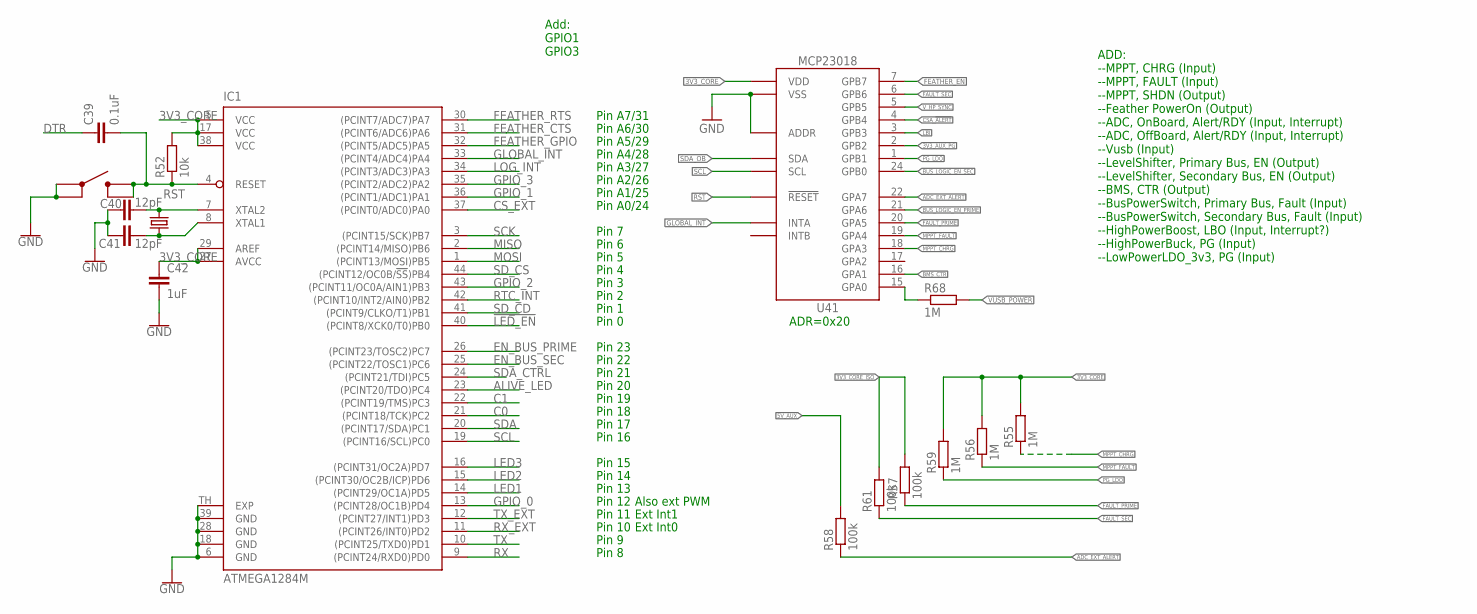
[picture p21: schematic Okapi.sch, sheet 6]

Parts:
C39: 0.1uF; C0402
C40, C41: 12pF; C0402; MPN CL10C120JB8NNNC; DIGIKEY 1276-1254-1-ND
C42: 1uF; C0402; MPN CL10B105MO8NNWC; DIGIKEY 1276-6524-1-ND
IC1: ATMEGA1284M; MLF44-TH
R52: 10k; R0402; DIGIKEY 311-10.0KHRCT-ND
R55, R56, R59, R68: 1M; R0402
R57, R58, R61: 100k; R0402
S4: BUTTON4.2X3.2; SWITCH_4.2X3.2
U41: MCP23018QFN; QFN24
XTAL1: CRYSTAL8MHZ5X3.2; CRYSTAL_5X3.2_2-SMD

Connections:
3V3_AUX_PG: U41.2 (GPB2); also elsewhere on the board
3V3_CORE: C42.1, IC1.5 (VCC), IC1.17 (VCC), IC1.27 (AVCC), IC1.29 (AREF), IC1.38 (VCC), R52.2, R55.2, R56.2, R59.2, U41.8 (VDD); also elsewhere on the board
3V3_CORE_ISO: R57.2, R61.2; also elsewhere on the board
5V_AUX: R58.2; also elsewhere on the board
!LED_EN: IC1.40 ((PCINT8/XCK0/T0)PB0); also elsewhere on the board
ADC_EXT_ALERT: R58.1, U41.22 (GPA7); also elsewhere on the board
ALIVE_LED: IC1.23 ((PCINT20/TDO)PC4); also elsewhere on the board
BMS_CTR: U41.16 (GPA1); also elsewhere on the board
BUS_LOGIC_EN_PRIME: U41.21 (GPA6); also elsewhere on the board
BUS_LOGIC_EN_SEC: U41.24 (GPB0); also elsewhere on the board
C0: IC1.21 ((PCINT18/TCK)PC2); also elsewhere on the board
C1: IC1.22 ((PCINT19/TMS)PC3); also elsewhere on the board
CSA_!ALERT: U41.4 (GPB4); also elsewhere on the board
CS_EXT: IC1.37 ((PCINT0/ADC0)PA0); also elsewhere on the board
DTR: C39.1; also elsewhere on the board
EN_BUS_PRIME: IC1.26 ((PCINT23/TOSC2)PC7); also elsewhere on the board
EN_BUS_SEC: IC1.25 ((PCINT22/TOSC1)PC6); also elsewhere on the board
FAULT_PRIME: R57.1, U41.20 (GPA5); also elsewhere on the board
FAULT_SEC: R61.1, U41.6 (GPB6); also elsewhere on the board
FEATHER_CTS: IC1.31 ((PCINT6/ADC6)PA6); also elsewhere on the board
FEATHER_EN: U41.7 (GPB7); also elsewhere on the board
FEATHER_GPIO: IC1.32 ((PCINT5/ADC5)PA5); also elsewhere on the board
FEATHER_RTS: IC1.30 ((PCINT7/ADC7)PA7); also elsewhere on the board
GLOBAL_INT: IC1.33 ((PCINT4/ADC4)PA4), U41.14 (INTA)
GND: C40.1, C41.1, C42.2, IC1.6 (GND), IC1.18 (GND), IC1.28 (GND), IC1.39 (GND), IC1.TH (EXP), S4.1, S4.2, U41.11 (ADDR), U41.23 (VSS), U41.EP (VSS); also elsewhere on the board
GPIO_0: IC1.13 ((PCINT28/OC1B)PD4); also elsewhere on the board
GPIO_1: IC1.36 ((PCINT1/ADC1)PA1); also elsewhere on the board
GPIO_2: IC1.43 ((PCINT11/OC0A/AIN1)PB3); also elsewhere on the board
GPIO_3: IC1.35 ((PCINT2/ADC2)PA2); also elsewhere on the board
LBI: U41.3 (GPB3); also elsewhere on the board
LED1: IC1.14 ((PCINT29/OC1A)PD5); also elsewhere on the board
LED2: IC1.15 ((PCINT30/OC2B/ICP)PD6); also elsewhere on the board
LED3: IC1.16 ((PCINT31/OC2A)PD7); also elsewhere on the board
LOG_INT: IC1.34 ((PCINT3/ADC3)PA3); also elsewhere on the board
MISO: IC1.2 ((PCINT14/MISO)PB6); also elsewhere on the board
MOSI: IC1.1 ((PCINT13/MOSI)PB5); also elsewhere on the board
MPPT_CHRG: R55.1, U41.18 (GPA3); also elsewhere on the board
MPPT_FAULT: R56.1, U41.19 (GPA4); also elsewhere on the board
unnamed: R68.1, U41.15 (GPA0)
unnamed: C40.2, IC1.7 (XTAL2), XTAL1.OSC2 (2)
unnamed: C41.2, IC1.8 (XTAL1), XTAL1.OSC1 (1)
PG_LDO: R59.1, U41.1 (GPB1); also elsewhere on the board
RST: C39.2, IC1.4 (RESET), R52.1, S4.3 (4), S4.4 (3), U41.12 (!RESET); also elsewhere on the board
RTC_INT: IC1.42 ((PCINT10/INT2/AIN0)PB2); also elsewhere on the board
RX: IC1.9 ((PCINT24/RXD0)PD0); also elsewhere on the board
RX_EXT: IC1.11 ((PCINT26/INT0)PD2); also elsewhere on the board
SCK: IC1.3 ((PCINT15/SCK)PB7); also elsewhere on the board
SCL: IC1.19 ((PCINT16/SCL)PC0), U41.9 (SCL); also elsewhere on the board
SDA: IC1.20 ((PCINT17/SDA)PC1); also elsewhere on the board
SDA_CTRL: IC1.24 ((PCINT21/TDI)PC5); also elsewhere on the board
SDA_OB: U41.10 (SDA); also elsewhere on the board
SD_CD: IC1.41 ((PCINT9/CLKO/T1)PB1); also elsewhere on the board
SD_CS: IC1.44 ((PCINT12/OC0B/!SS!)PB4); also elsewhere on the board
TX: IC1.10 ((PCINT25/TXD0)PD1); also elsewhere on the board
TX_EXT: IC1.12 ((PCINT27/INT1)PD3); also elsewhere on the board
VUSB_POWER: R68.2; also elsewhere on the board
V_HP_SYNC: U41.5 (GPB5); also elsewhere on the board

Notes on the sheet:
Pin 12
Pin A7/31
Pin A6/30
Pin A5/29
Pin A4/28
Pin 15
Pin 23
Pin A3/27
Also ext PWM
Pin 19
Pin 14
Pin 13
Pin 3
Pin 2
Pin 1
Pin 4
Pin A0/24
Pin A1/25
Pin A2/26
Pin 20
Pin 11
Pin 10
Pin 9
Pin 8
Pin 16
Pin 17
Pin 18
Pin 21
Pin 22
Pin 0
Pin 5
Pin 6
Pin 7
Ext Int1
Ext Int0
Add: GPIO1 GPIO3
ADD: --MPPT, CHRG (Input) --MPPT, FAULT (Input) --MPPT, SHDN (Output) --Feather PowerOn (Output) --ADC, OnBoard, Alert/RDY (Input, Interrupt) --ADC, OffBoard, Alert/RDY (Input, Interrupt) --Vusb (Input) --LevelShifter, Primary Bus, EN (Output) --LevelShifter, Secondary Bus, EN (Output) --BMS, CTR (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
ADR=0x20

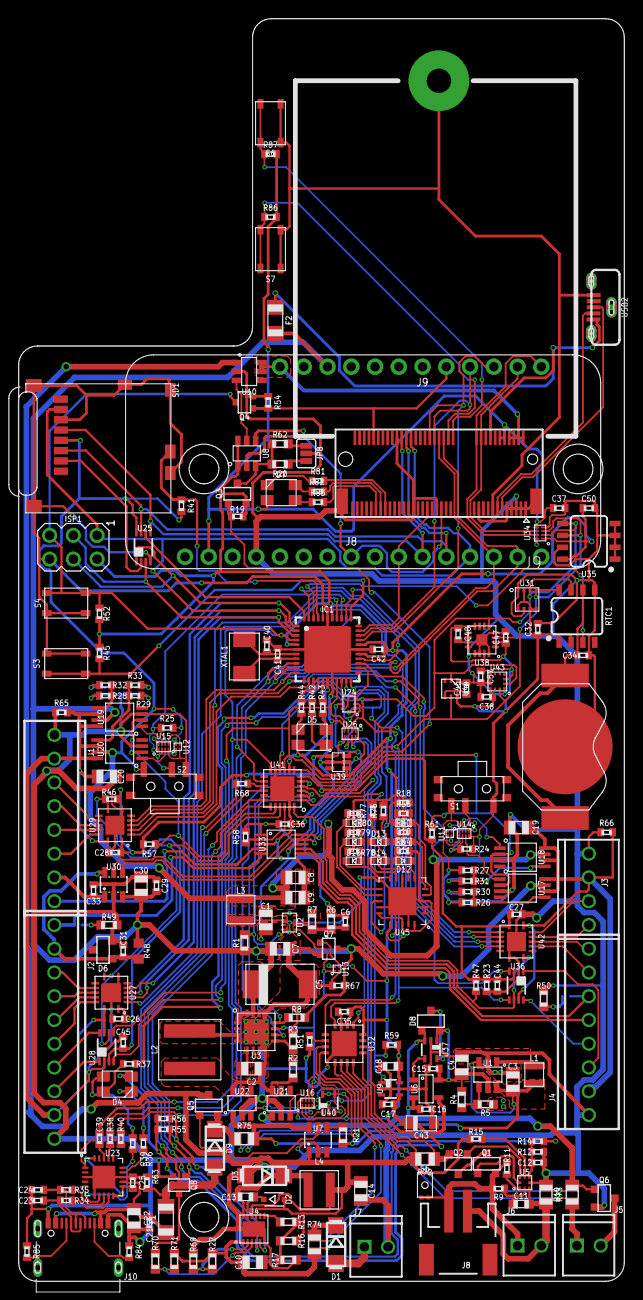
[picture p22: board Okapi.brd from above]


Board: 2 copper layers, 64.8 x 135.0 mm, 252 parts (8 on the bottom side), 207 nets.

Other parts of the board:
U$4: NWLOGO_MED

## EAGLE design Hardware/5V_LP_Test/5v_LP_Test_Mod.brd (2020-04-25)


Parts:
C1, C2, C3, C4: 10uF; C0805
C6: C-EUC0805; C0805
C7, C8: C-EUC0603; C0603
J1, J2, J3: CONN_3; 1X03
L1: 6.8uH; 1008; MPN 74438323068; DIGIKEY 732-4849-1-ND
L2: 6.8uH; 1008
L3: INDUCTORTPC_3.8X3.8; WE-TPC(3.8X3.8)
R1, R4: 1.62M; R0603
R2: 180K; R0603
R3, R6: R-EU_R0603; R0603
R5: 180k; R0603
U1, U2: TLV61220DBV; DBV_R-PDSO-G6
U3: TPS61070DDC; DDC_R-PDSO-G6

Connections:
GND: C3.2, C4.2, J1.2, R5.1, U1.2 (GND)
GND1: C1.2, C2.2, J2.2, R2.1, U2.2 (GND)
GND2: C6.2, C7.2, C8.2, J3.2, R6.1, U3.2 (GND)
unnamed: R1.1, R2.2, U2.4 (FB)
unnamed: L3.2, U3.1 (SW)
unnamed: L2.2, U2.1 (SW)
unnamed: R3.1, R6.2, U3.4 (FB)
unnamed: R4.1, R5.2, U1.4 (FB)
unnamed: L1.2, U1.1 (SW)
VIN: C3.1, J1.1, L1.1, U1.3 (EN), U1.6 (VBAT)
VIN1: C1.1, J2.3, L2.1, U2.3 (EN), U2.6 (VBAT)
VIN2: C6.1, J3.1, L3.1, U3.3 (EN), U3.6 (VBAT)
VOUT: C4.1, J1.3, R4.2, U1.5 (VOUT)
VOUT1: C2.1, J2.1, R1.2, U2.5 (VOUT)
VOUT2: C7.1, C8.1, J3.3, R3.2, U3.5 (VOUT)


Board: 2 copper layers, 18.5 x 32.0 mm, 22 parts (0 on the bottom side), 15 nets.

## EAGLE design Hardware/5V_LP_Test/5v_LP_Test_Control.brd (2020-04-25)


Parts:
C1, C2: 10uF; C0805
J2: CONN_3; 1X03
L1: 6.8uH; 1008
R1: 1.62M; R0603
R2: 180K; R0603
U1: TLV61220DBV; DBV_R-PDSO-G6

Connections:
GND: C1.2, C2.2, J2.2, R2.1, U1.2 (GND)
unnamed: R1.1, R2.2, U1.4 (FB)
unnamed: L1.2, U1.1 (SW)
VIN: C1.1, J2.3, L1.1, U1.3 (EN), U1.6 (VBAT)
VOUT: C2.1, J2.1, R1.2, U1.5 (VOUT)


Board: 2 copper layers, 12.7 x 10.1 mm, 7 parts (0 on the bottom side), 5 nets.

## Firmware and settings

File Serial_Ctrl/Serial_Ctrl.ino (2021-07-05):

#include <MCP23018.h>  //Include IO expander interface 
#include <DS3231.h>  //Include RTC interface
#include <BME.h>  //Include BME280 interface
#include <Adafruit_ADS1015.h> //Include ADC interface
#include <SD.h>  //Include SD interface
#include <SPI.h> //Include base SPI library
#include <MCP4725.h> //Include custom DAC interface 
#include <EEPROM.h>
#include <Wire.h> //Include base Wire library

//If a pin is defined as "0", it is allowed to be made an output, if pin is defined as a "1" is if forbidden to be defined as an output
// const uint32_t PinMask = 0b11100000101000001100000000011000; //Pin configuration mask for uC
// const uint16_t ExpPinMask = 0b1001110101011110; //Pin configuration mask for IO Expander
const uint16_t ExpPinMask = 0x00; //DEBUG!
const uint32_t PinMask = 0x00; //DEBUG!

MCP23018 IO(0x20); //Instatiate IO Expander
BME RH; //Instatiate BME280
MCP4725 DAC; //Instatiate DAC
Adafruit_ADS1115 ADC_OB(0x48); //Initialize on board (power moitoring) ADC
Adafruit_ADS1115 ADC_Ext(0x49);  //Initialize external (sensor) ADC


float BMEData[3] = {0}; //Storage for BME data, Temp, Pressure, RH //DEBUG??

boolean Debug = false; //FIX!!
char ReadArray[25] = {0};

const uint8_t C1 = 19; //Control pins for V_HP
const uint8_t C0 = 18;

const uint8_t EN_BUS_PRIME = 23;  //Power enable lines for buses
const uint8_t EN_BUS_SEC = 22;

const uint8_t GPIO[4] = {12, 25, 3, 26}; //GPIO pins 0~3, 0,1 on primary bus, 2,3 on secondary bus. 0 and 2 PWM capable

const uint8_t Global_Int = 28; //Global interrupt from IO Expander
const uint8_t Log_Int = 27; //Interrupt for logging event

////////////////////////////////////SD////////////////////////////////////////
const uint8_t SD_CS = 4; //Define chip select for SD card
char FileNameC[11]; //Used for file handling
boolean SD_Init = false;

////////////////////////////////////CLOCK//////////////////////////////////////
DS3231 Clock;

////////////////////////////////////////LED//////////////////////////////////
const uint8_t BuiltInLED = 20;
const uint8_t RED = 13;
const uint8_t GREEN = 15;
const uint8_t BLUE = 14;
const uint8_t RGB[] = {RED, GREEN, BLUE};

void setup() {
	Serial.begin(57600); //Initialize serial for general comunication
	Serial.println("Welcome to Resnik...");
	Serial.println("Developed by Dennis Nedry");
	Serial.print("Loading...\n\n");
	SetHP(1); //Turn on power via VBeta
	pinMode(BuiltInLED, OUTPUT);
	digitalWrite(BuiltInLED, LOW); //DEBUG!
	Wire.begin(); //Initialize base I2C library
	Serial.print("\tIO Exp... ");
	IO.begin(); //Initialize IO Expander
	Serial.println("Done");

	Serial.print("\tBME280... ");
	RH.begin(); //Initialize BME280
	Serial.println("Done");

	Serial.print("\tDAC... ");
	DAC.begin(0x62); //Intialize DAC
	Serial.println("Done");

	//ADD ADCS!!
	digitalWrite(BuiltInLED, HIGH); //DEBUG!
	Serial.println("Done");
	Serial.println("Enter When Ready...");
}

void loop() {
  static int ReadLength = 0;
  String ReadString;
  
  if(Serial.available() > 0) {
    char Input = Serial.read();

    if(Input != '\r') { //Wait for carrage return
      ReadArray[ReadLength] = Input;
      ReadLength++;
    }

    if(Input == '\r') {
      ReadString = String(ReadArray);
      ReadString.trim();
      memset(ReadArray, 0, sizeof(ReadArray));
      ReadLength = 0;
      
      if(ReadString == "Help") {
      	Serial.println("Commands:");
      	Serial.print(F("\tSD\n\tClock\n\tI2C\n\tADC Disp\n\tLED\n"));
      	Serial.print(F("\tSet HP\n\tSet Mode uC\n\tSet Pin uC\n\tRead Pin uC\n\tSet DAC\n\tRead ADC OB\n\tRead ADC Ext\n"));
      }

      if(ReadString == "SD") {
        Serial.println("\nTesting SD");
       	Serial.println("Please Wait...");
        String TestResult = bool2pf(TestSD());
        Serial.println(TestResult);
      }

      if(ReadString == "Clock") {
        Serial.println("\nTesting Clock");
       Serial.println("Please Wait...");
        String TestResult = bool2pf(TestClock());
        Serial.println(TestResult);
      }

      if(ReadString == "I2C") {
        Serial.println("\nI2C Test");
       Serial.println("Please Wait...");
        I2CTest();
        Serial.println("End");
      }

      if(ReadString == "ADC Disp") {
        Serial.println("\nBegin ADC Test");
        ADCDisp();
        Serial.println("...End ADC Test");
      }

      // if(ReadString == "IO") {
      //   Serial.println("\nIO Test");
      //   IOTest();
      //   Serial.println("End");
      // }

      // if(ReadString == "PG") {
      //   Serial.println("\nBegin PG Test");
      //   String TestResult = bool2pf(PGTest());
      //   Serial.print("PG: ");
      //   Serial.println(TestResult);
      // }

      // if(ReadString == "Power") { 
      //   Serial.println("\nPower Test");
      //   PowerTest();
      //   Serial.println("End");
      // }

      // if(ReadString == "Button") {
      //   Serial.println("\nBegin Button Test");
      //   ButtonTest();
      // }
      // Serial.println(ReadString); //DEBUG!
      // Serial.println(ReadString.indexOf("TEST")); //DEBUG!
      if(ReadString.indexOf("Set HP") >= 0) {
      	SetHP(ReadString.substring(6).toInt()); //Pass int to function
      }

      if(ReadString.indexOf("Set Mode uC") >= 0) { //"Pin Mode uC xx y", xx is pin position (0 ~ 32), y is direction (0 ~ 1)
      	// Serial.println(ReadString.substring(13).toInt()); //DEBUG!
      	// Serial.println(ReadString.indexOf(",")); //DEBUG!
      	SetPinMode(ReadString.substring(11).toInt(), ReadString.substring(ReadString.indexOf(",") + 1).toInt()); //Pass int to function
      }

      if(ReadString.indexOf("Set Mode IO") >= 0) { //"Pin Mode uC xx y", xx is pin position (0 ~ 32), y is direction (0 ~ 1)
      	SetPinModeIO(ReadString.substring(11).toInt(), ReadString.substring(ReadString.indexOf(",") + 1).toInt()); //Pass int to function
      }

      if(ReadString.indexOf("Set Pin uC") >= 0) { //"Set uC Pin xx y", xx is pin position (0 ~ 32), y is value (0 ~ 1)
      	// Serial.println(ReadString.substring(ReadString.indexOf(",")).toInt()); //DEBUG!
      	// Serial.println(ReadString.substring(ReadString.indexOf(","))); //DEBUG!
      	// Serial.println(ReadString.substring(ReadString.indexOf(",") + 1).toInt()); //DEBUG!
      	DigitalWrite(ReadString.substring(10).toInt(), ReadString.substring(ReadString.indexOf(",") + 1).toInt()); //Pass int to function
      }

      if(ReadString.indexOf("Set Pin IO") >= 0) { //"Set IO Pin xx y", xx is pin position (0 ~ 32), y is value (0 ~ 1)
      	DigitalWriteIO(ReadString.substring(10).toInt(), ReadString.substring(ReadString.indexOf(",") + 1).toInt()); //Pass int to function
      }

      if(ReadString.indexOf("Read Pin uC") >= 0) { //"Set uC Pin xx", xx is pin position (0 ~ 32)
      	DigitalRead(ReadString.substring(11).toInt()); //Pass int to function
      }

      if(ReadString.indexOf("Read Pin IO") >= 0) { //"Set uC Pin xx", xx is pin position (0 ~ 32)
      	DigitalReadIO(ReadString.substring(11).toInt()); //Pass int to function
      }

      if(ReadString.indexOf("Read ADC OB") >= 0) { //"Read ADC OB xx", xx is pin position (0 ~ 3)
      	ReadADC(ReadString.substring(11).toInt()); //Pass int to function
      }

      if(ReadString.indexOf("Read ADC Ext") >= 0) { //"Read ADC OB xx", xx is pin position (0 ~ 3)
      	ReadADCExt(ReadString.substring(12).toInt()); //Pass int to function
      }

      if(ReadString.indexOf("Set DAC") >= 0) { //"Set DAC x.x...", x.x is voltage value 
      	SetDAC(ReadString.substring(7).toFloat()); //Pass float to function
      }

      if(ReadString == "LED") {
        Serial.println("\nLED Test");
        LEDTest();
        Serial.println("End");
      }

      if(ReadString == "SN Set") {
        char Data[5] = {0};
        while(Serial.available() > 0) {
          int x = Serial.read();
        }

        Serial.print("Enter Board Type... ");
        while(Serial.available() == 0);
        String DeviceIDStr = Serial.readString();
        DeviceIDStr.toCharArray(Data, 5);
        uint16_t DeviceID = (int)strtol(Data, NULL, 16);
        Serial.println(DeviceID, HEX);

        Serial.print("Enter Group ID... ");
        while(Serial.available() == 0);
        String GroupIDStr = Serial.readString();
        GroupIDStr.toCharArray(Data, 5);
        uint16_t GroupID = (int)strtol(Data, NULL, 16);
        Serial.println(GroupID, HEX);

        Serial.print("Enter Unique ID... ");
        while(Serial.available() == 0);
        String UniIDStr = Serial.readString();
        UniIDStr.toCharArray(Data, 5);
        uint16_t UniID = (int)strtol(Data, NULL, 16);
        Serial.println(UniID, HEX);

        int Location = EEPROM.length() - 8;
        
        boolean Fault = false;
        uint16_t FirmwareID = 0x0000;
         uint16_t SerialNumber[] = {DeviceID, GroupID, UniID, FirmwareID}; 

         for(int i = 0; i < 4; i++) { 
            EEPROM.write(Location, (SerialNumber[i] & 0xFF00) >> 8);
            EEPROM.write(Location + 1, SerialNumber[i] & 0xFF);
            Location += 2;
          }
       Location = EEPROM.length() - 8;
       
       for(int i = 0; i < 4; i++) {
          if( EEPROM.read(Location) != (SerialNumber[i] & 0xFF00) >> 8 || EEPROM.read(Location + 1) != (SerialNumber[i] & 0xFF)){
            Fault = true;
          }
          Location += 2;
       }
      
       if(Fault == true){
        Serial.println("CRITICAL ERROR: Readback Failed, try again");
       }
       
       else{
        Serial.println("\n...Serial Number Write Completed Without Errors.");
       }
      }

      if(ReadString == "SN Read") {
        int Location = EEPROM.length() - 8;
        for(int i = 0; i < 8; i++) {
          Serial.println(EEPROM.read(Location + i), HEX);
       }
      }

      if(ReadString == "ItsAUnixSystem") {
       Serial.println("\nDebuging Output Enabled!");
       Serial.println("Careful not to turn all the fences off...");
        Debug = true;
      }
    }
	}
}

void SetPinMode(uint8_t Pin, bool State)  //Set the pin mode of an onboard pin
{
	//Add check for pin range!
	if(State == INPUT || (State == OUTPUT && ((PinMask >> Pin) & 0x01) == 0)) {  //Proceed only if input, or output AND mask allows for output
		pinMode(Pin, !State);  //Arduino for some reason used inverse logic for OUTPUT and INPUT... *sigh*
 		Serial.print("uC Pin ");
		Serial.print(Pin);
		if(State == 0) Serial.println(" Set as Output");
		if(State == 1) Serial.println(" Set as Input");
	}
	else Serial.println("Pin Direction Error!");
}

bool SetPinModeIO(uint8_t Pin, bool State)  //Set the pin mode of a pin on the IO expander
{
	//Add check for pin range!
	if(State == INPUT || (State == OUTPUT && ((ExpPinMask >> Pin) & 0x01) == 0)) {  //Proceed only if input, or output AND mask allows for output
		IO.PinMode(Pin, State, 0); // Will only check Port 0 for now
		// IO.PinMode(Pin, State, 1); // ????
		Serial.print("IO Exp Pin ");
		Serial.print(Pin);
		if(State == 0) Serial.println(" Set as Output");
		if(State == 1) Serial.println(" Set as Input");
	}
	else Serial.println("Pin Direction Error!");
}

void DigitalWrite(uint8_t Pin, bool State) //Set the state of a pin on the uC
{
	if(((PinMask >> Pin) & 0x01) == 1) Serial.println("Pin Direction Error!"); //Pin is not configurable as output
	else {
		digitalWrite(Pin, State, 0); //Set pin state, Port 0
		Serial.print("uC Pin ");  //Print Status
		Serial.print(Pin);
		Serial.print(" Set to ");
		Serial.println(State);
	}
}

void DigitalWriteIO(uint8_t Pin, bool State)
{
	if(((ExpPinMask >> Pin) & 0x01) == 1) Serial.println("Pin Direction Error!"); //Pin is not configurable as output
	else {
		IO.DigitalWrite(Pin, State); //Set pin state
		Serial.print("IO Pin ");  //Print Status
		Serial.print(Pin);
		Serial.print(" Set to ");
		Serial.println(State);
	}
}

void DigitalRead(uint8_t Pin)
{
	Serial.print("uC Pin ");  //Print Status
	Serial.print(Pin);
	Serial.print(" Value is ");
	Serial.println(digitalRead(Pin));
}

void DigitalReadIO(uint8_t Pin)
{
	Serial.print("IO Pin ");  //Print Status
	Serial.print(Pin);
	Serial.print(" Value is ");
	Serial.println(IO.DigitalRead(Pin));
}

void ReadADC(uint8_t Pin) 
{
	//Check pin??
	Serial.print("ADC OB, ");
	Serial.print(Pin); 
	Serial.print(" = ");
	Serial.print(ADC_OB.readADC_SingleEnded(Pin)*0.1875, 5);
	Serial.println("mV");
}

void ReadADCExt(uint8_t Pin)
{
	Serial.print("ADC Ext, ");
	Serial.print(Pin); 
	Serial.print(" = ");
	Serial.print(ADC_Ext.readADC_SingleEnded(Pin)*0.1875, 5);
	Serial.println("mV");
}

void SetDAC(float Val)
{
	uint16_t BitVal = floor((Val/5.0)*4096); //Convert to bit respresentaiton
	DAC.setVoltage(BitVal, false); //set DAC, do not store result in EEPROM (false flag)
	Serial.print("DAC Output Set To ");
	Serial.println(Val, 4);
	if(Debug) Serial.println((BitVal/4096)*5.0, 4); //Print actual (nearest) value 
}

void SetHP(int State)  //-1 off, 0 off, 1 VBeta, 2 VPrime
{
	pinMode(C0, OUTPUT); //Set as outputs, if not already
	pinMode(C1, OUTPUT);
	Serial.print("High Power Status: ");
	switch(State){
		case -1:  //Turn off power
//      pinMode(16, OUTPUT);
//      pinMode(17, OUTPUT);
//      
//      pinMode(16, LOW);
//      pinMode(17, LOW);
			Serial.println(" OFF");
			digitalWrite(C0, HIGH);
			digitalWrite(C1, HIGH);
			break;

		case 0:  //Turn off power
//      pinMode(16, OUTPUT);
//      pinMode(17, OUTPUT);
//      
//      pinMode(16, LOW);
//      pinMode(17, LOW);
			Serial.println(" OFF");
			digitalWrite(C0, LOW);
			digitalWrite(C1, LOW);
			break;

		case 1:  //Turn on VBeta 
			Serial.println(" VBeta");
			digitalWrite(C0, LOW);
			digitalWrite(C1, HIGH);
			break;

		case 2:  //Turn on VPrime 
			Serial.println(" VPrime");
			digitalWrite(C0, HIGH);
			digitalWrite(C1, LOW);
			break;

		default:  //Turn off by default 
//      pinMode(16, OUTPUT);
//      pinMode(17, OUTPUT);
//      
//      pinMode(16, LOW);
//      pinMode(17, LOW);
			Serial.println(" OFF");
			digitalWrite(C0, LOW);
			digitalWrite(C1, LOW);
			break;
	}
}

void LEDTest() {
  //Initalize LEDs and set all off
  pinMode(BuiltInLED, OUTPUT);
  digitalWrite(BuiltInLED, HIGH);
  for(int p = 0; p < 3; p++){
    pinMode(RGB[p], OUTPUT);
    digitalWrite(RGB[p], HIGH);
  }
  
  while(Serial.read() != '\r'){
//    bool State = false;
    for(int i = 0; i < 3; i++){
      digitalWrite(RGB[i], LOW);
      delay(1000);
//      State = !State;
      digitalWrite(RGB[i], HIGH);
      delay(1000);
    }
    digitalWrite(BuiltInLED, LOW);
    delay(1000);
    digitalWrite(BuiltInLED, HIGH);
    delay(1000);
  }
}

void ADCDisp(){ 
	Serial.println("IN DEVELOPMENT!");
    // while(Serial.read() != '\r'){
    //   Serial.print("Ref = "); 
    //   Serial.print(analogRead(VRef_Pin)*(3.3/1024.0));
    //   Serial.println(" V");

    //   Serial.print("Therm = "); 
    //   Serial.print(analogRead(ThermSense_Pin)*(3.3/1024.0));
    //   Serial.println(" V");

    //   Serial.print("Bat = "); 
    //   Serial.print(analogRead(BatSense_Pin)*(3.3/1024.0)/10.0);
    //   Serial.println(" V");

    //   Serial.print("Ax = "); 
    //   Serial.print(adc.GetVoltage()*(3.3/1024.0));
    //   Serial.println(" V");

    //   Serial.print("\n\n");
    // }
}

void I2CTest() {
  byte error, address;
  int nDevices;

  Serial.println("Scanning...");

  nDevices = 0;
  for(address = 1; address < 127; address++ ) 
  {
    Wire.beginTransmission(address);
    error = Wire.endTransmission();

    if (error == 0)
    {
      Serial.print("I2C device found at address 0x");
      if (address<16) 
        Serial.print("0");
      Serial.print(address,HEX);
      Serial.println("  !");

      nDevices++;
    }
    else if (error==4) 
    {
      Serial.print("Unknow error at address 0x");
      if (address<16) 
        Serial.print("0");
      Serial.println(address,HEX);
    }    
  }
  if (nDevices == 0)
    Serial.println("No I2C devices found\n");
  else
    Serial.println("done\n");
}

boolean TestSD()
{
  boolean SDError = false;
  pinMode(SD_CS, OUTPUT);
  SPI.setDataMode(SPI_MODE0);
  SPI.setClockDivider(SPI_CLOCK_DIV2); //Sts SPI clock to 4 MHz for an 8 MHz system clock

  if(!SD_Init) {
  if (!SD.begin(SD_CS)) {
    if(Debug) Serial.println("Failed Init");
    SDError = true; 
    return SDError;
  }
  if(Debug) Serial.println("Initialized");
  SD_Init = true;
  }
  String FileName = "HWTest";
  (FileName + ".txt").toCharArray(FileNameC, 11);
  SD.remove(FileNameC); //Remove any previous files
  
  randomSeed(millis()); //Seed with a random number to try to endsure randomness
  int RandVal = random(30557); //Generate a random number between 0 and 30557 (the number of words in Hamlet)
  char RandDigits[5] = {0};
  sprintf(RandDigits, "%d", RandVal); //Convert RandVal into a series of digits
  int RandLength = (int)((ceil(log10(RandVal))+1)*sizeof(char)); //Find the length of the values in the array
  // Serial.print("Random Digits:"); //DEBUG!
  // for(int p = 0; p < 5; p++) { //DEBUG!
  //   Serial.print(RandDigits[p]);
  // }
  // Serial.println(""); //DEBUG!

  File DataWrite = SD.open(FileNameC, FILE_WRITE);
  if(DataWrite) {
    DataWrite.println(RandVal);
    DataWrite.println("\nHe was a man. Take him for all in all.");
    DataWrite.println("I shall not look upon his like again.");
    DataWrite.println("-Hamlet, Act 1, Scene 2");
  }
  DataWrite.close();

  if(Debug){
    Serial.print("Random Value = "); Serial.println(RandVal);
  }
  
  char TestDigits[5] = {0};
  File DataRead = SD.open(FileNameC, FILE_READ);
  if(DataRead) {
    DataRead.read(TestDigits, RandLength);

    if(Debug){
      Serial.print("Recieved Value = ");
    }
    for(int i = 0; i < RandLength - 1; i++){ //Test random value string
      if(Debug) Serial.print(TestDigits[i]);
      if(TestDigits[i] != RandDigits[i]) {
        SDError = true;
        Serial.print("x"); //DEBUG!
        Serial.print(RandDigits[i]);
      }
    }
    if(Debug) Serial.println("");
  
    if(Debug) {
      Serial.println("SD Test Data:");
      while(DataRead.available()) {
        Serial.write(DataRead.read());
      }
    }
  }
  DataRead.close();

  

  if(Debug) Serial.println("");
  
  return SDError;
}

boolean TestClock()
{
  boolean ClockError = false;
  boolean DumbFalse = false;
  Clock.setClockMode(false);  // set to 24h
  byte DateSet[] = {63, 4, 5, 4, 20, 0, 0};
  byte DateRead[7] = {0};
  
  Clock.setYear(DateSet[6]);
  Clock.setMonth(DateSet[5]); 
  Clock.setDate(DateSet[4]);
  Clock.setDoW(DateSet[3]); //Thursday?
  Clock.setHour(DateSet[2]);
  Clock.setMinute(DateSet[1]);
  Clock.setSecond(DateSet[0]);

  delay(5000);

  DateRead[6] = Clock.getYear();
  DateRead[5] = Clock.getMonth(DumbFalse);
  DateRead[4] = Clock.getDate();
  DateRead[3] = Clock.getDoW();
  DateRead[2] = Clock.getHour(DumbFalse, DumbFalse);
  DateRead[1] = Clock.getMinute();
  DateRead[0] = Clock.getSecond();
  
  for(int i = 6; i > 0; i--){
    if(DateRead[i] != DateSet[i]) ClockError = true;
  }
    if(DateRead[0] != DateSet[0] + 5 && DateRead[0] != DateSet[0] + 4 && DateRead[0] != DateSet[0] + 6) ClockError = true;

  if(Debug) {
    Serial.println("Values Read:");
    Serial.print("Year = "); Serial.print("20"); Serial.println(DateSet[6]);
    Serial.print("Month = "); Serial.println(DateSet[5]);
    Serial.print("Day = "); Serial.println(DateSet[4]);
    Serial.print("DoW = "); Serial.println(DateSet[3]);
    Serial.print("Hour = "); Serial.println(DateSet[2]);
    Serial.print("Minute = "); Serial.println(DateSet[1]);
    Serial.print("Second = "); Serial.println(DateSet[0]);
    
    Serial.println("\nValues Read:");
    Serial.print("Year = "); Serial.print("20"); Serial.println(DateRead[6]);
    Serial.print("Month = "); Serial.println(DateRead[5]);
    Serial.print("Day = "); Serial.println(DateRead[4]);
    Serial.print("DoW = "); Serial.println(DateRead[3]);
    Serial.print("Hour = "); Serial.println(DateRead[2]);
    Serial.print("Minute = "); Serial.println(DateRead[1]);
    Serial.print("Second = "); Serial.println(DateRead[0]);
    Serial.println("");
  }
  return ClockError;

  //Test alarms??
}

String bool2pf(boolean TestResult){
  if(TestResult) return "FAIL";
  return "PASS";
}

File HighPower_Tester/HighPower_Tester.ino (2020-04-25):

//MargayDemo.ino
#include "Resnik.h"
#include <BME.h>

BME RH; //Initialzie BME280

String Header = ""; //Information header
uint8_t I2CVals[1] = {0x77}; 
// int Count = 0;
unsigned long UpdateRate = 5; //Number of seconds between readings 

Resnik Logger;

void setup() {
  Header = Header + RH.GetHeader();
  Logger.begin(I2CVals, sizeof(I2CVals), Header); //Pass header info to logger
  Init();
}

void loop() {
  Logger.Run(Update, UpdateRate);
//  Logger.AddDataPoint(Logger.GetOnBoardVals());
//  Serial.println(Logger.GetOnBoardVals());
//  delay(100);
}

String Update() 
{
  Init();
  delay(3000);
  return RH.GetString();
//return "x";
}

void Init() 
{
  RH.begin(0x77);
}

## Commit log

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2018-10-23 Created schematic and board, beginning ECAD population
    [Resnik.brd, Resnik.sch]
2018-10-25 Continued schematic additions, prelim part placement
    [Resnik.brd, Resnik.sch]
2018-10-26 Preliminary power section layout
    [Resnik.brd, Resnik.sch]
2018-10-27 Continued layout, board size change
    [Resnik.brd, Resnik.sch]
2018-10-29 Continued layout, major of power and prime bus done
    [Resnik.brd, Resnik.sch]
2018-10-30 Continued layout, majority of secondary bus, low power
    [Resnik.brd, Resnik.sch]
2018-10-30 Continued layout, starting on SD and Feather header
    [Resnik.brd, Resnik.sch]
2018-11-01 Layout tentative completed, sent to DFM check
    Layout complete for v0.0, pending final triple check, sent to DFM check to verify manufacture issues. Ready for final external review.
    [Resnik.brd, Resnik.sch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]
2018-11-01 Added PDFs of prelim v0.0 schematic
    [Resnik.sch]
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2018-11-02 Minor board edits, updated gerbers, pending DFM
    [Resnik.brd, Resnik.sch]
2018-11-07 Updated BOM info
    Added info to schematic to support auto-generating BOM
    [Resnik.brd, Resnik.sch]
2018-11-10 Added very early RockBlock breakout
    [RockBlock_Breakout.sch]
2018-11-13 Preliminary layout of RockBlock Breakout
    Still needs cleanup and some verification
    [RockBlock_Breakout.brd, RockBlock_Breakout.sch]
2018-11-13 Aligned buttons on RockBlock breakout
    [RockBlock_Breakout.brd]
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2018-11-19 Updated inductor L2 layout
    Fixed size and part number of inductor to match XHMI layout
    [Resnik.brd, Resnik.sch]
2018-11-20 First round of fixes to hardware
    changed SD card holder, power switches, power switch topology, add pull up resistors to IO expander, to allow for new non-internal pull up module, added some silkscreen, added 3v3 core I2C pullups
    [Resnik.brd, Resnik.sch]
2018-11-20 Layout fixes
    Improvements and cleanup in the layout, should get final review before being sent out to fab
    [Resnik.brd]
2018-11-26 Generated Gerbers, Minor Updates
    v0.1 Sent to fab
    [Resnik.brd]
2018-11-29 Added dimensions, updated part numbers
    [Resnik.brd, Resnik.sch]
2018-11-30 Fixed part value for TCA9555 (to TCA9535)
    [Resnik.brd, Resnik.sch]
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2019-01-10 Fixed MPPT set resistors
    Fixed the order of the MPPT voltage set resistors. Correct values were used, but in the wrong orientation, this has been corrected
    [Resnik.brd, Resnik.sch]
2019-01-19 Fixed message format in `Serial_Ctrl`
    [Serial_Ctrl.ino]
2019-02-07 Added 5v LP control test board
    [5v_LP_Test_Control.brd, 5v_LP_Test_Control.sch]
2019-02-08 Added 5v LP modified test board
    [5v_LP_Test_Mod.brd, 5v_LP_Test_Mod.sch]
2019-02-09 Initial schematic updated for v0.2
    First round of updates to schematic for v0.2 update, needs verification before layout begins
    [Resnik.brd, Resnik.sch]
2019-02-12 Initial layout update for v0.2
    Layout mainly complete, review required, need to delete some extraneous parts
    [Resnik.brd, Resnik.sch]
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2019-02-12 Removed extraneous protection circuit
    Removed deprecated MOSFET protection circuit on ADC
    [Resnik.brd, Resnik.sch]
2019-02-14 Updated test boards for VolteraV1
    Attempted to maximize compatibility with Voltera V1 system
    [5v_LP_Test_Control.brd, 5v_LP_Test_Mod.brd]
2019-02-16 Updates to 5v test board
    Added additional converter to 5v test setup, also condensed all units onto a single board and generated gerbers for compatibility with Sunstone PCB
    [5v_LP_Test_Mod.brd, 5v_LP_Test_Mod.sch]
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2019-03-14 Minor cleanup
    Top layer checked and verified, bottom layer still needs cleanup and verification, also update version number!
    [Resnik.brd]
2019-03-16 Minor cleanup and gerber generation, ready for v0.2
    [Resnik.brd, Resnik.sch]
2019-03-21 Improved paste layout, generated stencil gerbers
    Updated the paste distribution on several parts, generated gerbers for the stencil
    [Resnik.brd, Resnik.sch]
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2019-06-06 Initial updates for v0.3
    Additional routing required, need to add ADC switch enable, need to add efficiency modification to mppt
    [Resnik.brd, Resnik.sch]
2019-06-06 Layout updates, cleanup required, minor testing
    [Resnik.brd, Resnik.sch]
2019-06-06 Continued layout, generated gerbers
    Improved layout, generated gerbers, final design review before send to fab
    [Resnik.brd, Resnik.sch]
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2019-08-13 Hardware fixes, review and verification required, gerber generated
    Gerber generated and sent to DFM, verification and review required
    [Resnik.brd, Resnik.sch]
2019-08-14 Silk screen edits, generated gerbers, v0.4 send to fab
    [Resnik.brd]
2019-08-14 Minor value changes, generated BoM for quote generation
    [Resnik.brd, Resnik.sch, Resnik_BOM.csv]
2019-08-22 Added Ref ID images, updated BoM for new parts, added pick and place
    [Resnik.brd, Resnik.sch, Resnik_v04_BoM.csv]
2019-11-02 Added reference designators, cleanup
    [Resnik.brd, Resnik.sch, Resnik_v04_BoM.csv]
2020-02-13 Update to fix issue #6, start of v0.5
    Fixed battery parasitic draw into ADC issue be connecting ADC to battery through protection circuit, preventing the parasitic draw from discharging the battery below the UVLO voltage
    [Resnik.brd, Resnik.sch]
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2020-04-25 Current BoM only; no versions in file names
    [Resnik_BOM.csv, Resnik_BoM.csv]
2020-04-25 5V_LP_Test board to subdirectory
    [5v_LP_Test_Control.brd, 5v_LP_Test_Control.sch, 5v_LP_Test_Mod.brd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]
2020-04-30 Battery mount and strap (primary AA)
    [BatteryMount_LargeBox.SLDPRT, BatteryMount_LargeBox.STL, BatteryMount_Strap.SLDPRT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]
2020-04-30 PolyCase P/N for fitting box
    [BatteryMount_WH10.SLDPRT, BatteryMount_WH10.STL]
2020-05-03 Label all jumpers: text and diagrams
    [Resnik.brd, Resnik.sch]
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2020-10-02 Added Mounting Plate drawings
    [Resnik Mounting Plate.dwg]
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2020-10-03 Updated mounting plate drawings
    Updated mounting plate drawings to account for battery packs rotated 90 degrees, Resnik board centered.
    [Resnik Mounting Plate.dwg]
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2020-10-26 Rename Mounting Plate.step to Resnik Mounting Plate v1.3.step
    [Resnik Mounting Plate v1.3.step]
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2020-11-01 AA backup battery box (x3, 3D print files)
    [BatteryMount_LargeBox.SLDPRT, BatteryMount_LargeBox.STL, BatteryMount_LargeBox.step]
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2020-11-01 Update to Resnik large-box small-holder with countersunk screw holes
    [BatteryMount_LargeBox.SLDPRT, BatteryMount_LargeBox.STL]
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2026-06-03 Large-box battery mount with strap: used in deployments.
    [BatteryMount_LargeBox.3mf, BatteryMount_Strap.3mf]
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2026-06-03 README: add version to photo captions
    All three board photos are of the Resnik v0.4.0 hardware; captions
    now say so to avoid confusion with the current v1.0 design.
2026-06-03 Add KiCad imports of Okapi Eagle schematic/board
    KiCad-v7import/: automated Eagle→KiCad 7.0 import (unmodified)
    Hardware/KiCAD-10import/: automated Eagle→KiCad 10.0 import (unmodified)
    Both imports have known issues documented in the conversion review:
    - P+ supply symbols converted to generic VCC instead of 3V3_AUX/3V3_CORE
    - V_CORE net label missing from schematic
    - QOD net label should be FEATHER_BAT
    - SIM_VCC/UB_VBUS are unconnected pins converted to global labels
    [Okapi.kicad_pcb, Okapi.kicad_sch, Okapi_1.kicad_sch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]
2026-06-03 KiCAD-10import: fix power net and label errors from Eagle import
    - Okapi_2: P+1-4,6-9 → 3V3_AUX; P+5,P+10 → 3V3_CORE (were all VCC)
    - Okapi_3: SUPPLY9,SUPPLY10 → 3V3_CORE (were VCC)
    - Okapi_5: P+11 → 3V3_AUX (was VCC)
    - Okapi_2: QOD global labels → FEATHER_BAT (Eagle net name)
    - Okapi root: add V_CORE net label on U6-OUT/U9-VIN/C17/C43 wire
    The Eagle→KiCad importer assigns all P+/SUPPLY power symbols the
    generic "VCC" net regardless of the actual net they sit on in Eagle.
    The correct rail assignments were traced from the Eagle netlist.
    [Okapi.kicad_sch, Okapi_2.kicad_sch, Okapi_3.kicad_sch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]
2026-06-03 KiCAD-10import: mark B-Series SIM and UB_USB pins as no-connect
    All four external SIM interface pins (SIM_VCC, SIM_CLK, SIM_DATA,
    SIM_RST) and the UB USB interface pins (UB_VBUS, UB_USB_N, UB_USB_P)
    are intentionally unconnected: the B-Series uses its onboard eSIM
    and the secondary USB-to-modem interface is not needed.
    Removes the stray global labels that the KiCad importer created
    from these unconnected pins, and replaces them with proper
    no-connect markers on J9.
    [Okapi_3.kicad_sch]

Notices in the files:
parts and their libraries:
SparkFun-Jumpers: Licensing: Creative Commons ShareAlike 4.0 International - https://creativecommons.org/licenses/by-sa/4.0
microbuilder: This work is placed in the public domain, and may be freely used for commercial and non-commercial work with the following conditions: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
